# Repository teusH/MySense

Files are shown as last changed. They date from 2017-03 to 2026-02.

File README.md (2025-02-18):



# MySense
Last update of the README on 2nd of Februar 2020

## Description
Software Infrastructure or framework for managing environmental sensors and data aquisition.

This is WORK IN PROGRESS!
All available Python3 scripts/modules are tested standalone as alpha tests and with some real life examples.
In this alpha phase one is recommanded to test and improve the modules before it is taken fully operational.
One is invited to comment on functionality, improvements, and higher level modules to use this library module set.

Be aware that there are discussions going on to change the IoT website query interface and website query implementation of the Samen Meten API.

### Outline
A description of the MySense PyCom based measurement kit, data collection and data visualisation is provided in a presentation at Meetkoppelting20 conference in Amersfoort, Jan 2020. The PDF slides can be found at <a href=""http://behouddeparel.nl/sites/behouddeparel.nl/files/20200125-Koppelting-WAR-Amersfoort.pdf" alt="an How To build a kit and show the results">"Measuring Air Quality in an Agri Region: an How To"</a> (PDF 3 MB).

### Licensing
   Open Source Initiative  https://opensource.org/licenses/RPL-1.5
   Unless explicitly acquired and licensed from Licensor under another
   license, the contents of this file are subject to the Reciprocal Public
   License ("RPL") Version 1.5, or subsequent versions as allowed by the RPL,
   and You may not copy or use this file in either source code or executable
   form, except in compliance with the terms and conditions of the RPL.

   All software distributed under the RPL is provided strictly on an "AS
   IS" basis, WITHOUT WARRANTY OF ANY KIND, EITHER EXPRESS OR IMPLIED, AND
   LICENSOR HEREBY DISCLAIMS ALL SUCH WARRANTIES, INCLUDING WITHOUT
   LIMITATION, ANY WARRANTIES OF MERCHANTABILITY, FITNESS FOR A PARTICULAR
   PURPOSE, QUIET ENJOYMENT, OR NON-INFRINGEMENT. See the RPL for specific
   language governing rights and limitations under the RPL.

### MySense datacollector (Linux systems)
The first station we build with RPi, gas, temperature, RHG and dust sensors looked like this:


MySense is able to act as *air quality measurement kit* or *node broker* (Pi based).
As measurement kit MySense will collect measurements from dust,
gas and/or gas sensors and location sensor,
and forward the data to an external data concentrator(s) (database(s), as well as data broker as eg mosquitto and influx),
files eg spreadsheets,
and display (Adafruit tiny display or console).

As dataconcentrator MySense will connect to other data concentrator instead of collecting the data from sensors.

Two different controllers for the kits are supported:
1. Raspberry Pi for a high degree of functionality and easy block building reasons, while using lan/wifi/G4 as communication channel and
2. ESP32 LoPy controller (micro python) from PyCom when only a very few sensors can be hooked up. This kit uses LoRaWan as communication infrastructure via a public TTN server.
This measurement kit is in beta test since June 2019. The PyCom folder will show latest firmware snapshot.

The bus used for sensors are: USB (Pi: serial), TTL, GPIO (SPI) and I2C.
The scripts are all written in Python 2/3.

Visual feedback is provided with led/button (power On/Off) and optional an Oled display (64X128).

### MySense LoPy-4 PyCom controller




MySense sensor kits can also be applied as *air quality satellite* sensorkits. E.g. using LoPy or WiPy PyCom controllers with GPS, dust and meteo sensors.
In this case the data will be forwarded to <a href="https://www.thethingsnetwork.org/docs/lorawan/">LoRaWan</a> dataconcentrators as eg The Things Network or Mosquitto server.
The LopY has support for SiGFox (due to proprietary chracter of this method it has been deprecated).
The upload of uptaes to the firmware via PyCom OTA is planned.
Currently OTA (Over the Air update) is supported via a new firmware load via wifi.

MySense (Pi based) in data concentrator mode has the possiblity to collect these measurements data from e.g. the TTN MQTT dataconcentrator.

The bus used for sensors are: UART (serial), I2C and GPIO.

The scripts are written in (embedded) micro Python. Micro python has more functionality as the language C e.g. used with Arduino boards.

The Marvin ESP controller has been deprecated due to a problem with on board LoRa antenna in outdoor conditions.

Visual feedback is provided with RGB led and optional an 128X64 oled display.

The LoPy based measurement kit supports to run with a solarcel and accu. For enabling this the architecture has had a major redesign. The softwqare manages accu load as well tries to minimilize energy as much as possible.

The LoRa directory will give information to build a DIY TTN LoRa gateway.

The `INSTALL.sh` RPi configuration script will support to install GPS, oled display, RGB led, WiFi remote access, G4 access and other standard functionality to a Raspberry Pi based gateway e.g. RAK831, RAK833 or IC880a-PSI and Pi based gateway for a small budget TTN gateway.
Have a look at the RAK7258 LoRa gateway. A complete (indoor and outdoor) gateway for about €140 (AliExpress). As such providing you with more functionality as commercial offered gateways without a subscription fee.
If needed use a (€ 40) SIM router to connect the gateway to mobile data access.

At this moment we have 20 measurements MySense LoRa kits in the region running.
Seven kits run with solar cells around a cattle enterprise. The entrepeneur uses the outcome of data to minimize the emissions.

## Goal
Provide a generalised dynamic high quality Open Source based air quality monitoring infrastructure to allow:
* environmental measurements with high end standard off the shelf sensors
* data acquisition
* dynamic transport of data to other data systems: e.g. databases, mosquitto, Influx,...
* data storage and archiving
* access for free visualisation of local emissions
* free availability  of the data
* free availability of all software (under GPLV3 or Open Source reciprocal license, improvements of software remains in the public domain)

The project is run by volunteers on a non-profit basis.

## Supported functionalities
Major functionalities will be added on the fly.
Much is dependent on the quality of the applied sensors and visualisation possibilities of the data.
* supported dust sensors: Nova (only PM2.5, PM10), Plantower (PM1, PM2.5, PM10, counters PM0.3 up to PM10, average grain size, advised), Sensirion (PM1, PM2.5,PM10, counters PM0.3 up to PM10, average grain size, advised).
PM count data is needed to allow a much improved calibration. PM sensors providing only mass values are discouraged. PM sensors (some Plantowers and Sensirion sensors) for outdoor and non condensing conditions are encouraged.
* meteo sensors: Adafruit (DHT: temperature and humidity, deprecated due to humidity problems), Bosh (BME: temperature, humidity, air pressure and air quality), Sensirion (SHT: temperature, humidity). Humidity is a must for calibration of dust measurement.
* TTL or I2C interface to other sensors using standard Grove connectors. Use the standard API to standard product driver via Python. E.g. I2C anemometer, I2C/TTL gas sensors, etc.
* solarcel and battery management (deepsleep and battery low level warning).
* calibration on product base as well on measurement base to enable calibration.
* GPS to support proper localisation. Mobile is supported.
* communication with LAN, Wifi (discouraged due to high failure rate), G4 mobile data, and (TTN) IoT LoRaWan.
* visualisation of the measurements and current status via a display.
* auto detection of connected sensors: plug and play
* remote control and wakeup
* remote OTA update
* dynamic sampling and interval of measurements
* notices based warning system
* visualisation of graphs for (Drupal) website with HighCharts garaphics
* measurement and kist configuration archiving with MySql database.
* scalability
* simple adaptation of new sensors
* modular architecture and high level programming (scripting) to remain state of the art
* stanbard data interfaces (e.g. json, mosquitto, influx)

## Discussion
MySense supports calibration of every single sensor. Sensor values will differ between the sensors within a branche and between branches. Correlation software is included. Advised is to calibrate the sensors regularly for a test period of several days (conditions should vary in the test period).

Dust measurements are done by counting the particles. The most common dust sensor is the Nova SDS011. The Plantower PMSn003 (PMS7003 indoor and PMSx007 outdoor) and Sensirion SPS30 are however 1/3 in size and counts more classes of particles as well provides also the raw (real partical count) values. All have a fan and laser which are powered off in idle state.
The SPS30 is small, use less energy but has air inlet and outlet aside of each other.
Outdoor PM sensors have a higher cost price (2X or even 4X higher).

Dust measurements are (expnential) influenced by humidity.
A correction algorithm to enable to compare the dust measurements with reference sensor equipment (e.g. MetOne BAM-1020) is in beta test (start of 2019).
There is a plan for scientific statistical calibration report together with Uni Leiden, RIVM and Scapeler.
The plan is to be able to forecast PM levels for a short coming period as well.

<div style='vertical-align: top; clear: both'>
<figure>


<br />MySense sensor kits examples

</figure>
</div>
<p>

## How to start MySense on the RPi
* Create MySense user e.g. `ios` and login as this user.
* Install the software on e.g. the Raspberry Pi 3 on a new user e.g. `ios` in the directory e.g. `MySense`. Use `INSTALL.sh` to install all dependencies and startup scripts.
* Configure MySense.conf using MySense.conf.example as a lead.
* Test one by one the input and output scripts in the python debugger as standalone e.g. `pdb MySDS011.py`. Once this is tested, go to the next step.
* command line start and control (<cntrlZ> followed by kill %1 will stop the process): Run Mysense as follows `python MySense.py` and you will see all output on your screen.
* If you use a tiny display: start the display server: `python MyDisplayServer.py start`
* Start as daemon process. Start up MySense: `python MySense.py start`
When first started make sure you configure console output channel, logging to stdout or stderr and logging debug level.

If needed See the README files and documentation files in `docs` for more detailed info.

If you installed a led switch (controlled by `/usr/local/bin/poweroff`:
* Pressing the switch longer as 20 seconds will poweroff the Pi
* Pressing the switch longer as 10 seconds will reboot the Pi
* Pressing the switch 6 seconds will restart a search for wired or wifi internet connectivity.
* If the Pi is powered off a disconnect and connect of the adapter will boot the Pi.

Without internet connectivity the MySense software will not be started on a reboot.

The `@reboot /home/ios/MySense/MyStart.sh` in the ios crontab table will automatically start MySense on a reboot. Comment this out in the test phase.

## Sensor RPi kit case

<div style='vertical-align: top; clear: both'>


The main sensor kit case carrying the Raspberry Pi and all sensor/GPS modules is build from PVC roof gutter pieces: gutter end pieces for keeping the air in and the rain out, and overflow gutter box as casing.
The case has a poweroff button and small window to show a tiny display with current measurements.
The sensors are fixated on a Lego plate to allow flexibility of sensor changes.
</div>
See for a How To: README.case.md
<p>

## RPi MySense Scripts
All scripts are written in Python 2. Python 3 is supported.
The PyCom related scripts are written in micro Python (Python 3).

The RPi scripts have been tested on ARM based Raspberry Pi (2 and 3) running Wheezy, Jessie and Stretch Debian based OS.
Scripts have a -h (help) option. With no arguments the script will be started in interactive mode. Arguments: *start*, *status*, *stop*.
The main script is MySense.py.

The LoRa scripts are tested on PyCom LoPy-4 (an ESP32 based controller with 8MB ram/8MB flash).
The are various device test scripts. The main script is in MySense.py, the runMe(debug=False) script.

### Support RPi scripts
* MyLed.py: control the Pi with button to power off and put it in wifi WPA mode. Pi will set up a wifi access point `MySense` if no internet connectivity could be established via wifi or LAN.
* MyDisplayServer.py, a display service: messages received will be shown on a tiny 128X64 oled (I2C) display.

### Main script
The main python script is MySense.py. It acts as intermediate beween input plugins and output channels. It uses `MySense.conf` (RPi) or Config.py (LoPy).
See MySense.conf.example or Config.py.example to configure the kit yourself.
The MySense configuration file defines all plugins available for the MySense.py main script.

* input (modules) plugins: temperature, dust, etc. sensor device modules and brokers
* RPi: output (modules) channels: console output, (MySQL) database, (CSV/gspread) spreadsheets, and brokers (mosquitto, InFlux, ...).

RPi: Try `./MySense.py --help` to get an overview or LoPy: MySense.runMe(debug=True).

On the RPi command line the option --input and --output plugins can be switched on (all other configured plugins are disabled).

#### operation phases
MySense starts with a configuring phase (options, arguments, reading configuration, loading modules), whereafter in the `readsensors()` (RPi) or main loop (LoPy) routine it will first access the input modules to obtain measurement values, combine them into an internal buffer cache per output channel or LoRaWan, and finally it tries per output channel on the RPi to empty the previously queued records.

The output of sensor values to an output channel or LoRaWan will always on startup to send an identification (meta data) json info record.
Each configurable interval period of time MySense will send (input) measurements values to all enabled output channels.

Rpi:
For each output channel connected via internet MySense will keep a queue in the case the connection will be broken.
If the queue is exceeding memory limits the oldest records in the queue will be deleted first.
If the configured *interval* time is reached it will redo the previous loop.
If switched on and configured an email with identification information will be sent to the configured user.
Make sure one obeys the <a heref="http://nvlpubs.nist.gov/nistpubs/Legacy/SP/nistspecialpublication800-122.pdf">Personally Identifiable Information</a> (PII) privacy rulings.

### RPi Plugin configuration 
MySense.conf is the configuration/init file from which plugin or modules are imported into the MySense process. See the `MySense.conf.example` for all plugins (sections) and the plugin options.

For every plugin module there is an README.plugin with explanations of the input/output plugin.
The input from sensors is read asynchronous (in parallel) via the module MyTHREAD.py.
If needed it can be switched to read only in sync with the other input sensors.

A working example of MySense script in todays operation:
```
          remote access             |  INTERNET (wired/wifi, wifi-G3/4 mobile)
          syst.mgt.     webmin -----||_ wifi AP -- webmin/ssh system mgt
                    ssh tunnel -----||_ BlueTooth -- terminal access
   TeamView/Remot3 (Weaved)IoT -----|
                                    |
                                    |    
    INPUT PLUGINs                   |        OUTPUT CHANNELS    GATEWAY/BROKER
                               | ///|\\\ |
    DHT11/22-meteo ---GPIO --->||       ||>- CSV                _____
    GPS-locator -Uart USB  --->|=MySense=|>- console           ///|\\\  
    RSSI-wifi signal-strength >||  Pi3  ||>- MYSQL           |=MySense=|>-gspread
                               ||Pi ZeroW|
    Dylos-dust -USB-- RS232--->||Stretch||>- Mosquitto pub-->|| Debian||>-MySQL
    Grove-loudness ---GPIO---->||       ||>- HTTP-Post       || Linux ||>-CSV
    BME280 -meteo ---- I2C --->|| ARM   ||>- email info      | \\\|/// |>-console
    BME680 -meteo+gas--I2C --->||       ||                   | server  |
    SHT21/31 - planned-I2C --->| \\\|/// |                   |         |
    PPD42NS -dust-Arduino-USB->|    |    |>- InFlux publish  |_________|>-InFlux pub
    Nova SDS011 -dust -USB --->|    |    |>- oled display SSD1306 (SPI/I2C)
    Plantower PMSn003 -USB --->|    |    |>- Google gspread (alpha, deprecated)
    Sensirion SPS30   -USB --->|    |    |   (see LoPy Feb 2019)
    O3,NO2,CO SPEC UART USB -->|    |    |   (beta test April 2018)
    NH3 - AlphaSense - I2C --->|    |    |   (planned Jun 2018)
    Adafruit rain -----GPIO -->|    |    |   (planned Aug 2018)
                               |    |    |    
    LoRaWan (TTN MQTT) ------->|    |    |>- broker? (planned)
    Mosquitto sub ----server ->|    |    |>- LoRaWan (planned TTN)
    InFlux subscribe -server ->|    |    |>- Bluetooth (planned)
    LoRa TTN MQTT ----server ->|    |    |>- Luftdaten.info databases
                                    |
                                    |>-raw measurement values -> InFlux server or file
                                           calibration
```



MySense LoRa air quality measurement kit:
```
          Arduino/Atom/Makr WiFi/USB --|-- WiFi / BlueTooth
                                    ___-__________
    DHT11/22-meteo ---GPIO---->|   /               \
    BME680 -meteo+gas--I2C --->|= <  PyCom LoPy     >|-LoRa TTN MQTT >-< MySense >
    BME280 - meteo ----I2C --->|   | PyCom WiPy     >|-SigFox IoT (planned)
                                   | (Marvin)        |                 
    Nova SDS011 -dust -Uart -->|   \ ESP8266       /
    Plantower PMS7003 -Uart -->|    --------------
    Sensirion SPS30 ---Uart -->|
    Grove GPS ---------Uart -->|       |
                               |       |
    commands - LoRA TTN     -->|       |
                               |       |
    solarcel power switching<->|       |> SSD1306 128X64 oled display
```
LoRa TTN server is also used e.g. to change sample/interval timings, to force information, (dis)enable display, stop processing, or enable wifi AP of the kit for updates, etc to be sent to the MySense LoRa sensor kit.

## Configuration
### Configuration of MySense RPi
See `MySense.conf.example for an example of `MySense.conf`.

Use for configuration of plugins/outputchannels the `section` (plugin name in lowercase) and section options.
The option `input = True or False` and `output = T/F` will define resp input plugin and output channel
to be imported and to be switched on or off.
Input plugins as for gas and dust (particle counts) will have a configurable sample time (time to get vales) and interval time (time (interval minus sample) to wait before the next sample).
The MySense main loop has an own `interval` time within input plugin sensor values will be collected (sliding average from sample values) and push values to output channels.

### Configuration of MySense LoRa kit (LoPy or WiPy)
See for an example the file `Config.py`. Make sure useXXX and the *pins* are defined and wired correctly.
Change WiFi AP ssid/password to your will.

## Interaction data format
Interaction with plugins and output channels is done in json datastructure:
Example of json to display a measurement on the console (and others):
```javascript
     { "time": UNIXtimeStamp,
        "temp": 23.2,
        "rh": 30.2,
        "pm": 234.2,
        "o3": None }
```

At the startup RPi MySense.py will start with an identification record providing details of the version, the location if available, a unique identifier, sensor types and measurement unit, etc.
This information will define eg the first row of a spreadsheet or the database table with all sensor info (called Sensors).

Towards a broker the output will consist of an (updated e.g. GPS location) combination of the data json record and the infomration json record:
```javascript
    { "ident": id-record, "data": data-record }
```
See for an example the file: `testdata/Output_test_data.py`

The input sensor plugins provide (sliding window of a per plug definable buffer size)) averages in a per input plugin defined interval time in seconds. The output is done on a general interval period timing using the average time of input timings.

Typical input rate from a sensor is 60 seconds (can be tuned) and for brokers it is 60 minute interval (can be tuned).

## Brokers
MySense can act either *sensor manager* or as *input from broker manager* to a set (dynamic) of output channels. 

Available input plugins:
* Dust: Dylos DC1100 or 1700 via serial interface, Shinyei GPIO (e.g. Grove dust sensor), Nova SDS011, Plantower PMS5003/7003/x003, Sensirion SPS30.
* Temperature/humidity: Adafruit DHT11/22, AM3202 and Grove variants, Bosch BME280 or BME680 (has indoor aq gas sensor), Sensirion SHT31-D.
* RSSI (strength of wifi signal): via the platform
* Location: GPS (GPS Ultimate from Adafruit/Grove) via TTL serial interface

To Do: SHT31 and others one can heat the chip up e.g. on high humidity. Or use temp alert.

## Remote management
The Pi allows to install a wifi connectivity with internet as well a virtual wifi Access Point. A backdoor configuration is provided via direct access to `webmin` and `ssh` (Putty), as well via a proxy as *ssh tunneling* and/or using the proxy service of Weaved (`https://www.remot3.it/web/index.html`).

If no access to Internet either via LAN or WiFi is obtained a WiFi AccessPoint is started (SSID MySense-XYZ, and default password) which enable you to use `ssh ios@192.168.2.1` command to obtain shell access. Correct in `/etc/wpa_supplicant/wpa_supplicant.conf` the SSID and psk password phrase to your local access point.

## Hardware Platform
Sensors have a hardware interface to I2C, GPIO: those sensors are tested on RaspBerry Pi (and Arduino Uno)
Sensors with USB serial are tested on Linux Debian platforms which run Python.

The GrovePi+ shield is used to ease hardware installation by just using 4-wired connectors and avoid mistakes. No soldiering, nor DuPont wires which are easily get disconnected. The GrovePi+ shield has 3 I2C connectors.I2C connectors are all in parallel. Use eg a Grove I2C 4-port connector to extent the amount if needed.

Install GrovePi+ Dexter libraries as user *pi* with the following command:
```bash
    curl -kL dexterindustries.com/update_grovepi | bash
```
and reboot/poweroff the pi. Install the shield and proceed.

We use small USB cables with a 90 degrees connector and/or USB hub with 4 USB connectors with 10-15 cm wires to ease fixation of the wiring. As well use a Lego board and Lego stones to fixate all modules and sensors on the Lego board.

## Installation
See README.pi for installation of the Raspberry Pi platform.
MySense plugins: Use the shell file `INSTALL.sh [DHT GPS DB plugin ...]` to download all dependent modules.

The sensor plugins, and output modules can be tested in *standalone mode*, e.g. for BME280 Bosch chip, use `python MyBME280.py`. Or use the Python debugger `pdb` in stead. See the script for the use of sync and debug options at the end of the script to test.

If the Pi supports BlueTooth one could also use BlueTooth terminal access by installing BlueTooth terminal service: `./INSTALL.sh BLUETOOTH`. This type of accesss is not recommanded.

## Documentation
See the README's and docs directory for descriptions how to prepair the HW, python software and Pi OS for the different modules.

`CONTENT.md` will give an overview of the files and short description.

## Operation status
See the various README/docs directory for the plugin's and modules for the status of operation, development status, or investigation.

Failures on internet connectivity and so retries of access is provided.

## Extensive test support
Use the following first if one uses MySense for the first time: test each sensor input or output channel one at a time first.
Use the Conf dictionary to set configuration for the test of the module.

The sensor plugin as well the output pugin channels *all* have a `__main__` test loop in the script.
This enables one to test each plugin (one at a time) in standalone modus: `pdb MyPLUGIN.py`.
Use for the sensor input plugins `Conf['sync']=False` (to disable multithreading) and switch debug on: `Conf['debug']=True`.
Set the python debugger `pdb` to break on `break getdata` (input plugin) or `break publish` for stepping through the script. Failures in configuration are shown in this way easily.

After you have tested the needed input/output modules: To test the central script `MySense.py` use first the Python debugger `pdb`. The main routine after the initiation and configuration phase is `sensorread`, in `pdb` use `break sensorread`. Continue to this break point and use `print Conf` to show you the configuration settings. Step to the first `getdata` call or `publish` call to go into the input or output module.
Note that the `getdata()` input routine may need some time in order to allow the module to collect measurement(s) from the sensor.

## Current development focus

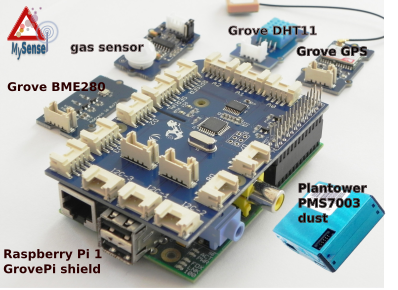
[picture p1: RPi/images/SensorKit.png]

The MySense framework/infrastructure is operational as lab test model (beta phase).

By default Rpi and LoRa MySense uses a so called lightweight process (multithreaded) to allow sensor data to be collected asynchronously.
Input is tested with serial, I2C-bus and GPIO sensors (meteo,dust,geo,audio, (gas in September 2017).
The focus is to allow Grove based sensors (easier to plugin to the MySense system) and weather resistent cases for the system.

The gas sensor development (NO2, O3, NH3, CO) is just (Febr 2017) started, Aug 2017 alpha tests.
Due to limited finances the gas sensor development has been postponed. There is for the RPi limited support for ALphaSense (NH3) and Spec (O3, NO2, COx, NOx) USB gas sensors.

## Calibration
Calibration of dust counters like Shinyei, Nova SDS011 and Dylos is started in May/June 2017.
Outdoor correlation tests started Sept 2017.
Indoor calibration tests with Plantower PMS7003, Nova SDS011 and BME280/BME680 were done in April 2018.
Outdoor calibration is due in spring 2019.

The use of the DHT22 has been deprecated after a 3 month period beginning of 2018 with 10 sensots kits equipted with Marvin LoRa/DHT22/SDS011 sensors.
The DHT22 differ too much from one to the other are much influenced by higher rel. humidity. As well the I2C bus (e.g. BME280) seems more reliable and is easier to use.
Due to higher rel. humidity the Marvin LoRa antenna was defective after ca 6 months.
The application of the LoRa Marvin controller has been deprecated.

All laser dust sensors are exponential influenced by rel. humidity of 80% and higher: exponential overestimating dust counts.
In study with RIVM and an initiative in Berghaven (Nld) is a recalculation scheme to correct the values.
We hope to get some research done to improve the calibration algorithm.
The Plantower and Sensirion dust sensors provide also the raw particle counts. This will be used to calibrate these sensors. Report is due in spring 2019 or later.

Calibration of Alpha Sense gas sensors is a problematic area. Probably Sept 2017. First tests show Alpha Sense O3, CO2 are OK, NO2 not successfull, NH3 prosponed.

To facilitate measurements for calibration purposes all sensor plugins are optionaly (set `raw` option to `True` for the particular sensor in `MySense.conf` (RPi) or `Config.py` (LoRa)) able to output on file or to e.g. on the RPi an InFlux DB server the *raw* measurements values, as follows:
```
    raw,sensor=<type> <field1>=<value1>,<field2>=<value2>,... <nano timestamp>
```
This is an InFlux type of telegram, where the UNIX timestamp is in nano seconds. Example for database BdP_02345pa0:
```
    raw,sensor=bme280 temp=25.4,rh=35.6,pha=1024 1496503325005000
    raw,sensor=dylos pm25=250,pm10=15 1496503325045000
```
E.g. on the RPi download the *serie* for eg correlation calculation from this server or into a CVS file (`awk` maybe your friend in this).
Or use a file, say `MyMeasurements_BdP_02345pa0.influx`.
```shell
    # send the file to the InFluxdb server via e.g.
    curl -i -XPOST 'http://localhost:8086/write?db=BdP_02345pa0&u=myname&p=acacadabra' --data-binary @MyMeasurements_BdP_02345pa0.influx
```
InFlux query reference manual:
* https://docs.influxdata.com/influxdb/v1.2/query_language/

Using the Influx CLI (command line interface) one is able to convert the columnized output into whatever format, e.g. to CSV:
```
    influx --format csv | tee InFlux.csv
    >auth myname acacadabra
    >use db_name
    >show series
    >select * from raw order by time desc limit 1
    >select * from raw where time > now() - 2d and time < now() - 1d order by time desc
    >quit
```

After the correlation calculation set for the sensor the `calibration` option: e.g. `calibration=[[25.3,-0.5],[13.5,63.203,0.005]]` for here two fields with a linear regression: `<calibrated value> = 25.3 - 0.5 * <measured value>` for the first field values. The second field has a 2-order polynomial as calibration.

To avoid *outliers* the MySense input multi threading module will maintain a sliding average of a window using the buffersize and interval as window parameters. Python numpa is used to delete the outliers in this window. The parameters for this filtering technique are default set to a spread interval of 25% (minPerc MyThreading class parameter)) - 75% (maxPerc). Set the parameters to 0% and 100% to disable outlier filtering. Set busize to 1 to disable sliding average calculation of the measurements.

### Calibration tool
For calibration the Python tool `statistics/Calibration.py` has been developped. The script uses pyplot and is based on numpy (numeric analyses library). The calibration uses values from two or more database columns, or (XLSX) spreadsheets, or CSV files as input and provides a best fit polynomial (dflt order 1/linear), the R square and shows the scattered plot and best fit graph to visualize the difference between the sensors. Make sure to use a long period of measurements in a fluctuating environment (a fixed indoor temperature measurement comparison between two temp sensors does not make much sense).

### Test remarks and experience

#### meteo
The DHT meteo sensors show intermittant lots of read errors. The DHT is deprecated.
Humidity: outdoor use of the sensor will show after a while 99.5% rel. humidity all the time. Allow the sensor to dry.
The meteo sensor BME280/680 might be a better alternative. Tests show a linear correlation between this sensor and the DHT. However the chip seems to build up heat and shows a higher temperature as it should be. Airpressure seems very reliable. The current focus however is on the Sensirion SHT31 chip. Which has promissing specifications.

Calibration test results (April 2018) with 3 sensor kits, indoor (temperature and humidity does not vay much) test of 32 weeks with 5 minute samples:
1. reference kit with BME680
2. BME680:
    * gas R2=0.85, correction 3.192e2, 5.650e-1 (56% of ref BME680)
    * temp R2=0.843, correction -4.703, 8.528e-1 (85% of ref BME680)
    * humidity R2= 0.972, correction -2.99e0, 0.519e-1 (5% of ref BME680!)
    * pressure R2=0.99, correction 1.238e1, 9.820e-1 (-2%)
3. BME280:
    * temp R2=0.98, correction -1.662e0, 9.310e-1 (93% of ref BME680)
    * humidity R2=0.625, correction -4.824e0, 1.404e0 (14 X BME680!)
    * pressure R2=0.9779, correction 1.291e2, 8.753e-1 (only an offset, -13% of ref)
In short: air pressure values correlate fine (high R2) and need some correction. R2 for temperature and humidity are just ok. But the SDS011 need corrections to the BME680. Previous tests with DHT22 show a far lower R2 and higher (linear) corrections.

#### dust
The Shiney PPD42NS (tested 3 sensors) gave lots of null reading on low PM10 values. The sensor values are not stable enough in comparison with newer sensors from Nova and Plantower as well the bulky Dylos handhelt.

Due to airflow the sensors need to be cleaned periodically. The Plantower sensor is hard to clean as it cannot be opened.

Plantower dust sensor measures also PM0.3, PM0.5, PM1 and PM5 as PM counts.

Both Plantower and Nova dust sensors use USB bus. The values are provided in mass values. The conversion from particle count to mass is not made public. 

All these PM counting based sensors show an exponential overcalculated value on higher rel. humidity. Research is going on to correct it to values which are compatible with e.g. BAM1020 reference sensors.

Calibration test results (April 2018) with 3 sensor kits, indoor test of 2 weeks with 5 minute samples:
1. reference kit with PMS7003
2. PMS7003:
    * PM0.1 R2=0.9664, correction 8.635e-3, 1.096e0 (no difference)
    * PM2.5 R2=0.9638, correction 5.626e-1, 1.092e0 (no difference)
    * PM10  R2=0.9564, correction 6.630e-1, 1.174e0 (not much difference)
3. SDS011:
    * PM2.5 R2=0.9473, correction -5.141e-1, 2.615e0 (ca twice PMS7003)
    * PM10  R2=0.8805, correction 8.967e-1, 2.704e0 (ca twice PMS7003)
In short: about no difference (high R2), correction between the Plantower is about none (PM0.1 1%, PM2.5 1%, PM10 17%). Plantower with Nova SDS011 differ not much (high R2), correction is linear (PM2.5 260%, PM10 270%).

#### gas
Tghe Alpha Sense gas sensors have a high cost level (ca 80 euro per gas). NH3 is hard to test and still planned. NO2 give too many errors in the field. The sensors have a very limited time.

#### GPS
The Grove GPS sensors is applied via USB bus connection and the standard Debian GPS deamon. The location is not precise enough. The wait is for the Galileo GPS sensors availability.

#### Raspberry Pi
The tests are done with the Raspberry Pi 3. With the GrovePi+ shield and the big V5/2.5A adapter it gets bulky. The new Raspberry Pi Zero V1.3 is half size, uses far less power and costs only 25% of the Pi3.
We expect the Zero might be more applicable.
The Raspberry Pi is using WiFi as data communication channel.
Due to communication reliability the current focus is to use LoRaWan as communication channel. Which is less easy and pricing wise to apply with a Pi.

### PyCom LoPy-4
The LoPy-4 of PyCom is used as controller for situations where LoRaWan can be used and wireless distances are needed beyond 30 meters up to 2.5km. The main focus currently is to use a LoPy-4 in the measurements kit. Currently there are about 35 measurement kits operational. 50% is powered from solar panels.

## Costs
There is no funding (costs and development time is above personal budget level).
Costs at start are high due to failures on tests of common sensors (Arduino is skipped due to too low level of functionality; Shiney and DHT sesnors failures, application of smaller adaptors, Marvin controller is skipped due to humidity problems, etc.).
Money is lacking for sensors research and travel expenses coverage to meet other initiatives.

July 2017: local government is asked to subsidy operational phase: distribution of sensors kits and maintenance.
They refused ('there are other initiatives'). A neighboring local government seems to be willing to sponsor. A technical high school has started now a second project with MySense.

July 2019: LoPy-4 based measurement kit have a hardware costs of about 150 euro. With solar the costs are about 200 euro (solar panel and regulator).

## Licensing:
FSF GPLV4. All improvements and additions should remain in the public domain.
Feedback of improvements, or extentions to the software are required.
* Copyright: Teus Hagen, ver. Behoud de Parel, the Netherlands, 2017-2020.

If any part is used in a commercial setting has to contribute to this project
in either financial, code, or other ways and mention MySense in the product or service based
on any part of this MySense project information.

## References
At a Koppelting conference we explained how to build the measurment kit and how to visualize the data. A PDF of this presentation:  <a href=""http://behouddeparel.nl/sites/behouddeparel.nl/files/20200125-Koppelting-WAR-Amersfoort.pdf" alt="an How To build a kit and show the results">"Measuring Air Quality in an Agri Region: an How To"</a>.

There is a huge list of literature available on the web. Some project were financed by the European Union. However we were not able to use there current developemnt due to the closed nature.
A list of references for the documentation and/or code used in MySense.py:
* Open Data Stuttgart ESP8266 controller oriented: https://github.com/opendata-stuttgart
* MIT Clairity CEE Senior Capstone Project report V1 dd 15-05-14
* https://www.challenge.gov/challenge/smart-city-air-challenge/ Smart City Air Challenge (2016, USA GOV)
See also: https://developer.epa.gov/air-pollution/
* http://opensense.epfl.ch/wiki/index.php/OpenSense_2
* http://mysensors.org
* http://opensensors.io
* http://mydevices.org (Cayenne)
* https://waag.org/nl/project/urban-airq Waag Society Amsterdam Smart Citizens Lab Urban AirQ
* http://www.citi-sense.eu/ Citi-Sense EU project
* http://waag.org/nl/project/smart-citizen-kit Smart-Citizen-Kit Waag Society
* http://smartemission.ruhosting.nl/ Smart Emission, Maps 4 Society Nijmegen
* https://github.com/guyzmo/polluxnzcity Pollux NZcity, NZ
* https://github.com/HabitatMap/AirCastingAndroidClient AirCasting on Android Client
* https://mosquitto.org/ Mosquitto (MQTT) broker
* https://docs.influxdata.com/influxdb/v1.2/ documentation from InFluxData.com
* https://cdn.hackaday.io/files/21912937483008/Thomas_Portable_Air_Quality.pdf interesting overview of sensors

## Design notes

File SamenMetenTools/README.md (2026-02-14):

# MySense Samen Meten Tools
Last update of the README on 17th Februari 2025

## Description
Python toolset to allow air quaility data analistics on measurements generated by low-cost (DIY) stations.
This is **WORK IN PROGRESS!**, inspired by the Samen Meten Tools from a Samen Meten Zuinige Rijder (Rick).
Current (first) module is to provide a Python engine to obtain meta stations information in Python dict format and sensor observation data over a period of time in Python Pandas format for processing these website queries results by other tooling.

One is invited to check the implementation, improve functions, add archiving functions, improve performance or suggest usage functions.

The current state is the core interface to Samen Meten website API query interface (version 1.1), archiving measurement data in different formats like (gzipped) json (need standardisation efforts), (gzipped) CSV format, XSLX spreadsheet (gzipped) format and HTML interactive map webpage with detailed regional (DIY) measurement station information. 
To Do: One is invited to add functionality to add governmental station info to the SamenMetenThgings.py module.

The goal is to add a data analyse layer: data validation, data correction, data calibration, data analisation report generator, and data visualisation (interactive heatmaps?) based on the lower level (website query, archived information and archived measure) library modules.

The scripts will use various command line options, defined as XYZ=value:
- non optional argument names are either file names, regional names, station names, GPS location.
- **Verbosity**=n level, input/output **File**=name, **DEBUG**, compression method, delimeter char, test data only, etc.
- Filtering options:
  - **Sensors**='pm10,pm25,pm10_kal,pm25_kal,temp,rh,no2,o3,co2,nh3' or reg.exp to focus on these sensors only.
  - **Expand**='location,address,owner,project' to expand (a table join) db table domains.
  - **Select**='' (default all) to filter station names. Use regular expression.

Use CLI **python3 ScriptName.py help** option to get more information about the use of CLI options.

## Samen Meten Things tools architecture

SamenMetenArchitecture

The Python3 (>= version 3.8) scripts/modules carry an extensive amount of documentation and comments. This may help you to answer the question 'how did they do it?' and use of API interface standards. Read thye source to get an impression of which Python (import) library modules are being used.

## Outline of modules
### needed Python library modules
Various not standard Python modules are used in the scripts:
- xlsxwriter
- pandas
- dateparser
- aiohttp
- tzlocal
- dateutil
- folium
- pygeohash

  Install them with e.g. apt -y install module_name.
  For easy search for neighbours geohashing is used. E.g. the module cgeohashing. One has to install it via pip3. Or use an own Python module.

## Example of CLI script use
For test purpuses as long as the architecture of the tools is notr ready yet, one can use the follwing CLI commands to get a map with measurement stations in a village.

First get an archive in CSV format for a period of time:
  **python3 Things2CSV.py Expand='location,address,owner,project' Sensors='(pm25|pm10)' Period='2018-01-01,now' Verbosity=2 User='MySense' File='Leidschendam-Voorburg.csv' 'Leidschendam-Voorburg'**
This will take about 5 minutes per region. More regions can be added on the command line end.

Second to generate the HTML map with Things stations:
  **python3 Things2HTML.py Leidschendam-Voorburg.csv**
This will generate the file Regions\ Leidschendam-Voorburg.html
  
### SamenMetenThings.py
The Samen Meten Things module provides a python interface to the RIVM Things API (an API) and various other website query services like Open Data Soft (CBS queries e.g. municipality id numbers) and Open Street Map (addresses of stations). The GPS location resolution is about 100 meters (3 decimals).
The main routines are able to collect meta information (status information of the station, installed sensors and sensor types, period of availability, location, address, citizen reference stations), neighbouring stations, stations in a municipality of near a GPS location) and observation data in a period of time, all in Pandas (dataframe series) format.
All the routines can be called as standalone (CLI) for test purposes.

The module is operating in multiprocessing modus. This gives a factor of 2-5 of speedup.
E.g. one website query can take 2-30 seconds (usualy 15 seconds). To obtain info about one sensor of a station it takes about 2 information requests, followed by 1 observation requests per sensor. The common station has about 4-6 sensors. A municipality has about 100 stations. This gives you about: 100 X (2 X 5 X 6) X 15 seconds if request are done sequently.

The current modules are in alpha status and subjected to improvements and need to be extented with more or better functionality. In other words: help!

The module consists about of 50% of documentation and have a 'help' function for CLI usage. The modules gives you a good overview of backgrounds of the website query interfaces and how to use Samen Meten tools and interfaces.
So read the module script!

Example output file: Real life regional stations overview (gzipped json format) is 'Land van Cuijk.json.gz'. Generation took about 1 hour to generate (111 low-cost stations with different sensors installed).
Most of the time was spend waitinmg on Things queries results. *Conclusion*: use local archived data as much as possible.

### Things2XLSX.py
Things2XLSX will generate XLSX spreadsheet with overview of Things station names, location (GPS, address),
station properties (owner, project, gemcode, reference station codes),
and operational data of installed sensors (type, first and last timestamps, record count).
The spreadsheets will show per sheet the historical and current stations information.
Station names will be in color to denote active states (red: station not active in the period, orange: lately not active, black: active).

Example of generated output file for region Land van Cuijk is 'Land van Cuijk.xlsx'.

The script uses municipality stations routine of the SamenMetenThings class module.

### Things2HTML.py
Things2HTML will generate an interactive (Python Folium is used) Open Streep Map with regional low-cost station location markers.
Clicking a marker will show information of installed sensors and operational timings. The chart is interactive.
The goal is to present heatmaps of measurements as well of PM calibrated (temperature and RH) measurements.
The generated HTML can be include on your website via e.g. <iframe src=HTMLfile>.

The file 'Land van Cuijk.html' is a real life example of a generated HTML interactive map page for an overview of Samen Meten stations in the region Land van Cuijk in Holland. Which can be visualised via a browser.

### Things2CSV.py
Things2CSV will generate a CSV file from station information obtained from JSON (one dimensional or multi dymensional) dict or downloaded regional stations information via Samen Meten API (SamenMetenTools.py) as comma separated file (default delimeter ';'). Content structure is:
1. comment lines, start with '#' char, with file properties as e.g. owner, version, project, title, subject, etc.
2. column header line with column names in either human readable format, or Things standard naming.
3. station info lines, default ';' char separated.

Generated file maybe gzipped compressed. Example of generated CSV file is 'test-stations.csv' (generated from 'test-stations.json.gz).

### ThingsArchive.py
This module will await completion of alpha tests of other modules.

This script a a wrapper for XLSX, HTML map, CSV (+compressed), and JSON (+compressed).
Input can be regional names (Samen Meten Things website will be used to download data), various file formats.
The central archive will use Python Pandas dataframe format.

## Licensing
   Open Source Initiative  https://opensource.org/licenses/RPL-1.5
   Unless explicitly acquired and licensed from Licensor under another
   license, the contents of this file are subject to the Reciprocal Public
   License ("RPL") Version 1.5, or subsequent versions as allowed by the RPL,
   and You may not copy or use this file in either source code or executable
   form, except in compliance with the terms and conditions of the RPL.

   All software distributed under the RPL is provided strictly on an "AS
   IS" basis, WITHOUT WARRANTY OF ANY KIND, EITHER EXPRESS OR IMPLIED, AND
   LICENSOR HEREBY DISCLAIMS ALL SUCH WARRANTIES, INCLUDING WITHOUT
   LIMITATION, ANY WARRANTIES OF MERCHANTABILITY, FITNESS FOR A PARTICULAR
   PURPOSE, QUIET ENJOYMENT, OR NON-INFRINGEMENT. See the RPL for specific
   language governing rights and limitations under the RPL.

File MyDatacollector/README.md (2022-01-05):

# MyDatacollectornapplication
## An outline of the data aquisition, monitoring, eventhandling and adatforwarder
MyDatacollector is a Python application to run as a deamon service downloading measurement data from (MQTT) brokers, monitoring the measurement kit operations, handling measurement kit events, while sending event notices via email or chat service (Slack), updating meta information of the measurement kits and forwarding the data to a collection of output channels as terminal console, measurement database, and different data portales as Sensors.Community, RIVM etc.

## license
Contact Teus Hagen webmaster@behouddeparel.nl to report improvements and bugs

Copyright (C) 2021, Behoud de Parel, Teus Hagen, the Netherlands
Open Source Initiative  https://opensource.org/licenses/RPL-1.5

   Unless explicitly acquired and licensed from Licensor under another
   license, the contents of this file are subject to the Reciprocal Public
   License ("RPL") Version 1.5, or subsequent versions as allowed by the RPL,
   and You may not copy or use this file in either source code or executable
   form, except in compliance with the terms and conditions of the RPL.

   All software distributed under the RPL is provided strictly on an "AS
   IS" basis, WITHOUT WARRANTY OF ANY KIND, EITHER EXPRESS OR IMPLIED, AND
   LICENSOR HEREBY DISCLAIMS ALL SUCH WARRANTIES, INCLUDING WITHOUT
   LIMITATION, ANY WARRANTIES OF MERCHANTABILITY, FITNESS FOR A PARTICULAR
   PURPOSE, QUIET ENJOYMENT, OR NON-INFRINGEMENT. See the RPL for specific
  language governing rights and limitations under the RPL.

Use of all sources under these condition implies a contribution in the form of code contribution, documentation, improvements or donations to MySense.
It is not a free beer.

## configuration
The datacollector and input/output modules are highly configurable.
See the Python module for e.g. Conf dict for all details.
Every input/output module can be tested on a stand alone base which eases testing and debugging. A set of examples is provided for this.
The (default) init file (MyDatacollector.conf.json, see MyDatacollector.conf.json.example) defines a lot of configuration defaults.
The database access information e.g. MySQL credentials for the tables) is taken from the init file. Database credentials may be taken from environment variables (e.g. DBPASS=acacadabra, DBHOST=localhost, DBUSER=myself)
when the configuration item 'MyDB' in the init file is undefined.
Broker access information has to be defined via the init file.

From the command line one is able to redefine e.g. inputr and output channels.
E.g. 'community:output=false' will switch forwarding to Sensors.Community OFF.

## input channels (broker input channel modules)
It is possible to read measurement data from several (MQTT eg TTN V2 or V3 stack) simultaniously. The datacollector is able to detect data in TTN V2 or V3 automatically. Currently only MQTT broker input is implemented. With this as example eg InfluxDB or HTTP POST broker should be easily implemented.
To allow input from raw MQTT data e.g. commandline mqttclient application the datacollector is able to read data from several file(s): use file=file_name as CLI argument.

On (MQTT) broker connection problems the datacolelctor will try to reconnect and will send an event email on too many errors. If needed it will slow down the reconnecvt or in the end give that input channel up.

MyMQTTclient module is taking care of uploading measurement data from an MQTT broker (TTN V2 and/or V3 TTN broker) as well restore of MQTT data from a file. The module will use MyLoRaCode module to decode raw LoRa payloads with decode LoRa engine rules.
It is expected that every LoRa port has it's own decoding rules. See the comments in this module for more details.
The LoRa (TTN V2/V3) json format will be converted to the (internal) Measurement Data Echange Format (MDEF format). The internal MDEF format is very close to the proposed (MySense) MDEF standard proposal.

The MyMQTTclient modue will try to automatically reconnect. On too many reconnects the MQTT broker will be disconnected. If no input channels are available anymore the data collector will exiting.

## output channels
Measurement data is forwarded via a dynamic configurable scheme of output channel modules as MyARCHIVE (MySense MySQL database), MyCONSOLE (terminal/console), and/or MyCOMMUNITY (Sensors.community, RIVM and other data portals).
As Sensors.community does not calibrate dust data from different dust sensor manufacturers, if possible the dust data is corrected via a regression scheme (measurements from 3 different dust sensors over a period of half a year in 2020) to the sensors from Sensirion. If needed a simple configuration change it can be switched of or to use a different sensor type. See Conf dict in MyCOMMUNITY module for more details.

The MySQL database (luchtmetingen) has for every measurement kit a measurement table 'project_serial'. If the kit is set 'active' (see meta data section Sensors table) the table will be automatically created and will have so called 'field's for every sensor field it encounters. Fields or columns are automaitcally added on the fly. Every measurement entry will have an id, timestamp, field(s), field validation (None if kist is in repair), and 'sensors' (senor type names configured in the kit).
Project name and kit serial id are defining the reference id used in other (meta) database tables.

The output channel modules API is done via the module 'publish' routine.
Routine arguments:
- meta information (datagram count, sensor types, correction/calibration info, measurement unit info and id: project/serial). See the module for MDEF details and examples.
- data or measurement record. Example of MDEF format: `{"SHT31": [("temp",11.3,"C"),...]}'
- artifacts list encountered by the data collector as eg "Forward data", malfunctioning sensors, out of band values, static values, etc.

The datacollector uses a field name translation configuration tabel to translate sensor field names to the fields names as used in the MySQL database. E.g. translate 'temperature' to 'temp', 'RH' to 'rv', 'pressure' to 'luchtdruk', etc. Fields names are case independent.

## meta measurement kit data
The MySQL database has a few tables to describe meta data for each measurement kit:
- 'Sensors': table with project/serial id's, location, sensor types configuration, operational info (active, in repair). The datacollector will complete info as eg geohash information, street, village, in repair when location if not the homelocation, installation home location, etc. on the fly. The datacollector uses a write throug cache to avoid too many accesses to the database server.
- 'TTNtable': table with forwarding information to database, portals and project/serial match with TTN topic/device id.
- 'SensorTypes': table with information about different sensor types of sensor manufacturers, sensor names, sensor correction

The meta in formation uses MDEF format. For details and examples see MyDatacollector.

The MySQL tables 'Sensors' and 'TTNtable' are initialy created when needed. However do not have meta data at that time. In order to update these table with meta measurement kit information the Python script 'MyAdmin.py' is provided. The script needs as input a json file with basic information. If needed the script will complete eg location information from other info in the json input file. E.g. from longitude and latitude the street, village, etc information is obtained via internet search.

The bash script 'MyDB-upgrade.sh' is a scriot which will upgrade the MYSQL database to a newer release. E.g. support of sensor types, SensorTypes DB table, geohash, etc.

## kit location handling
Data record optionaly may have kit location GPS information. This information is converted to a geohash (precision up to 12) string.
Meta kit information typically sent via eg LoRaWan port 3, will eventually carry geohash updates.
If the measurement record has GPS location this information will also be used to update home location if needed and/or detect the removal of the kit from the home location.
In the latter case measurements will be marked to indicate that measurements come from a different location.
The mark will be reset if the kit returns to the home location.
The so called kit `home location` information will be updated in the `Sensors` database table if this is missing information (initial state of the kit).

If the location can be guessed from nearby gateway information this information is handled as well. The guessed info needs to be improved.

If sensor measurements do not originate from the `home location` the measurments may not be handled by some forwarding output channel modules as e.g. Sensors.Community, website graphics, etc.
As this improves the reality of measurements of the kit locations.

## monitoring
Default the MyDatacollector the monitor output is switch ON (monitor:output=true).
On standard error output monitoring (global processing) information will be supplied.
Information about timestamp, measurement kit name, sensor types in the datagram and result of data forwarding.

## notices mechanism
By default notices via email or chat notices service (eg Slack) will be active (notices:output=true).
Notices are about events, malfunctioning sensors, measurement faults (dead for more as 2 hours) to the 'owner', project manager, and operational manager.

## event handling
A measurement kit kan generate an event (low accu level, watchdog event, programming error, etc). The event number is translated to a name and priority. All events are logged. Priority will decide if a notice is generated as well. Event handling cannot be switched off.
Note that a measurement kit can remotely via LoRa be instructed for configuration change or even be switched off. This event will be received by the datacollector as well.

## logging
Default logging output (priority driven: info, ..., debug) is on standard error terminal. Configuration allow to forward logging to the OS syslog system, or even for remore simple access to a named pipe.
It is possible to configure each module with a different priority level.
One can configure via Conf['file'] the way logging is done: sys.stderr.write, syslog, name pipe, or a logfile.

## LoRaWan gateway statistics
The datacollector will maintain information of gateways involeved with uploading kit measurements.

## upgrading DB
MyDatacollector is dependent on meta information and measurement data tables.
These tables have had some changes in supported tables fields/columns. 
To update the elder DB please use the bash update script.

The MyAdmin script needs some update to the newer table schemes yet.

Measurement data is visualised via a CMS Drupal website. Drupal uses it's own database tables. So this type of tables need to be synchronised for meta information (locality etc). For this the script 'SyncWebDB.py' has been made available. However this script needs still to be upgraded with the newer DB table architecture yet.
The tables 'Sensors' and TTNtable' are still the main single source for the information.

## Python standard modules
You should be able to run the scripts on Python 2 or 3.

Make sure you have installed the Python modules.
Usualy the system standard modules are installed.  The modules dateutil.parser, jsmin, mysql.connector and paho.mqtt.client has to be installed.
From which jsmin, paho.mqtt.client and mysqwl.connector are not supported in the last Debian distributions anymore.
Geohash module: use 'pip install pygeohash' if needed so.
Try this by using the following Python script.
` Python -e '
import atexit
import base64
import copy
import datetime
import dateutil
import email.mime
try: import pygeohash
except: import geohash # if not use copy python3 module
import geopy
import inspect
import jsmin
import json
import lib
import logging
import math
import mysql
import os
import paho.mqtt
import platform
try: import queue
except: import Queue
import random
import re
import requests 
import signal
import smtplib
import socket
import struct
import subprocess
import sys
import threading
import time
import traceback
import xtermcolor
'
`
An example to create initial tables for MySQL database: Use  `MySQLdbSetup.sql`.

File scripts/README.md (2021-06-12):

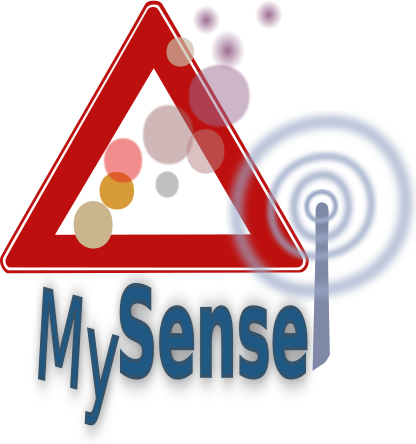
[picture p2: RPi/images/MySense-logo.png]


# MySense
Last update of the README on 29 June 2020

## Description
Various scripts to maintain and manage MySense measurements.

### Outline
MySense measurements from the measurements kits arrive via LoRaWan (The Things Network) to a server which interfaces to Internet via Mosquitto (MQTT).

From there *TTN-datacollector* will do data acqui9sition into a MySQL database, forward measurements to various data portals like Luftdaten.info and dependent (sub) dataportals like RIVM Nld, AirTube, etc., as well maintain/manage the measurements via email/Slack notices.
In this way keep track of the behaviour of known, noit yet regsitrated measurement kit and out of band measurements and kit events.

### TTN-datacollector
Use: data acquisition, data forwarding, kit maintenance

Use --help option to obtain various options. The data collector will use a color scheme to prioritise messages and loggings. The data collector is able to log to a pipe.
TTN-datacollector has a monitor output channel to view status.

TTN-datacollector will use various general library routines. The library routines can be used stand alone.
Like:
- MyLogger.py       logging routines (multi threaded)
- MyCONSOLE.py      full output to terminal
- MyLUFTDATEN.py    forwarder to Luftdaten.info
- MyDB.py forwarder to MySQL measurements database
- MyPrint.py        logging
- WebDB.py          website database interface
- MyDBsyncWebDB.py synchronize meta info between data DB and web CMS DB (Drupal)
- MyAdmin.py        update meta info in data DB from (json format) admin info

### MyDB
Use: database library module and meta info DB insertion
The module can be used in stand alone version. The use is to insert meta measurement
kit information (location, oeperational details, ect) into the database tables Sensors (lataion details,...) and TTNtable (TTN forwarding, database data forwarding).

### GeneratePMcharts
Use: visualisation, data filtering, data correction, calibration

Bash shell script a wrapper to maintain (filter spikes) measurements in the database, generate various graphs on CMS (Drupal) website, generate overviews of measurements, etc.

The script uses FilterShow.py (spikes removal), ChartsPM.pl (HighCharts website page graphs).

### SyncWebDB
Use: meta data maintenance

Synchronize and update visa versa measurement kit meta information between website database pages and measurements database.
SyncWebDB uses WebDB.py (website database interface), AirQualityIndex.pl (LKI marker coloring) and MyDB.py (measurements database interface).

### CheckDeadSensors
Use: check for malfunctioning and not active measurement kits over a long period.
Send notices if problems are detected.

Use DB environment variables for database credentials definitions. REGION and arguments may be string patterns as supported by regexp of MySQL. Use command help for help.
Script will save dates of sent notices and will only resend email notices again after 3 days.

### MyDBsyncWebDB
Use: meta information measurement kit datanbase synchronisation

Uses environment settings for database credentials. Can be in interactive mode to manually correct meta info values.
MyAdmin script may use this script to synchronize meta info from data DB with CMS DB.
Can operate in 3 modes:
. Can be used to synchronisize databases on last time updated base as well.
. Synchronize from data DB towards web CMNSA database and other way around.

### CorrectSensed.pl
Use: get sensor measurements corrected for supported sensor type correction algorithm templates

Can be use in different scripts to correct the sensor measurement on type by different manuafacturers.
The algoritm is based on regression statistics on half year period on a governementa air quality station in Vredepeel, Holland.: Nova, Sensirion, Plantower, and BAM1020 dust sensors.
In time to be completed with other sensor types.

### MyAdmin
Use: import (new, update) meta info measurement kit in data database.

Can be used in interactive mode. Default the script will try to synchronize meta info towards the web CMS (Drupal) database as well if database credentials are provided via CLI environment settings, e.g. DBHOST, DBUSER, WEBHOST, WEBUSER, etc.
Can be used to output current database meta info for a range (regular expression) of measurement kits in json format to export meta info.

### MyLoRaCode
Use: vai import or standalone for TTN payload decoding tests

Supports TTN V2 and V3 stack MQTT produced records.
Module when used a standalone can read records from stdin eg via mqtt_subscribe some_options | python(2/3) MyLoRaCode.py for test purposes.

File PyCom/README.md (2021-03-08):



# PyCom LoPy or WiPy  BME280/BME680 SDS011/PMS7003/SPS30 GPS  MySense sensor kit

Status: *rc1* 2019/02/25

Copyright: 2019, Teus Hagen
To enable further developments is is common in the Open Source world to support a public domain project financially or otherwise. Certainly if your product is based on this type of public domain licensed software.

*Licensing*: Open Source Initiative  https://opensource.org/licenses/RPL-1.5
   Unless explicitly acquired and licensed from Licensor under another
   license, the contents of this file are subject to the Reciprocal Public
   License ("RPL") Version 1.5, or subsequent versions as allowed by the RPL,
   and You may not copy or use this file in either source code or executable
   form, except in compliance with the terms and conditions of the RPL.

   All software distributed under the RPL is provided strictly on an "AS
   IS" basis, WITHOUT WARRANTY OF ANY KIND, EITHER EXPRESS OR IMPLIED, AND
   LICENSOR HEREBY DISCLAIMS ALL SUCH WARRANTIES, INCLUDING WITHOUT
   LIMITATION, ANY WARRANTIES OF MERCHANTABILITY, FITNESS FOR A PARTICULAR
   PURPOSE, QUIET ENJOYMENT, OR NON-INFRINGEMENT. See the RPL for specific
   language governing rights and limitations under the RPL.

Goal: professional DIY durable simple low cost (ca €120) air quality sensor kits.

## description

Overview of wiring and modules using a PCB board with Grove connectors to avoid soldiering and ease sensor replacements and extensions.
Included are the 3D print files for the housing/case as well PCB board electronic design as well PCB board manufacturing instructions.

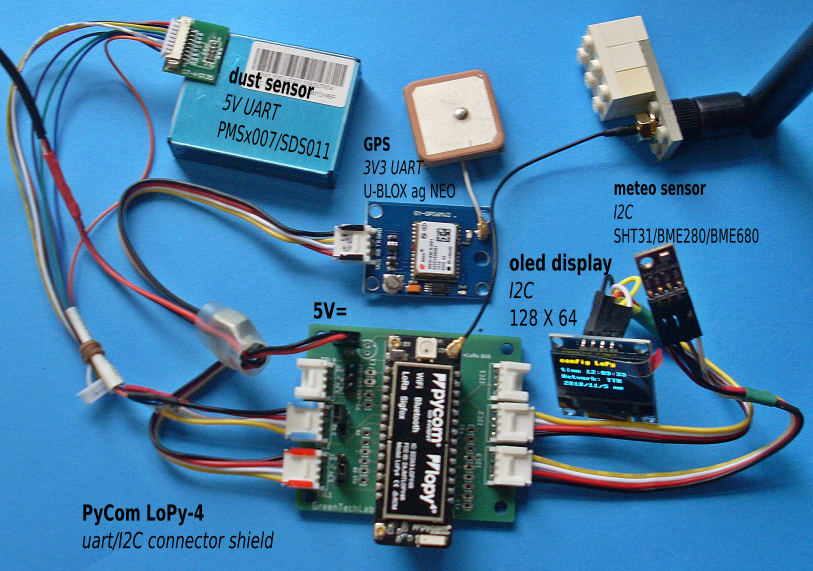
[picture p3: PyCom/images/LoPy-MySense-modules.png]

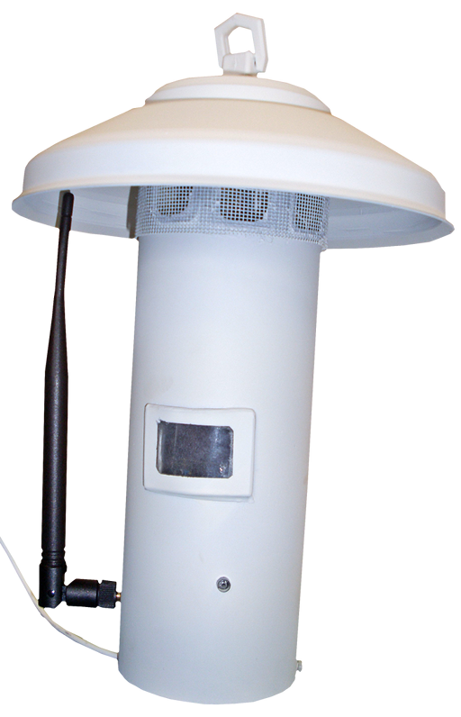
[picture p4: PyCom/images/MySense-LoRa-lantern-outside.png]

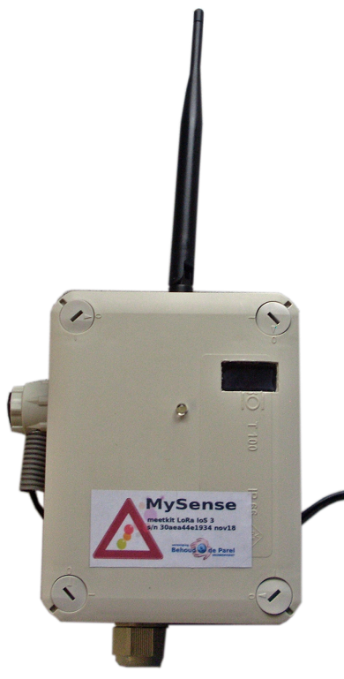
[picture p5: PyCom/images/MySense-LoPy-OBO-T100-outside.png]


Comment: here we used the indoor dust sensor Plantower PMS7003. Use for outdoor the PMSx003 dust sensor. Other dust sensors as from Nova and Sensirion are supported.

## Shopping list (ca € 100-150):

* PyCom LoPy-4 controller  PYCLOPY4 (Tinytronics  € 35.-)
* optional LoPy Expansie board 2.0 PYCEXPBOARD3.1 (Tinytronics € 19.-) (development board)
* alternative is a DIY PCB connector board with 6 Grove connectors (3 TTL and 3 I2C) ca € 10 (incl the  components (mosfet, resisters, pins).
PCB board has optional components to be able to use solar panel power. See schema, PCB manufacturing mall, and battery guard schema and mall `pwrsafe11`.
Our PCB has been made by Fontys Venlo GreenTechLab and updated by Land van Cuijk initiative.
* LoPy-Sigfox antenne kit 868 Mhz PYCLOSIAN868KIT (Tinytronics € 10.50)
* optional SSD1306 I2C Yellow/Blue 128X64 oled display (AliExpress € 2.23, Tinytronics € 9.50)
E.g. <a href="https://nl.aliexpress.com/item/0-96-inch-IIC-Seri-le-Geel-Blauw-OLED-Display-Module-128X64-I2C-SSD1306-12864-Lcd/32920071528.html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">Oled display</a>
* Sensirion SPS30 indoor laser PM sensor (Antratek: € 45.95, <a HREF="https://nl.aliexpress.com/item/4001050822435.html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">Ali Express</a> € 25,90)
Advised because the unit displays raw PM counts values and can be used outdoor.
Plantower has a new PMSx003 (black) which has cleaning support and tube inlet (€ 80).
E.g. <a href="https://wholesaler.alibaba.com/product-detail/PMSX003-PM1-0-PM2-5-PM10_60805148973.html">PMSx003 dust sensor</a>
* Alternative is Nova SDS011 (bigger, less PM types, but has air inlet tube connection)
E.g. <a href="https://nl.aliexpress.com/item/Nova-PM-sensor-SDS011-High-precision-laser-pm2-5-air-quality-detection-sensor-module-Super-dust/32606349048.html">SDS011 Nova dust sensor</a>
* optional GY-NE06MV2 NEO-6M GPS module TTL connection (AliExpress € 3.15)
E.g. <a href="https://nl.aliexpress.com/item/Free-Shipping-1PC-Ublox-NEO6MV2-GPS-Module-Aircraft-Flight-Controller-For-Arduino-New/1765564932.html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">NEO6MV2 GPS module</a>
* optional Sensirion SHT31 (AliExpress € 2), BME280 (AliExpress € 3),
E.g. <a href="https://nl.aliexpress.com/item/Free-shipping-SHT31-Temperature-SHT31-D-Humidity-Sensor-module-Breakout-Weather-for-Arduino/32695064184.html">Sensirion SHT31 meteo sensor</a>
* or better BME680 I2C (has interesting gas sensor, AliExpress € 10.50) meteo sensor (do not use I2C/TTL BME680, I2C bus errors)
E.g. <a href="https://nl.aliexpress.com/item/1-stks-Ultra-kleine-Druk-CJMCU-680-BME680-Temperatuur-Vochtigheid-Druk-Sensor-voor-Drone-Accessoires-Hoge/32847670390.html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">BME680 meteo sensor</a>
* wiring: per module 4 wires: female/male for 4 modules:
<a href="https://www.seeedstudio.com/Grove-4-pin-Female-Jumper-to-Grove-4-pin-Conversion-Cable-5-PCs-per-PAc-p-1020.html">Grove to female jumper 4 wire conversion cable</a> 5 per pack Seed Studio  € 5.00.
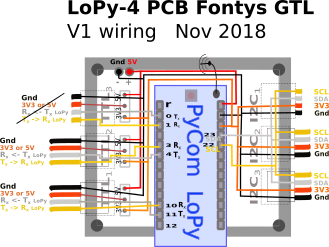
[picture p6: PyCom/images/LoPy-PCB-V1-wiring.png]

Remark: better to create a UART/I2C connector shield with Grove sockets and connectors. See the picture. Board design with Grove sockets is available.
See the SVG file (and the picture) of the alternative PCB LoPy expansion board designed by Fontys Venlo GreenTechLab as example.
* assortiment thrink tubes (2.5 mm and bigger) (€ 3.45 Ben's Electronics)
* V220 outdoor cablebox 10X12.5 cm, larger is better eg OBO T100 or T160. (electroshop.nl € 5.39)
Or use PVC pipes and roof air outlet exhaust. Advised is to paint it white and use double pipes for heat isolation. A double PVC pipe will lower the LoRa signal strength a bit. Make sure no wires are near the antenna.

Energy V230 supply (ca € 4):
* long USB adapter cable 2-3 meter (Action € 1.50)
* USB V220 AC - 5V dc adapter 1A (Action € 2.10)
 
or use solarpower if no V230 is available (ca € 100):
* 12V to 5V step down (ca € 1): e.g. <a href="https://nl.aliexpress.com/item/9V-12V-24V-to-5V-3A-USB-step-down-voltage-regulator-module-DC-DC-Converter-Phone/32815945754.html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,searchweb201602_3_10065_10068_319_317_10696_10084_453_454_10083_10618_431_10304_10307_10820_10821_10301_537_536_10843_10059_10884_10887_100031_321_322_10103,searchweb201603_2,ppcSwitch_0&algo_expid=ee417a9f-b67e-4414-8df8-60f29a8a5a9e-8&algo_pvid=ee417a9f-b67e-4414-8df8-60f29a8a5a9e&transAbTest=ae803_4">5V USB</a>
* solar power regulator (ca € 10)  e.g. <a href="https://www.banggood.com/nl/MPPT-5A-Solar-Panel-Regulator-Controller-Battery-Charging-9V-12V-24V-Automatic-Switch-p-1307801.html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">Solar PR</a>
* battery guard to switch kit off if battery level is too low (DIY € 3). See pwrsafe1 schema.
Make sure to apply a diode over the power connectors and capacitor as a wild change in solar power or on/off connection may destroy your controller.
WARNING: without a capacitor (eg 100 uF 16V) the accu/solar combination or loose contact may blow away your controller.
Make sure to use a good regulator. We measured a peak of 11.4 V on the 5V stepdown regulator in such cases.
* or battery load (ca € 10)  e.g. <a href="https://www.banggood.com/nl/MPPT-5A-Solar-Panel-Regulator-Controller-Battery-Charging-9V-12V-24V-Automatic-Switch-p-1307801.html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">Solar power regulator</a>
* battery pack (ca € 60)  e.g. <a href="https://www.conrad.nl/p/gnb-sonnenschein-dryfit-s1266-s-071-98-43200-solar-accu-12-v-66-ah-loodgel-b-x-h-x-d-152-x-99-x-66-mm-kabelschoen-4-110752">battery 12V</a> (needs 12V->5V).
* solar panel (ca 16)  e.g. <a href="https://nl.aliexpress.com/item/LEORY-5-w-18-VSolar-Panel-Outdoor-Polykristallijne-Zonnecellen-Module-Oplader-Voor-12-v-Batterij-Toegepast/32950222836.html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">Solar Panel</a>
* housing/case for the power

ToDo:
* software to use WiFi/MQTT for internet access connectivity if LoRa is not available
* Over The Air (OTA) update via the <a href="https://docs.pycom.io/tutorials/all/ota.html">PyCom OTA method</a>.
Currenty one can use WiFi AP access and Atom. If the WiFi AP is powered off by configuration the LoRa command 'W' will enable WiFi AP of the node again for one hour.
* Solar power regulator with watch dog for battery level.
Currently the PCB in use has battery level support and will force deepsleeps untill battery level is high enough to be operational.

Some fixing materials:
* 2 component glue
* some fixing tool to stabalize the antenna. Or place the antenna inside the housing.
* 4 cm tube for air inlet of PM module (SDS011 or PMSx003)
* piece of wood to be able to attach the outdoor cable box on a wall.
* some material to fixate the components and allow airflow in the box
* or see 3-D print masks for double sided PVC housing contruction.

One may need to extend those dust sensors without an inlet tube and inlet as well as ouytet on same side with some air separation guidence in order to avoid to measure only the dust circulating within the housing.

### LoPy kit casing
A simple housing case is made with a piece of plexiglas 61 X 230 mm (see for the dril mask for 3 mm dril the SVG file in the images directory).
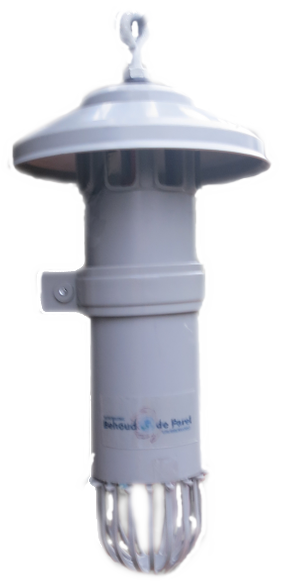
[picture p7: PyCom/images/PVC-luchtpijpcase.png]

This plexiglas can be fixated within an PVC roof air outlet (length 300 mm diameter 80 mm) and some mosquito bait with PVC ring (socket).
One may locate the LoRa antenna in the pipe or on the outside attached to the PVC ring.
Make sure to paint the housing white and avoid direct sun on the kit.

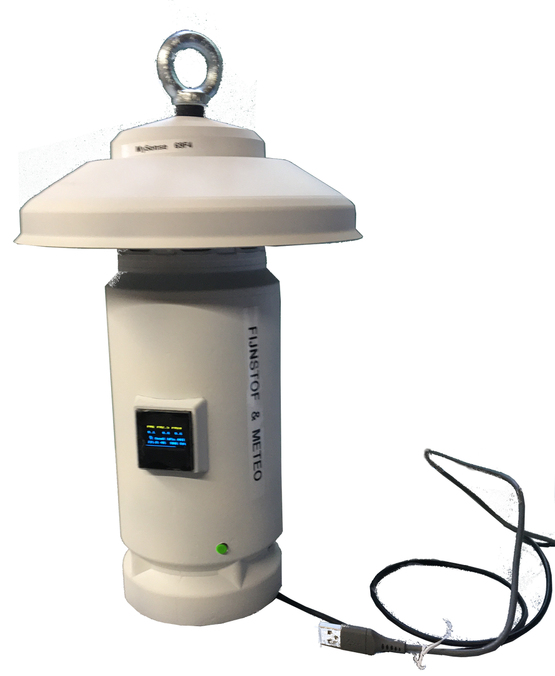
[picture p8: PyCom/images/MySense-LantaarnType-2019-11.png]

Another housing can be made with a V230 outdoor connector box e.g. OBO T100 box.

A better housing can be made from PVC roof air outlet manufactured eg from BT Nyloplast Nld (€ 7.50).
The components are mounted on a so called mother board from 3 mm plastic.
To avoid solar heat use an internal PVC rain pipe.
The motherboard can be fit in a 3D printer made socket.
The oled display is fixed on the housing with a 3D printed container.
The GPS antenna is glued inside the PVC pipe on a small table (3D print) and must point upwards.
The LoRa antenna is fixated inside the PVC pipe as well.

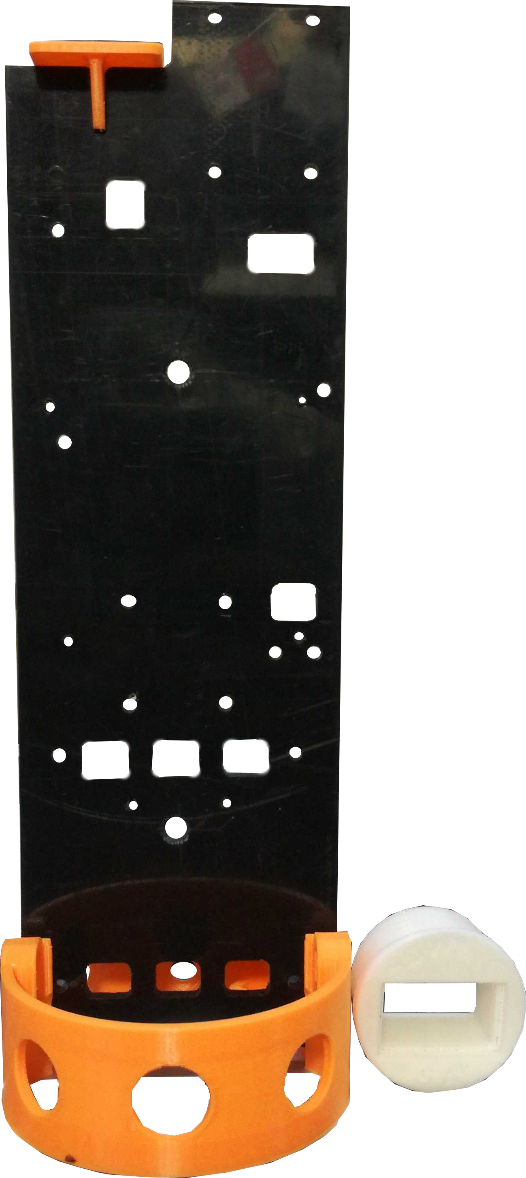
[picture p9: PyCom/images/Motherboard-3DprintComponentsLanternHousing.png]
images/Motherboard-3DprintComponentsLanternHousing.png</img>
All 3D printed components and mother board are found in the images folder ( 3D .stl en dcx (FreeCAD) files):
* 3D print GPS mounting table: <a href="images/GPS tafel a.stl">images/GPS tafel a.stl</a>
* 3D print oled display window: <a href="images/Oled  inw 2.stl">images/Oled  inw 2.stl</a>, and <a href="images/Oled  inw 2.1.stl">images/Oled  inw 2.1.stl</a>.
* 3D print oled display mounting: <a href="images/Oled buiten uitw c.stl">images/Oled buiten uitw c.stl</a>
* 3D print motherboard socket: <a href="images/houder mb.stl">images/houder mb.stl</a>.
* CAD CAM mill mold: the mounting board: <a href="images/moederframe2.2.dxf">images/moederframe2.2.dxf</a>
These stl and dxf files: Copyright 2019, Joan Marsman, the Netherlands licensed as GPL V3.

### TTN gateway

DIY or buy one.

You may be unlucky and do not have a TTN infrastructure in the neighbourhood. However it is easy to build one your self with Pi controller, an IC880-SPI or RAK831 concentrator, pigtail and antenna in some  casing, ca € 2000-230, Ideetron.nl or AliExpress) or buy one (ca € 350 (TTN gateway via Ideetron.nl) or higher € 450-1.200).
See for how-to instructions:
* IC880a-SPI concentrator: https://github.com/ttn-zh/ic880a-gateway/wiki
* https://github.com/Lora-net/lora_gateway#readme
* RAK831 concentrator: https://www.thethingsnetwork.org/labs/story/rak831-lora-gateway-from-package-to-online
* RAK7258 (TTN) gateway: cheap, complete, OpenWRT based for ca € 160.

For MySense we changed the `/opt/ttn-gateway/bin/start.sh`, added WiFi access point for WEBMIN (use `INSTALL.sh WEBMIN` and Raspberry Pi OS configuration (see `INSTALL.sh help`), and to log concentraor log messages to the oled display via the filter `GatewayLogDisplay.py`. The scripts can be found in the map LoRa.
See the map LoRa (or Google to The Things Network) for more details and functionality add-on's to build a DIY TTN gateway.

The TTN ZH Pi based shopping list (we bought a ready to go gateway Pi2 based from IMST and changed the software to TTN for € 250):
* Pi Zero or 3, poweradapter, minimal 4GB SDcard € 42 Tinytronics.nl 
* iC880A-SPI concentrator board (<a href="http://shop.imst.de/wireless-modules/lora-products/8/ic880a-spi-lorawan-concentrator-868-mhz" alt="IMST webshop">IMST websop CH</a>) € 120 (ideetron.nl).
* 868 MHz anternna and pigtail € 10
* 7 Dupont wires (female/female) € 1
* enclosure e.g. OBO T160 V220 cable box € 10
* optional outdoor antenna with fuse(!) € 75 (ideetron.nl)

or:
* RAK831 in case via AliExpress, which has GPS antenna and a too small LoRa antenna: € 178.
The alluminium case does not allow WiFi signal of the on board chip to reach outside of the case. For WiFi you may need a USB WiFi dongle. If so make sure the dongle is able to be used as WiFi access point as well as WiFi client.
* 6 dB glasfiber antenna via AliExpress: € 29
For Europe make sure you have a 868MHz version (use with AliExpress the color option).

For both types of boards install the ttn-gateway software from `apt install git; git clone https://github.com/ttn-zh/ic880a.git/ ~/ic880a-gateway`.
Make always sure antenna is placed before you start to use the gateway! A start without the antenna connected will distroy the concentrator board.
Configuration hint for software: make sure the right reset pin number of GPIO Pi is used (see start.sh shell command file, and do not use initialy the remote concentrator configuration.
The concentrator board needs always to be reset before starting up the forwarding software.

## DESCRIPTION
The sensor kits are build with PyCom (loPy-4 and WiPy-3) ESP controllers and PyCom expansion board.

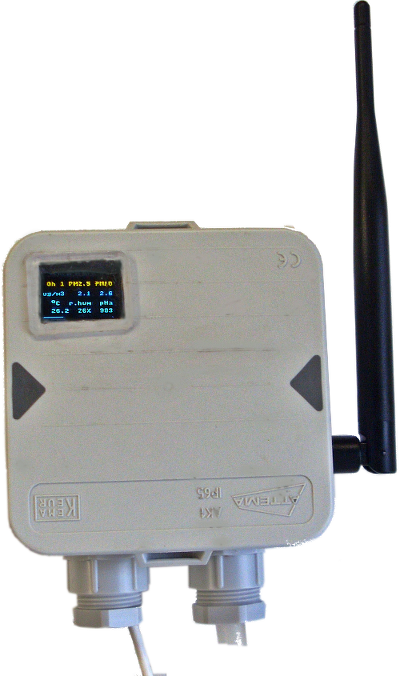
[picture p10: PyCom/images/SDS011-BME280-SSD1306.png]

The controller has on board WiFi, BlueTooth and for LoPy LoRa. Use an external LoRa Wan 868/915 LoRa antenna on the LoPy.
The PyCom controller can be programmed via embedded micropython.
To access the board use the Atom with the Pymakr plugin.
Atom is interfacing either via WiFi (192.168.4.1) or serial (USB) connection to the controller.

The goal is to use the PyCom ESP as controller for MySense sensor satallite kits. Measuring dust, rel. humidity and GPS to forward this to Mosquitto database (WiFi) or LoRa data concentrator. From which the MySense configured as proxy can pick up sensor data to the MySense databases.

Datacommunication is done via WiFi (Mosquitto), or LoRa (TTN MQTT data concentrator) and MySense Raspberry Pi  in server mode.
One may send data via MySense Pi server to RIVM in the Netherlands as well Luftdata in Germany.

### measurement data
The MySense kit will collect measurements from dust (Nova SDS011, Plantower PMSn003 serie and Sensirion SPS30) sensors and meteo (BME280 or BME680 with air quality support) sensors and send this data either via wifi or LoRaWan (TTN) Mosquitto (MQTT) dataconcentrator, e.g. `TTN-datacollector.py` with different output backends. Dust measurements will be collected over a sample time (default 1 minute) and send to the data concentrator at interval (default 5 minutes) periods of time. Fan and laser of the dust sensors will be powered off in the idle periods of time.
To ease the calibration of dust sensor one is advised to use sensors which beside the mass values also show the PM count values.

The MySense server will collect this information from the MQTT servers and formward these measurements and meta data to e.g. a MySQL database, spreadsheet or another data stream service.

One may need to clean the fan, or even lenses, e.g. on the event on high unexpected values. See <a href="https://www.mistywest.com/posts/teardown-sensirion-particle-matter-sensor/" alt="how to teardown SPS30">how to teardown the Sensirion SPS30</a>.
### remote management
The LoRa MySense part is supporting remote control via TTN. The following remote commands are supported yet:
* '?': send version, configuration and location details to TTN MQTT server
* 'O': switch the oled display if present OFF (dflt ON)
* 'S': stop processing (to do: put node to deep sleep)
* 'i'-value : change the sample interval time to value seconds (dflt: 5 minutes)
* 'd' or 'D': turn dust sensor calibration OFF or ON
* 'm' or 'M': turn meteo sensor calibration OFF or ON
* 'w' or 'W': turn dust sensor to weight modus
* '#': turn dust sensor to partical count modus (if dust sensor supports it)
* to be extended e.g. meta updateMin and updateMax information frequencies.

### Meta information
The PyCom MySense kit will send on start and at specific `updateMax` (default 6 hours) intervals *kit information* (type of used sensors) and *GPS location* separately from the data stream to the data concentrator (LoRa port 3).
If the GPS modules is installed the controller will (re)sent this location information at the moment (`updateMin`: dfault minimal frequency is 7 minutes) a location change is detected (default 50 meters).

## PyCom programming
The PyCom boards are using MicroPython (see http://docs.micropython.org/en/latest/pyboard/).
MicroPython is an embedded Python 3 alike scripting language.

A guide to set up (your first steps with the Pycom module) the PyCom Lopy is available from the PyCom website: <a href="https://docs.pycom.io/gettingstarted/introduction.html">Getting Started"</a>. Make sure to install the latest PyCom firmware. Try to <a href="https://docs.pycom.io/gettingstarted/programming/examples.html">print 'Hello World'</a> from micro python `>>> print("Hello World")`, <a href="https://docs.pycom.io/gettingstarted/programming/first-project.html">blink the RGB led and erase/cleanup the PyCom `/flash' file system</a>.

## WiFi SECURITY
Default the PyCom board will enable WiFi as Access Point with standard public known access passwords en telnet/ftp credentials. MAKE SURE you change this to avoid the use of the controller by anyone. See how to's:
* https://docs.pycom.io/chapter/tutorials/all/wlan.html
* Adafruit and https://mike632t.wordpress.com/2017/04/11/connecting-my-wipy-to-my-wifi/:

How to connect the PyCom to your own network (defeat: you will ONLY be able to control the PyCom from remote within the range of your wifi).
Hint: only change ftp/telnet user/password ...

Create a `boot.py` file with the following content:
```Python
    import os
    import machine
    import network
    import time
   
    # Duplicate output on UART
    uart = machine.UART(0, 115200)
    os.dupterm(uart)
  
    # Disable telnet and FTP server before connecting to the network
    server = network.Server()
    server.deinit()
   
    # Connect to WLAN
    wlan = network.WLAN()
    wlan = network.WLAN(mode=network.WLAN.STA)
    nets = wlan.scan()
    for net in nets:
      if net.ssid == '<YOUR OWN PYCOM ssid>':
        wlan.connect(net.ssid, auth=(net.sec, '<YOUR WiFi wireless-password>'),
          timeout=5000)
      while not wlan.isconnected():
        machine.idle() # save power while waiting
  
    # Enable telnet and FTP server with new settings
    server.init(login=('<YOU/user>', '<YOU/password>'), timeout=600)
    time.sleep(10) # Wait 10 seconds before continuing
```
And load up via FTP the boot.py to the board.

### How to interact with the PyCom board?
Install *atom* from http:atom.io (PyCom): for Debian systems download the IDE application with extension .deb and install via `dpkg -i atom-XYZ.deb` and the pymakr plugin from the PyMakr github: `git clone https://github.com/pycom/Pymakr` (read the README.md!), optionally install *apm*, and run in the cloned directory `apm install`. Copy all contents to a new directory `~/.atom/packages/PyMakr`. This will install a PyCom board IDE (development tooling).

Or use an alternative *rshell* (Python 3 tool)from: https://github.com/dhylands/rshell. Read the rshell README file how one can use this command line tool to upload, download and use REPL.

The PyCom controller will run on power ON `/flash/boot.py' and `/flash/main.py`. If not you can interact via atom with the controller. In the directory `/flash` ('home' directory) your scripts should reside.
Push and keep it pushed the *user* button on the expansion board first and while pushing push the *reset* button on the controller will reboot the controller but will not run boot.py as well main.py. The other way is to press <cntrl>C on the keypboard (keyboard interrupt).

In the PyCom folder you will see some main scripts. The libraries for the sensor modules are in the lib folder. Copy the main scripts to the 'LoRa/firmware' directory, as well the needed libraries (see the statement *import* in the used scripts) to the *lib* directory. Point *atom* as new project to the configured *firmware* directory and press 'sync' or 'reload' button to load the files into the PyCom controller.

The PyCom board can be accessed to change the firmware either via WiFi (see the lopy-191228 PDF's and PCB manufacturer zip documentation; Contributed by Ad de Jong) and/or USB of the PyCom expansion board.
To monitor the power level of the battery powered by a solar panel there is a tiny board available which guard overload of the battery and drain of the battery. The regulator switches between 3.2V and 3.8V. See technical schema and zip documentation `pwrsafe1.jpg` and `pwrsafe1.zip` (contributed by Ad de Jong).
* Debian: make sure you have access to `/dev/ttyACM0` or `/dev/ttyUSB0`. Use the Linux command `lsusb` and see if *Microchip Technology, Inc.* is present. If not see what the problem might be via `/var/log/syslog`. In one occation we had to do create the `/etc/udev/rules.d/49-micropython.rules` with the content:
```
# idVendor=04d8, idProduct=ef98 PyCom
ATTRS{idVendor}=="04d8", ATTRS{idProduct}=="ef98", ENV{ID_MM_DEVICE_IGNORE}="1"
ATTRS{idVendor}=="04d8", ATTRS{idProduct}=="ef98", ENV{MTP_NO_PROBE}="1"
SUBSYSTEMS=="usb", ATTRS{idVendor}=="04d8", ATTRS{idProduct}=="ef98", MODE:="0666"
KERNEL=="ttyACM*", ATTRS{idVendor}=="04d8", ATTRS{idProduct}=="ef98", MODE:="0666"
```
Disconnecet the PyCom USB cable, issue `sudo udevadm control --reload-rules` and reconnect the USB cable to the expansion board. 

## MySense satellite sensor kits
The MySense satellite sensor kits are less powerfull and build around the Marvin and PyCom ESP controllers.
The PyCom scripts have the following structure: 
* sensor module scripts which reside in the lib folder
* Config.py which describes which module is used and how it is wired. It is used by the other scripts
* sensor test scripts named as {meteo,dust,gps,ssd1306}_test.py for testing the harware
* the main script *MySense.py* for operational use.

### tested MySense sensor modules
Choose one meteo and one dust sensor: MySense modules in development are:
* Sensirion SHT31 meteo: temp and humidity on I2C bus
* Bosch BME280 meteo: temp, humidity and pressure on I2C bus
* Bosch BME680 meteo: temp, humidity, pressure and air quality on I2C bus
  One serie of BME680 I2C/TTL modules are causing I2C bus errors.
  Advantage of BME680 is the gas (AQI) sensor as gas indication.
* Plantower PMS7003/PMSx003 (indoor and outdoor version) dust mass and count: PM1, PM2.5 and PM10 on UART TTL (no USB)
* Nova SDS011 dust mass only: PM2.5 and PM10 on UART TTL (no USB)
* Sensirion SPS30 dust mass and count: PM1, PM2.5, PM4 and PM10 on UART/I2C
* GPS location: UART TTL (no USB)
* SSD1306 tiny oled display: 128X64 pixels on GPIO bus or I2C (preferred) bus.
* LoRaWan: using TTN MQTT server
* MQTT via WiFi: not implemented yet

Comment: do not use eg UART Rx on pin 12. Pin 12 high on reset will cause to omit executing boot.py and main.py.
Maximum of UART modules is 2 (e.g. dust and GPS modules).

To test I2C wiring use the following EXP commands:
```
    SDA='P23'
    SCL='P22'
    from machine import I2C
    i2c = I2C(0,I2C.MASTER,pins=(SDA,SCL))
    i2c.scan()
```
This should return the I2C registers as e.g. `[60]` (decimal!) for the I2C address of a BME280. If `[]` there is no I2C module attached to the pins. Or if it hangs wiring is wrong.
If the scan produces unexpected extra register address values please check your I2C modules to avoid I2C bus errors.

From release version 3 MySense will auto detect I2C devices on maximal 3 I2C busses.

### wiring PyCom <-> devices
Advised is to use strict colors: *red* for 5V, *orange* for 3V3 and *black* for Ground.
Use *white* (SCL or controller Rx) and *yellow* (SDA or controller Tx) for data wires.
We use Grove connectors with female Dupont connectors. Our connector board has Grove sockets which lead to the right pins of the PyCom controller: TTL (5V or 3V3) and I2C devices (3V3).
#### Uart or TTL devices
E.g. GPS (3V3) and dust sensors (5V). 
Examples:
```
    GPS 3V3, Tx yellow wire - PyCom Rx Pin P10 (unused)
             Rx white wire  - PyCom Tx Pin P11
    Dust 5V, Tx yellow wire - PyCom Rx Pin P3
             Rx white wire  - PyCom Tx Pin P4
'''
The PyCom has P0 Tx pin and P1 Rx pin (expansion board USB connected) for a 3rd TTL e.g. Spec TTL NO2 sensor. To Do: add Spec gas sensor driver.

MySense support auto UART device recognition for GPS and dust sensors (SDS011, PMSx007 serie, and SPS30). See the `Config.py` file for details how to enable/disable ato configuration.
The UART pins may be defined (tuples: (white wire Tx,yellow wire Rx) -> device (Rx,Tx)) if not default pins (P4,P3),(P11,P10) are used.

#### I2C for sensors and oled display
All I2C are parallel in this example. SDA is I2C data wire, SCL is I2C clock wire.
```
    device 3V3, SDA white wire  PyCom SDA Pin P23
                SCL yellow wire PyCom SCL Pin P22
```
MySense will scan the I2C bus(ses) for auto configuration of known I2C devices (oled display and various meteo sensors). I2C pins are defined as tuples (white wire SDA, yellow wire SCL), default: (P23,P22).

## remarks
BME280 or BME680 meteo sensors are tuned for indoor applications. Lifetime of sensors differ much because of this. The DHT11 or DHT22 are worse for outdoor application usage and should not be applied.
An alterrnative is to use the Sensirion SHT21 or SHT31 I2C module (only temp and RH). The SHT sensor seems to cause I2C bus errors regularly.

The dust sensors have a fan and laser. Both have a limited time of life. Hence the fan and laser are powered off in idle state. It is unclear if this method will help to improve the lifetime.

To Do: auto detect UART devices.

### RTC clock
MySense will use GPS to initilyse the Real Time Clock module. Every time the GPS location is looked up the RTC clock will be updated automatically.
This will allow MySense to timestamp measurements more precise.

### MySense satellite LoRa kit configuration
Use the file `Config.py` to define which sensors are configured for the kit. Have a good look at the *pin*s definitions and bus used for the sensor. The `Config.py` file should reside in the *firmware* directory in order to upload it to the controller.

If `dev_eui, app_eui and app_key` is defined in `Config.py` the LoRaWan On The Air Authentication (OTAA) method will be tried first to join with 4 X 15 secs a wait for authorisation.
If not defined or the join did not complete the ABP method will be used with the configured `dev_addr, nwk_swkey and app_swkey` in `Config.py`. With method ABP MySense will not wait for authorisation.

The file `Config.py` will show default configuration items in comments. Make sure to define the correct LoRa (The Things Network) keys.

In order to support solar panel as energy source MySense supports the *deepsleep* functionality. In order to do so there are 3 ways to keep the configuration details:
* `Config.py` to allow a clean cold start (powerup boot).
* `a json file in flash memory` to keep track of stable configurations and discovered devices. This allows mainly a warm reboot from eg a deepsleep.
* `nvs ram` values to survive a powercycle e.g. LoRa keys and counters, different alarm settings.

The auto maintained configuration data can be cleared as followed:
```python
    import pycom
    # 0 for clear flash configuration and nvs ram variables on cold (re)boot
    # as well clear all nvs ram variables
    pycom.nvs_set('modus',0)
    # modus 1: for clear ttl/i2c device conf
    # modus 2: do not clear assembled configuration (advised)
```
The json configuration will be updated if via remote command the configuration item is changed. So the change will survive a reboot.

Configuration item `power` will define if between deepsleeps de bus will be unpowered. E.g. deactivate GPS device fully. The kit will go into deepsleep if AND deepsleep pin is enabled AND `power` attribute `sleep` is True. On a cold boot with deepsleep pin enabled the default startup `power` configuration will be with `ttl`, `i2c` and `sleep` defined as *True*.

Configuration dictionary `interval` will define e.g. sample times ('sample': dflt 1 minute), and interval timings ('interval': dflt 15 minutes). As well next time meta information ('gps': 'gps_next', 'info': 'info_next': xyz_next values will be stored in nvs ram to survive a reboot) will be sent or GPS will be tried to find GPS location and set day time. 
Configuration dictionary 'power' will define, True is power off, to enable/disable power on 'ttl' (dflt: False), 'i2c' (dflt: False), 'led' (rgb led) (dflt: False), 'wifi' (dflt: True) and 'display' (dflt: False). As well 'sleep' to enable (dflt: False) a soft deepsleep (without sleep pin use).
Using remote LoRa commands one may change this at run time (see MySense.py CallBack routine for details).

Alternate WiFi AP SSID and PASS can be configured via Config.py configuration file.
Default SSID `MySense-HHHH` with PASS `www.pycom.io`.
With a cold reboot (power cycle) and with WiFi power management off (False) the configured password will be effectuated after 1 hour.
Unless 'power' item 'wifi' is defined as True. In which case the WiFi will be turned off.

Configuration dictionary 'calibration' will define Taylor calibration rules for corection of 'temperatue', 'humidity', 'pressure', 'gas', 'pm1', 'pm25', pm10', and define 'gas_base' for AQI calculations.

Use of Dext or Dexplicit (default False) will cause dust count values to be taken as inclusive previous size (Sensirion style or valuation; and cause average grain size to be calculated). True will; define Plantower style of valuation (sizes biger as underbound).

There is a wealth of configuration possiblities. Not all have been tested. See the scripts to see what they are about.

LoRa keys and package counter (important for ABP LoRa connectivity) are saved and maintained in nvs memory. As well last gps location and next meta info and next gps location check are kept in nvs memory.

How To clear the configuration in flash memory: on a cold reboot with deepsleep pin enabled and no accu attached to accu load management pin the json configuration file (dflt: `MySenseConfig.json`) in flash memory will be cleared and a new configuration will be detected. Use this procedure when new keys of sensors are attached to the controller.

*Deepsleep ESP problem?*
In our experience we discovered with deepsleep: the LoPy would not wake up at a random deepsleep calls. This might be a bug in the ESP hardware or software. A work around seems to be delay for 500 msecs the ESP. This work around is under investigation.

Question: how can I force a deepsleep without an accu attached to the kit? Answer: start without the deepsleep pin enabled. After trhe first interval install then the deepsleep pin.

### Testing hardware
MySense has provided several simple XYZ_test.py python scripts to test the sensor modules for needed libraries and check of wiring.
Make sure to configure the right pin ID's in `Config.py` configuration file for the test scripts.
Default pins are defined as follows:
* I2Cpins: 'P23' (SDA, white), 'P22' (SCL, yellow) and 'P21' (dflt None, Pwr enable/disable)
* UARTpins: TTL3 ('P1' Rx yellow, 'P0' Tx white, 'P20' (dflt None) Pwr), TTL2 ('P4' Rx yellow, 'P3' Tx white, 'P19' (dflt None) Pwr), and TTL1 ('P11' Rx white, 'P10' Tx yellow, 'P9' (dflt None) Pwr). Tx/Rx is controiller side. At devices side Tx is yellow, and Rx is white wire.
* other pins: 'P17' and ground for keeping track of accu voltage. And 'P18' so called deep sleep pin (force deepsleep).

Test your setup one by one before trying out the main wrapper `MySense.py` via *MySense.runMe()* or `main.py`.
A more detailed readme about the way `MySense.py` and other test script maybe of help can be found in the file `README.MySense.md`.

## Your First Steps
* visit the PyCom.io website and follow the installation guide
The following is an outline how we do the developments and module testing:
* Add the expansion board to the PyCom LoPy or WiPy module. Make sure about the orientations.
* hook up the module (USB or via wifi) to your desktop and upgrade the firmware.
* disconnect the expansion/PyCom module from power and only wire up one module.
* Install hardware and sonfware one by one: say the first one is XXX (e.g. BME280)
* copy the dependent XXX_test.py, Config.py and library module XXX.py to resp. XxPy/firmware and XxPy/firmware/lib.
* adjust the Config.py for the right pin setup wiring. And check this twice.
* Click on the *Upload* button of atom to load the scripts into the PyCom module. This will synchronise all files in the firmware directory of your desktop with the PyCom ESP controller.
* fireup XXX_test as follows:
```python
>>>import XXX_test
```
* if not successfully copy/paste the statements of XXX_test.py one by one via atom REPL.

* on success do the next module e.g. PMS7003 wiring and redo the test cycle.
* on success try out `MySense.py` and finally install `main.py`:
```python
    import MySense
    MySense.runMe()
```
* and give feedback

## MySense scripts
The main micropython script which drives the sensor kit is `MySense.py`. Use `main.py` to import MySense.py and run `MySense.runMe()` to run the kit.

The micropython (looks like Python 3) script uses the Adafruit BME280 and BME680 (I2C-bus) python module, SDS011 (Uart 1) module from Rex Fue Feinstaub `https://github.com/rexfue/Feinstaub_LoPy` and Telenor weather station `https://github.com/TelenorStartIoT/lorawan-weather-station` and SSD1306 (Adafruit tiny display SPI-bus).

In the test phase one should not download main.py to the LoPy controller. Use `MySense.py` in this phase instead and rename it to main.py later.
Use (open) the directory `firmware` as base for the atom project and upload all file by pressing the upload key.
On the console prompt `>>>` use the following:
```python
import MySense
MySense.runMe()
```
After this initial test rename MySense.py to main.py. And upload main.py to the LoPy.

## I2C bus errors
The I2C together with SPI will cause I2C bus errors. After using the SPI SSD1306 display before the I2C bus can be used initialize the I2C bus first.

### how to reset the controller
You can delete old firmware using the instruction by PyCom. Usualy you only need to delete all uploaded file as follows:

Use the reset button on the LoPy to get the atom prompt `>>>` and do the following:
```python
    import os
    os.mkfs('/flash')
```
And upload your new files.

How to delete or enable previous firmware? Connect Pin P12 to 3V3: 1-3 sec (safe boot), 4-6 secs (previous user update selected), 7-9 secs (safe boot factory firmware).
P2 - Gnd low level bootloader (needed to update factory firmware upgrade).

The controller can always be reached via the network. Upload wifi (`www.pycom.io`) an empty main.py into `flash` folder with ftp (insecure version) ore `filezilla` (MacOs; can take some minutes to establish connection) in passive mode to `192.168.4.1` and user/pass `micro/python` to obtain access via telnet (or netcat) or USB.

### test PyCom controller
The PyCom will initiate the wifi. Use Wifi AO with pass: www.pycom.io and telnet (192.168.4.1) access user/password micro/python.

Make sure you have to upgrade the PyCom controller first. However upgrading LoPy-4 failed somehow.

Simple test to silence the blue flashing, at the prompt `>>>`:
```python
    import pycom
    pycom.heartbeat(False) # silence the blue flash
    pycom.rgbled(0x99ff55) # some color
    pycom.rgbled(0x000000) # led OFF
```

## MySense controller status
The console will print status as will the flashing led on the LoPy will flash different collors: red to establish LoRa connectivity, blue when LoRa is ready, green when measuremnts are arriving, and blue when data is sent, and white when SDS011 fan is turned off to save the fan and laser as well LoPy is in idle state. LoPy will send every 5 minutes (`sleep_time`) a measurement sample  to the TTN data concentrator.

## controller wiring

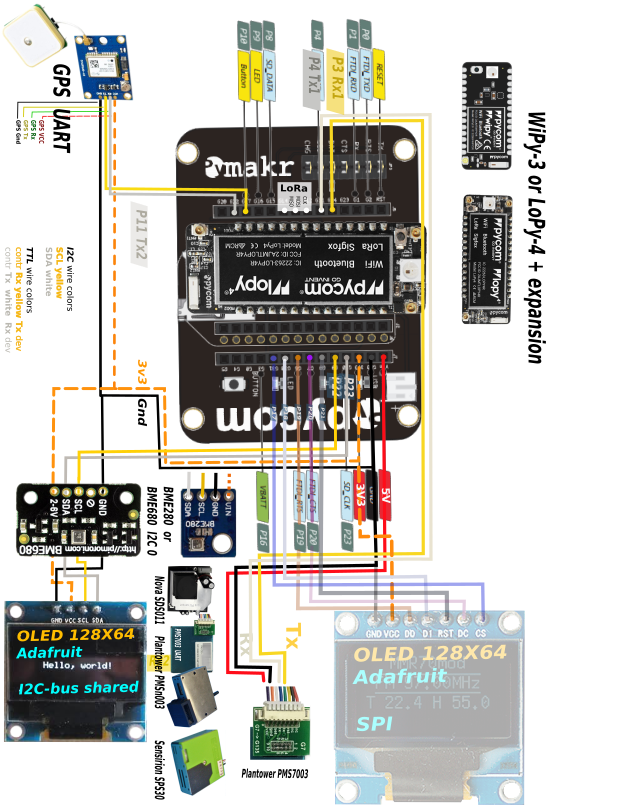
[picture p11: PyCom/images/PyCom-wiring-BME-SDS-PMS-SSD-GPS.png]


See for examples of wiring the `README.LopY.md` (LoRaWan TTN, BME280, SDS011 and SSD1306) or `README.WiPy.md` (wifi MQTT, BME680, PMS7003, SSD1306) readme's.

Its is handy to use a 'connector board': a simple PCB which has a row of say Grove connectors for the sensor devices and 'foot' for the LoPy controller. The electronic scheme using mosfets to power sensor devices and ready scheme to send to a board producer can be found in the documentation directory.

ATTENTION: we discovered that the wifi beacon is causing in some circumstances a 2ms drop of the power to the ESP8266 controller below 3.3V every 100ms interval. Some dust laser sensors are influenced and produce unexpected high measurements because of this. Suggested is to use a good powerfull adapter, and/or apply a 1000 uF capacitor or configure MySense to switch off the wifi after one hour (see Config.py for a how to).

## To Do
Add more sensor modules. The Shiney PPD42NS (unreliable and too much errors), DHT22 and DHT11 (too much peaks and outdoor time to live too short) meteo sensor are depricated. Sensirion SHT31 (only temperature and RH, not very precise).
Note: The Plantower PMS7003 and SPS30 are much smaller and consume less energy as the Nova SDS011 (but it has a nice air inlet). The Plantower PMSx003 has a detachable fan, air tube inlet, cleanable inlet, and is more robust for outdoor application.

## Licensing
If not noted the scripts and changes to external scripts are GPL V3.

## some references
* https://kapusta.cc/2017/12/02/home-made-air-quality-monitoring-using-wipy/

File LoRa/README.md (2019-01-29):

# LoRaWan Long Range Internet of Things
LoRaWan network for sensors coverage is needed to pick up the measurements data. Commercial coverage is provided. This might be a solution for a very limited amount of measurement nodes, but the advantage of using the free The Things Network should be considered due to technical arguments.

One LoRa gateway (a data forwarder) will have a coverage with an outdoor antenna will be 2.5 km or much more if there is free sight.
A commercial LoRa gateway will costs about € 750-1500. A DIY LoRa gateway is easy to configure for about € 120 (Pi/RAK831) up to € 170 (Pi/IC880A-SPI).

## DIY LoRa gateway
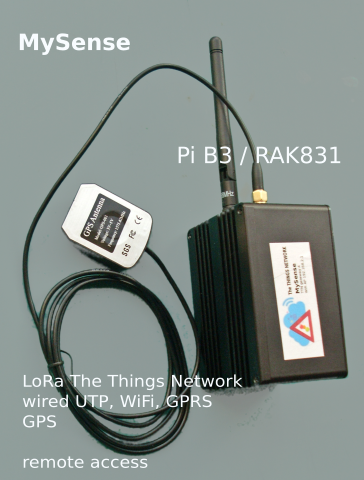
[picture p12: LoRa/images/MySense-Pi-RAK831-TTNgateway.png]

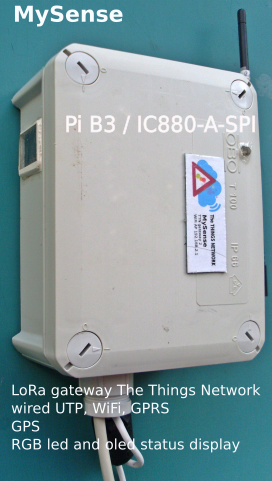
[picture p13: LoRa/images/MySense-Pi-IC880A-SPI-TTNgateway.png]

To build a DIY gateway one will find on internet many good instructions:

* <a href="https://webshop.ideetron.nl/iC880A-SPI"> Pi/IC880A-SPI</a>  € 115.- a quick start guide

* <a href="https://nl.aliexpress.com/item/RAK831-Pilot-Gateway-SX1301-Raspberry-Pi3-GPS-met-complete-behuizing-voor-professionele-demonstratie-set-up/32883987457.html">Pi/RAK831</a> via AliExpress € 120.- - 170.- with aluminium (indoor) housing

* <a href="https://github.com/ttn-zh/ic880a-gateway/wiki"> Github wiki</a> from zero to lorawan in a weekend

* <a href="https://www.thethingsnetwork.org/forum/t/the-hard-rak831-cafe-part-2/10576">the RAK831 way<a>

* <a href="https://www.thethingsnetwork.org/docs/gateways/rak831/">how to build lora gateway with rak831a</a>

* <a href="https://www.thethingsnetwork.org/forum/t/rak831-vs-ic880a-spi/12423">rak831 versus ic880a-spia</a>

The use of a header board (the wiring is just the board) is advised. If one uses wiring make sure to use a grounded shield for the data wiring. For both types of boards the software is very similar (SIMTECH).
The Pi software will use `/var/log/syslog` as logging file. This will grow and limit the lifetime of your SDcard. Hense an extra Python script to avoid this a bit, as well provide visual feedback of the status of the gateway.

With the MySense RPi `INSTALL.sh` configuration script one will find options to improve the functionality of the gateway:
- enable and use a GPS module
- automatic choice of interconnectivity: wired, WiFi, or GPRS (mobile)
- enable gateway as WiFi Access Point to configure local WiFi and do remote system configuration
- install remote access via internet for updating the software (ssh, Weave, TeamView, etc.)
- use of visiual feedback via oled display (SSD1306) and RGB led. See docs/display.md
- install webmin (remote system configuration)

## LoRa gateway script extensions
* *start.sh* This shell script is extended with commands to identify internet access, adjust GPS localisation configuration on the fly, provide visual feedback on the oled display and RGB led and limit the forwarder logging as well give statistical visual feedback.
* *GatewayLogDisplay.py* a log filter and visualisation of status and traffic statistics on the oled display and RGB led server `MyDisplayServer.py' (see RPi directory, install this script with INSTALL.sh).

## Concentrator errors
A frequent error `ERROR failed to start concentrator` is raised on the different fora. As more detailed of the rerason for the errors in the concentrator software is lacking some hints may be usefull:
* make sure the Pi has a good powersupply of 5V DC and is able to deliver 2.1A. Many adapaters say they are 2.1A but the reality is different.
* make sure the hardware reset pin 22 or other is really connected to the concentrator board and a separate script is doing the reset.
* make sure the user has GPIO full access rights.

Sometimes the errort is about wrong calibration version. The upload of the firmware probnably went wrong. E.g. use shielded cabling to the concentrator. Just a reboot may also cure this...

Make sure when you powerup the antenna is connected. If not it may destroy the concentrator board.

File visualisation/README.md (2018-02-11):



### STATUS
operational 2018/01/12

### DESCRIPTION
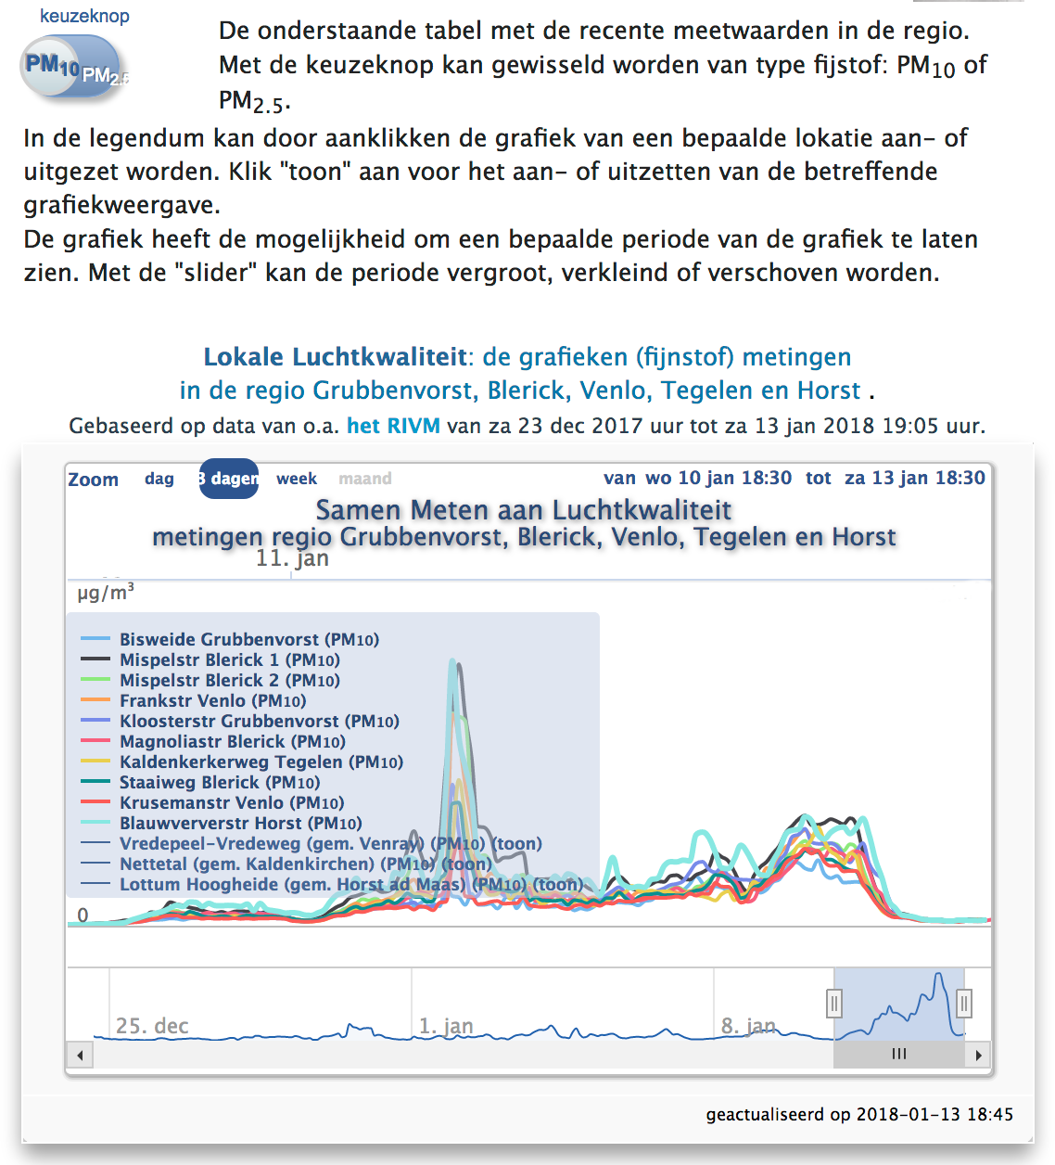
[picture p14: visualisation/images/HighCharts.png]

The ChartsPM.pl Perl script will generate the HTML body of a webpage with using HighCharts graphs for visualisation of measurments. The measurments are taken from a MySQL database using measurments values over a period of time and location meta information.

In debug modus a full HTML page will be gebarted, so the graphs can be locally shown with a browser.

### USAGE
Use the perl script with --help so look into the many commandline options to choose from.

The script has the possibility to generate two or more charts on one webpage. A button will be generated which allows the end user to select a particular chart of graphs.

```shell
    DBUSER=me DBPASS=acacadabra DBHOST=localhost perl ./ChartsPM.pl \\
        --pollutants pm10,pm25 --buttons PM10,PM2.5 \\
        --debug --verbose --web /tmp \\
        --last now --output OutputPage \\
            Vuurwerk_Sensorkit1 Vuurwerk_Sensorkit2 HadM
```

* DBUSER etc. defines the database credentials
* buttons/pollutants to switch from PM10 (dflt) table into PM2.5 table.
* Option `--debug` will force debug modus (complete HTML page OutputPage.html in the directory /tmp) 
* last defines measurements available up to now, default period is 3 weeks

### APPLICATION
The graphs on the chart will allow to visualize the correlation between different sensorkits as well sensors.

Experimental: the `--correct` option will enable an apllication of a correction coeeficient to PM measurments. The rel. humidity of the station or neighbour will be used to apply a correction. The coefficient is a best fit calculated from PM measurments and humidy of a reference station. This is fully experimental yet.

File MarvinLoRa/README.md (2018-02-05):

## Marvin LoRa controller based sensor kit
### STATUS
2017-12-24 operational via TTN Europe and MySense.

### DESCRIPTION
The sensorkit is build with a Marvin LoRa controller (ca  84 euro), an dust SDS011 sensor (ca 20 euro) and a waether  DHT22 (ca 10 euro).
This sensorkit fits in a small outdoor V220 connectionbox.

The measurments are sent via TTN Europe and sent to the TTN Europe datacontratoer. One needs to obtain an application account with TTN Europe to download the data from thgeir TTN MQTT server. See also the MyTTN-MQTT.py module in MySense to download the data with MySense.

The firmware is developped by Jelle Adema Fontys GreenTechLab Dec 2017 under GPL V4 Open Source license agreement. The dust measurment project took part in the RIVM Vuurwerk 2017 measurment project with ca 80 sensorkits distributed over the Netherlands.
References:
* <a href="http://behouddeparel.nl/?q=vuurwerk2017">Graphs of measurments region North Limburg Holland</a>
*  <a href="https://www.samenmetenaanluchtkwaliteit.nl/vuurwerkexperiment-20172018">RIVM Vuurwerk 2018 project</a>
* <a href="http://samenmeten.rivm.nl/dataportaal/">Data Portal RIVM</a>
* <a href="https://github.com/SamenMeten/Air-quality-effects-Fireworks-using-Shinyei">Adafruit Feather with Shiney sensor firmware</a>

### FIRMWARE
Change the TTN keys in the ino files to the settings at the TTN data concentrator.

Add the Marvin LoRa controller to the Arduine IDE controllers.
Point Arduino IDE to the ion formware files and and upload the firmware to the Marvin controller.

### HARDWARE
The Marvin LoRa uses Grove connectors: 3X analogue, 1 X digital and one I2C bus.

SDS011 Rx -> P15, SDS011 Tx -> P16. Pins are on the back of the Marvin board.

DHT22 is connected with a Grove connecytor to the second (analogue) connector position on the Marvin board.

Wiring:
* SDS011
```
    |_._._._._._| SDS011 connector
      | | | | |
     nc R B b y   R=Red-Vcc B=Black-Gnd b=Blew-Rx y=Yellow-Tx
```
* Marvin Uart backside board, 6 pins at board side
```
    ---------
    | 1  2R |             2 Red-VCC
    | 3B 4Y |  3 Blew-Rx  4 Yellow-Tx
    | 5  6B |             6 Black-Grnd
    ---------
_______________board side
```
* DHT22
```
              -----
   Gnd black -|    \
   Vcc red   -|    o|
       nc    -|     |
   sig yellow-|    /
              -----
```
* Marvin Lora Grove connector for DHT22
```
      -----------------------------
      |  ||  ||  XX  ||   ------- |   DHT22 Grove connector
      |  ||  ||  XX  ||   | RN  | |   . Black-Grnd
      |                   |     | |   . Red-VCC
      |  Marvin LoRa      ------- |   . White
      -----------------------------   . Yellow-signal
```
### ANTENNA
The Marvin has an on board antenna. Make sure if installed that one of the antenna end point is pointing into the direction of the TTN data forwarder.

### TEST
Look at the TTN data concentrator dashboard to see if data is forwarded to the TTN data concentrator.

### PAYLOAD
If the LoRa payload fields are not defined, the `MyTTNMQTT.py` input handler will unpack the payload into the expected format as defined by the Marvin firmware.

### META DATA
The GPS coordinates of the sensor kit are taken from the manual entered TTN data concentrator profile `devices`. However the coordinates as well more meta data can be defined from the meta data file of MyTTNMQTT. Make sure one has defined the TTN device names as well in the MyTTNMQTT config part as well.

Serial numbers is strange with the Marvin controller. So these can be defined from the meta desciption file of MyTTNMQTT or are calculated from a hash of the topics/device naming of TTN.

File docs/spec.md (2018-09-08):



# gas sensors from Spec
## Status
In beta test since 29th of May 2018

## Description
The gas sensors from Spec
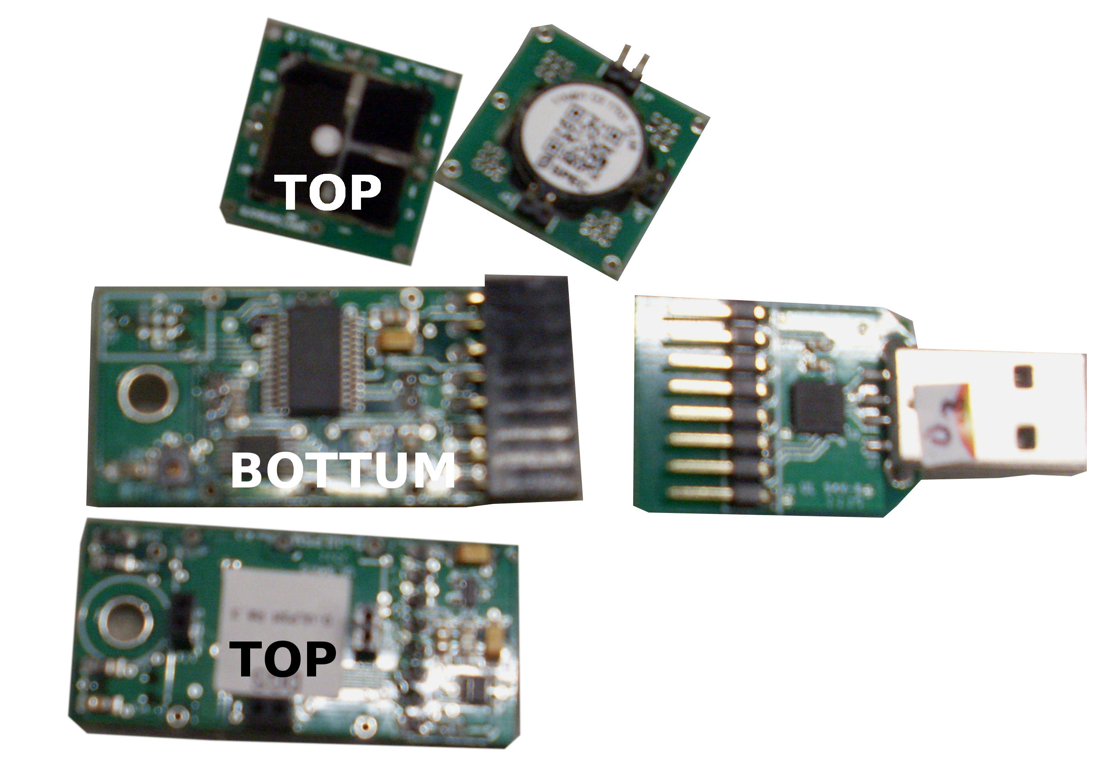
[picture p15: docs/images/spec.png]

is simple to connect via a TTL USB. The serial output is 9600 baud, and input (commands)/ output are in ascii. Default on poweron the Spec gas sensor will be in standby mode. Any input character will put the module in active mode smapling internally PPB values and averaging (dflt disabled) them. The manual dictates: By sending a 'c' the module will send regularly a line of values to the host. By sending a '\r' character the module will respond with a measurement line. 
Note: we tried to read the eeprom but did not succeed.
The module needs one hour to stabalize.

A module has three parts: the Spec sensor (O3, NO2, or CO), the TTL interface with the eeprom, and the USB TTL adapter. All input is read in parrallel (threaded input).

Cost pricing varies between € 50 and higher (e.g. NO2+UL G4V board+TTL-USB: DigiKey € 66.- excl. import tax € 17.22). Make sure one uses an serial USB converter to interface to the 3V3 based TTL serial interface of the module. MySense used `Cygnal Integrated Products, Inc. CP210x UART Bridge / myAVR mySmartUSB light`. See the config example for the appetrn to recognize which USB has the gas adapter.

## WARNING when using GPS serial using Pi TTL pins
It may happen that if gps is enabled and imported in MySense the Spec module does not operate smoothlhly (no serial data read, without error indications). Solution: in `/etc/default/gpsd` set USBAUTO to false and add `-b` (only read) for *gpsd* or if it does not help disable gps in `MySense.conf` fully and disable gpsd daemon.
Or use GPS serial reads via USB. If so make sure the USB path name survives a reboot.

## Configuration
### hardware
As there maybe more as one Spec gas sensor connected to the Pi MySense will need a way to get all the serial USB adapters. Plug in the USB adapter of a Spec sensor. Use `lsusb` command to get an overview before and after the USB adapter is connected. Here the difference as example:
```
...
Bus 001 Device 009: ID 10c4:ea60 Cygnal Integrated Products, Inc. CP210x UART Bridge / myAVR mySmartUSB light
Bus 001 Device 008: ID 10c4:ea60 Cygnal Integrated Products, Inc. CP210x UART Bridge / myAVR mySmartUSB light
...
```
Denote the idProduct (e.g. "ea60") and idVendor (e.g. "10c4"). And create the following udev rule in in the file `/etc/udev/rules.d/50-Sensor.rules`:
```
ACTION=="add", KERNEL=="ttyUSB*", ATTRS{idVendor}=="10c4", ATTRS{idProduct}=="ea60", MODE="0660", GROUP="dialout", SYMLINK+="SPEC%n"
```
After a reboot do a test:
```shell
ls -l /dev/SPEC*
```
It should show something like:
```
lrwxrwxrwx 1 root root 7 May  9 16:31 /dev/SPEC1 -> ttyUSB1
lrwxrwxrwx 1 root root 7 May  9 16:31 /dev/SPEC2 -> ttyUSB2
lrwxrwxrwx 1 root root 7 May  9 16:31 /dev/SPEC3 -> ttyUSB3
```

You need to know the S/N number of the gassensor to discriminate between the gasses.
Use the following small python script for this and to check if the sensor is working:
```python
import serial
from time import sleep
try:
  serial = serial.Serial("/dev/SPEC1", baudrate=9600,
            timeout=5,writeTimeout=1,
            stopbits=serial.STOPBITS_ONE, parity=serial.PARITY_NONE,
            bytesize=serial.EIGHTBITS)
  serial.write('\r')
  print("Spec S/N:",serial.readline().split(' ')[0])
except:
  print('Spec USB not found or write/read error')

# and read the eeprom
print('Try to read the EEprom')
serial.write('e'); sleep(1); serial.write('e')
while True:
  line = serial.readline()
  if line.find('=') < 0: break
  print(line[:-2])
  if line[:4] == 'Sens': break
```

### MySense configuration
Make sure you define the lists `fields`, `unit` and `serials` of Conf configurations.
E.g. `Conf['fields'][0] = 'no2'`, `Conf['units'][0] = 'ppb'` and `Conf['serials'][0] = '0123456789' is the serial number as in the output of the USB sensor.

MySense `MySPEC.py` will look for the available gas sensors in a similar way and will detect which gas sensor is attached via a look at the eeprom readout or serial number as is configured in MySense.conf.

* `type` dflt: Spec ULPSM, type of sensor module
* `usbid` dfld: SPEC, pattern as identified from `ls -l /dev/` for interface
* `raw` output also raw measurement values (dflt False)
* 'is_stable` amount of secs (dflt 0) to wait begore measurements are shown (1 hour?)
* `omits` list of field names to omit in output, dflt: nh3,temp,rh
* `prefix` (boolean, dflt False) prepend field names with 3 char of type, e.g. spe_temp
* `interval` interval of measurement sample dflt 60 secs.
* `debug` be more versatile e.g. print output from serial interface
* `bufsize` size of internal array of measurements: every read (read period) is sliding average of sample values 
* `sync` boolean: do not use input threading, dflt: False

## PPB to ug/m3 conversion
If the unit is defined as ug/m3 the Spec PPB value of the measurement will be converted from PPB to ug/m3.
In the conversion MySense will use the temperature value of the Spec sensor.

## References
* http://www.spec-sensors.com/wp-content/uploads/2017/01/DG-SDK-968-045_9-6-17.pdf specification of the API
While testing the Spec input module no commands were honored. On any character sent the sensor reacted by sending one measurement.

## Correlation test
Output has been tested against reference sensors at GGD Amsterdam early 2017. They look good but there is a need to retest after an outdoor period.

The Spec gas module will do the conversion from mVolt and ref mVolt towards the ppb values. We did not succeed to "zero" the Spec module in order to calibrate the ref mVolt. The MySense software will not show negative ppb values (values are forwarded as None values). This might cause that ppb values less as zero may result in false values. To compensate this one is suggested to use the calibration support.

Denote that the Spec module needs ca 60 minutes to establish a more reliable output of measurements.

## ISSUES
There is an issue on serial line data corruption with the Cygnal Intergrated Producs USB UART. The issue diappears when the GPS is disabled in MySense. GPS data is read via a GPS deamon. Not sure what the cause is.

Make sure the Pi power adapter is able to provide more a 1.5 A! A warning signal maybe the power icon on the startup screen of the Pi.

## Dependences

## Usage
MySense tries to read the eeprom to identify wich serial interface with the USB adapter from Cygnal Intergrated measures which gas. On failure one measurement is read to lookup the gas ID via the serial number (on the back of the gas sensor part). Only the configured gas fields are added for measurements.

Serial input is read (9600 baud, 8-bit, no parity, 1 stop bit)  on interval basis with the request for input command. The serial line output of the TTL is as follows (all integers):
```
SerialNr,PPB gas, temperature oC, rel. humidity %,
    SDAraw, Traw, RHraw, days, hours, minutes, seconds \r\n
```
For every USB gas sensor a thread is initiated measuring at interval periods PPB, temp and RH (average) values and averaging them. `BUFSIZE` will limit the max of measurements by the sensor.

MySense will recognize all USB interface and join this withe gas ID automatically. Make sure to use a unique serial TTL USB converter.

Output to MySense main part example:
```json
    { 'time': seconds, 'o3': ppb, 'no2': ppb, 'co': ppb }
```

## MySense module Configuration
* `input` boolean will define to enable the sensors read.
* `type` will identify the Spec gas sensor ID dflt Spec ULPSM
* `usbid` will identfy the USB serial adapter, dflt Silicon_Labs_CP210
* calibrations, fiels, units is an array to identify calibration factors, names, and units of measuements.
* `raw` will enable raw values to output via MySense
* `is_stable` is amount of seconds to wait for measurments after power on, dflt one hour.
* `omits` is gn array with names of gasses to omit
* `data` list of names to pick up from sensor modules, dflt ppb, temp, rh (None is disable this field)
* `interval` interval to read measurments by the thread, dflt 60 (one minute)
* `bufsize` is size to take average of measurments by the thread, dflt 30
* `sync` enable input threading (gas seanor readout is done in parallel, dflt enabled.

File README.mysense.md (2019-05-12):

# MySense architecture
MySense overview:

the building blocks

## STATUS
2017/02/08
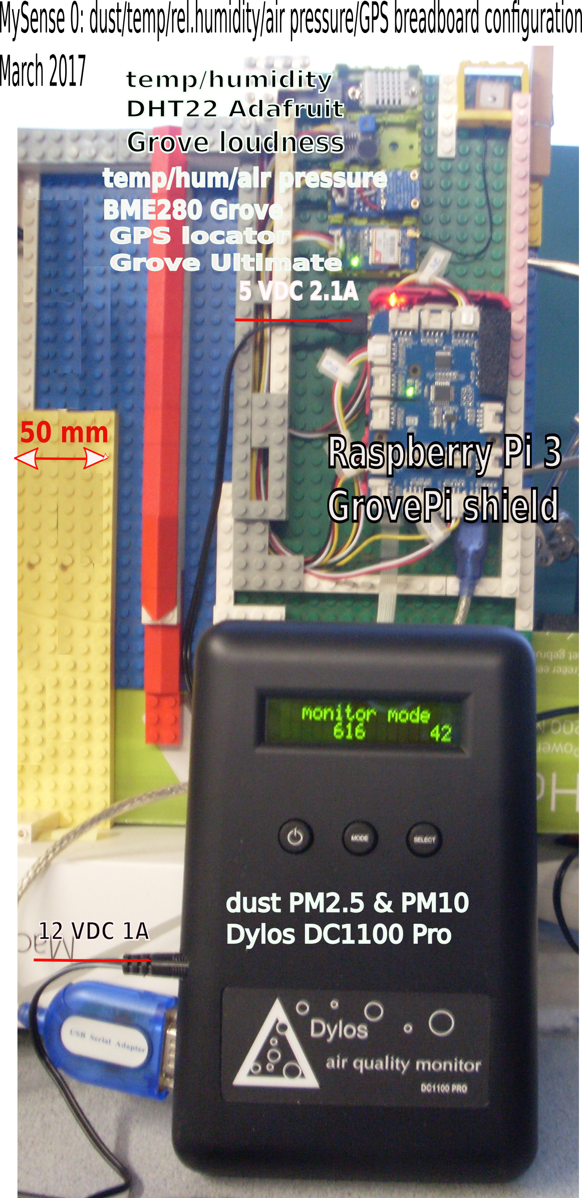
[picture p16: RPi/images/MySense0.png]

STATUS: BETA operational

## USAGE:
MySense is started up from e.g. from user `ios` in `/home/ios/MySense/` installation folder as follows:
```bash
   cd /home/ios/MySense/
    python ./MySense.py start
```
The command `python ./MySense.py stop` will stop the process. The argument `status` will show if MySense is running or not.

If for installation `INSTALL.sh` is used the file `MyStart.sh` will be executed on powering on the Pi and after a wait for internet connectivity MySense will be started automatically.
If the poweroff switch is installed the command `/usr/local/etc/poweroff` started at boot time witll watch the poweroff button: 
* less as 5 seconds pressed and no internet connectivity PWS will be searched for wifi access. If no wifi access is found MySense will go into wifi access point modus. Login with the user/password shown on the display.
* less as 10-20 seconds pressed MySense will reboot
* more as 20 seconds pressed MySense will poweroff the Pi.

`INSTALL.sh` may also be used to install LoRa gateway software on the Pi, e.g. `INSTALL.sh USER DISPLAY GPS WATCHDOG INTERNET WIFI WEBMIN TTN_GATEWAY`. Optionally add *GPRS, SMS, BUTTON*, and/or *BLUETOOTH*.

If the on board WiFi supports WiFi Access Point this will be optionaly enabled (dflt: enabled). This will allow to access the Pi via wifi SSID *MySense* and passphrase *acacadabra* (CHANGE THIS e.g. via RaspAP webmin interface or via `/etc/hostapd/hostapd.conf`!).
The `INSTALL.sh` may install by defaults the *RaspAP* package (`INSTALL.sh WEBMIN`) using the *lighttpd* web service, an web gui for network configuration as well on the WiFi Access Point via web credits user *admin* and the default password *secret* (CHANGE THIS immediately).

Note that the main python program *MySense.py* may need to operate fully a config or init file.
The file is looked up as program name extended with .conf: eg `MySense.conf`
The init file may also be defined by the environment variable (name in capitals) program *name*. Eg. `MYSENSE=/etc/ios/MySense.ini`.
See the config file example for all plugin sections and plugin options.

A *note about USB serial cables or better adapters*
<br />
USB (mainly serial TTL) devices are discriminated via the product ID in order to detect the ttyUSBn port. In the `MySense.conf` configuration file with the option `usbid` one can de fine a search pattern to find the correct USB connector. However this will only work if one uses different manufacture id's for each USB serial connector.
## PLUGINS
MySense is build in a Lego fashion: as well physical Lego blocks as programmically: input plugins and output channel modules.
All plugins have the name *MyPLUGIN.py*.
python ./MySense.py --help will provide a short command line options.
Use it to see how to overwrite (disable or enable) the input and output plugins.
And how to get more logging output: eg "-l debug"
Not all plugins have been tested deeply (e.g. broker, gspread, gas, dht).
Operational plugins:
* input: Dylos, Shinyei (connected via Arduino controller) and SDS011 dust sensors, meteo (SHT31, DHT11/22 and BME280/680 sensors, Spec or AlphaSense gas sensors.
* output: MQTT: mqttsub (subscribe) and mqttpub, InFlux (publicise), db (mysql), CSV and console.

## Adding a NEW PLUGIN
Adding an input or output plugin named xyz is easy.
Keep the setup from any other plugin and create the MyXYZ.py script.
And add the xyz as section to the init/config file.
Use Conf as global var to import options for the plugin from the init file.
The input plugin needs the attribute getdata() and returns a dict with data.
The output plugin is called with the attribute publish(dict). Where dict has the keys ident, data and internet.
And returns True of False.
A plugin with the Conf key hostname will be denoted as internet access enabled.

Use pdb (python debugger) to step through the script(s) if anything goes wrong.

All input and output pluging should be able to run with pdb in a standalone mode for testing the module. Look for the __main__ part in the python script.

MySense plugins are imported as modules when the are defined in the MySense.conf configure/init file on startup. So if the plugin is not needed it will not be imported and there is at that moment no need to have the dependent python library module installed.

## INTERNET
All access via internet is guarded by user/password or signature credentials.
To enable access for input or output plugins, say the xyz plugin one need to define the user/password (gspread needs a credential signature file). The definition of the credential happens at the server site. MySense acts always as a client, eg to mosquitto (mqtt) broker, but is able to act as gateway: input mqttsub, output as mqttpub.
The password can be defined in the init/config file (not recommanded), as well be overwritten by the command environment variable XYZHOST, XYZPASS, en XYZUSER for the plugin "xyz".

## INSTALL
Every MySense plugin modules do some python module imports.
They need to be installed in the Pi if one uses a MySense plugin module..
If pip is not installed do so with: sudo apt-get install python-pip
Install missing modules with sudo pip install <module name>

Installation of library dependencies one can use the `INSTALL.sh help` script.

## TEST configuration and plugins
The sensor input plugins and output plugins can be used as standalone scripts. With the Python debug (`pdb MyPlugin.py`) one can test the plugin independent from the main MySense.py script. One may have to change the Conf hash table definitions  at the end of the script to a local situation.

## DEPENDENCES
This is a list of pyhon modules of imports done by various plugins:
Non standard modules to be installed with e.g. sudo pip install module
* configparser:	MySense.py
* gspread:	MyGSPREAD.py
* oauth:	MyGSPREAD.py

* mysql:	MyDB.py
Installed with: sudo apt-get install python-dev libmysqlclient-dev build-essential python-dev (needed to do a manual DB access to the MySQL (remote) database.
and sudo python3-mysql.connector python-mysql.connector
If the MySQL database needs to be installed on the Pi as server see e.g. https://www.stewright.me/2014/06/tutorial-install-mysql-server-on-raspberry-pi/

* gps:	MyGPS.py
Install gpsd deamon and client: sudo apt-get install gpsd python-gps
paho.mqtt.client:	MyMQTTPUB.py MyMQTTSUB.py
installed by: git clone https://github.com/eclipse/paho.mqtt.python.git
and `sudo cd paho.mqtt.python; python setup.py install`.
Standard modules installed with Jessie Pi OS:
Check this manually by the command "python"
```
>>> and copy/paste the next lines
import argparse,atexit,calendar,csv,datetime,email
import fcntl,getpass,grp,json,logging,os,pwd,random
import re,requests,serial,signal,smtplib,socket
import subprocess,sys,threading,time,urllib2
<cntrl d>
```

### List of plugins
Here is the list of the plugings and imported python modules:
* argparse:	MySense.py
* atexit:	MySense.py
* calendar:	MyGPS.py
* csv:	MyCSV.py
* datetime:	MyCONSOLE.py, MyCSV.py, MyDB.py, MyEMAIL.py, MyGPS.py, MyGSPREAD.py, MySense.py
* email:	MyEMAIL.py
* fcntl:	MySense.py
* getpass:	MyEMAIL.py
* grp:	MySense.py
* json:	MyBROKER.py, MyMQTTPUB.py, MyMQTTSUB.py
* logging:	MyLogger.py
* os:	MyCSV.py, MyGPS.py, MyGSPREAD.py, MyMQTTSUB.py, MySense.py
* pwd:	MySense.py
* random:	MyInternet.py
* re:	MyDYLOS.py, MyInternet.py, MyMQTTSUB.py, MyRSSI.py, MySense.py
* requests:	MyBROKER.py
* serial:	MyDYLOS.py, MySDS011.py, MyPMS7003.py
* signal:	MySense.py
* smtplib:	MyEMAIL.py
* socket:	MyBROKER.py, MyEMAIL.py, MyInternet.py, MyMQTTPUB.py, MyMQTTSUB.py
* subprocess:	MyDYLOS.py, MyInternet.py, MyRSSI.py, MySense.py, MySDS011.py, MyPMS7003.py
* sys:	MyBROKER.py, MyCONSOLE.py, MyDB.py, MyLogger.py, MyMQTTPUB.py, MyMQTTSUB.py, MySense.py
* threading:	MyGPS.py, MyRSSI.py, MySense.py
* time:	MyCONSOLE.py, MyCSV.py, MyDB.py, MyGPS.py, MyGSPREAD.py, MyInternet.py, MyMQTTPUB.py, MyMQTTSUB.py, MyRSSI.py, MySense.py
* urllib2:	MyInternet.py

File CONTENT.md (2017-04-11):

# Overview of files
## General Documentation
* README.md     general README
* README.i2c    I2C bus usage for sensor modules
* README.mqtt   installation of mosquitto server (optional)
* README.mysense MySense.py usage help
* README.pi     Pi3 Jessie OS installation guide
## Plugin Documentation
docs directory:
## install/library (install dependencies)
* INSTALL.sh    Installs (bash) the dependencies and OS support: try `./INSTALL.sh help`
### sensors
* bme280.md     Adafruit / Grove BME280 humidity/temp/air pressure sensor  
* dht.md        Adafruit / Grove DHT11/22 humidity/temp sensor
* dylos.md      Dylos DC1100 Pro dust sensor
* gps.md        Grove Ultimate GPS locator
* grove_dB.md   Grove loudness sensor
* shinyei.md    Grove Shinyei PPD42NS dust sensor
### output channels
* db.md         MySQL database output channel
* gspread.md    Google gspread output channel
* http          To be done: template
* console       to be done: just console output
### Pi stuff
* led.md        led/relay/button for Pi poweroff/wifi access point search
* wifi.md       wifi/utp client and wifi access point installation
* backdoor.md   install remote access to the Pi
* grovepi.md    GrovePi shield
## Python scripts
### main
* help          Try: `python ./MySense.py --help`
* MySense.py    Main python script: command line handling, input/output plugins
* MySense.conf  MySense configuration/init file
### input plugins
* MyBME280.py   BME280 humidity/temp sensor
* MyDBGROVE.py  Grove loudness sensor
* MyDHT.py      Grove humidity/temp sensor
* MyDYLOS.py    Dylos DC1100 Pro (USB serial) dust sensor
* MyMQTTSUB.py  Input from Mosquitto server (relay/broker function)
* MyGPS.py      Grove GPS sensor
* MyARDUINO.py  Connection to Arduino Uno (for Shinyei)
* MyArduino.ino Firmware for Arduino Uno with Shinyei PPD42NS dust sensor
* MyRSSI.py     Input wifi signal strength
### output channels (plugins)
* MyMQTTPUB.py  Output channel via Mosquitto (MQTT)
* MyCONSOLE.py  Output channel to console (or file)
* MyDB.py       Output channel to MySQL database
* MyCSV.py      Output channel in CVS format
* MyGSPREAD.py  Output Google gspread (credential access not tested)
* MyEMAIL.py    Output (description sensor kit) via email
* MyBROKER.py   HTTP output channel (template)
### support modules
* MyLogger.py   Logging of MySense info
* MyInternet.py Use of internet connectivity
* MyI2C.py      Sensors via I2C bus
* MyThreading.py Multi threading library for input plugins
### OS support scripts
* MyLed.py      Script to use led/relay/button
* statistics/Calibrate.py Script to calculate best fit polynomial between two measurement data 
## testdata
* dylos-input.txt Debugging MySense.py test data (imitating Dylos sensor)

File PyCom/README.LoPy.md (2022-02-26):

## Description
The LoPy is a low cost (€ 35) ESP controller which support micropython and has wifi, Bluetooth and LoRaWan or SigFox capabilities.
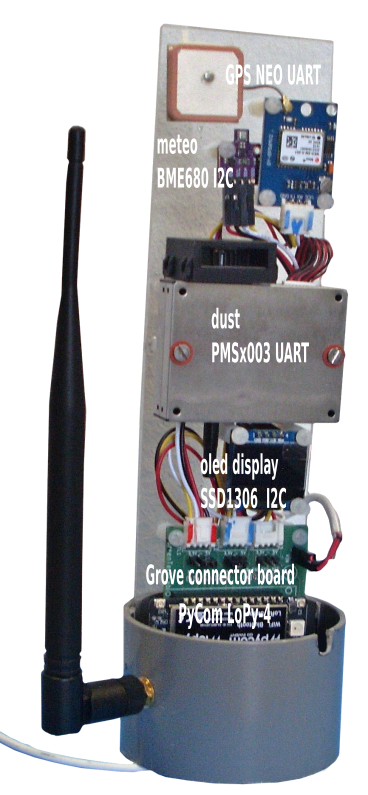
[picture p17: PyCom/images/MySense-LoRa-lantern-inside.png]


MySense is using the PyCom expansion board V3 (€ 16) for the manufacturer firmware flashing, developemnt wiring and programming. For operations we use an own expansion PCBV board with Grove connectors to eliminate wiring and connection errors.

MySense operates with TTN as LoRa dataconcentrator. MySense will check every 2.5 seconds (maximal 20 times) if a *join* with TTN LoRa network was succesfull.
A red flash will denote there was not a join yet.
On failure it will skip to send data measurements to TTN and will continue to show locally on the olded display the measurements.

For installation, and firmware update see:
* reference: https://docs.pycom.io

## LoPy-4 BME/SHT/GPS/SDS/PMS wiring

With the PCB connector board one may easily connect the sensor modules. There are 3 TTL and 3 I2C Grove connectors on this board. With a female Dupont socket one can easily connect to the sensor module. The MySense softwaree will automicaly detect which sensor modle is connected to the TTL ports and I2C ports.

Orientate the LoPy with the flash light up (if you use the recommanded development shield the small USB connecter will be on top). The name `pycom lopy` will face to the left side. The left side pins are numbererd top down as RST, P0, P1 ,...,P12.
The right side pins top down are numbered as: Vin V3.3/V5, Gnd, 3V3, P23, P22, ..., P13.



### TTL/UART devices connections
SDS011/PMS7003/PMSx003 TTL1 5V (LoPy TTL3) UART connection:
* PM Gnd (black) -> LoPy Gnd (on right side 2nd pin, same pin as for BME)
* PCB V2 (PCB BWLvC V2) to be checked with Config.py!
** PM V5 (red)    -> PCB V2: LoPy P19 PWR (on right side)
** PM Rx (yellow) -> PCB V2: LoPy P3 / Tx1 (on left side, 5th pin from top)
** PM Tx (white)  -> PCB V2: LoPy P4 / Rx1 (on left side, 6th pin from top)
* PCB V1 (PCB V1 GTL V1/V2) default (2019-02-27)
** PM V5 (red)    -> PCB V1: LoPy P20 PWR (on right side shared with console) dflt
** PM Rx (yellow) -> PCB V1: LoPy P10 / Tx1 (on left side, 5th pin from top) dlft
** PM Tx (white)  -> PCB V1: LoPy P11 / Rx1 (on left side, 6th pin from top) dlft

Grove GPS TTL2 3V3 (LoPy TTL2) Uart connection:
* GPS Gnd (black) -> LoPy Gnd (on right side, shared pin)
* GPS Vcc (red) -> LoPy 3V3 P9
* PCB V2 (PCB BWLvC V2) to be checked with Config.py!
** GPS Rx (green) -> LoPy P12 / Tx2 (on left side, 1st pin from bottom)
** GPS Tx (yellow) -> LoPy P11 / Rx2 (on left side, 2nd pin from bottom)
* PCB V1 (PCB GTL V1) default
** GPS Rx (green) -> LoPy P4 / Tx2 (on left side, 1st pin from bottom)
** GPS Tx (yellow) -> LoPy P3 / Rx2 (on left side, 2nd pin from bottom)

Console TTL TTL3 (LoPy TTL1) Uart connection (default):
* Gnd (black)
* 5V/3V3  (red) V1: P9 PWR used by TTL2 due to HW bug)
* Rx: P1
* Tx: P0

In `Config.py` one is able to define the pins. MySense will automatically detect on the defined UART pins the GPS and dust connector.

### I2C devices connections
SHT31/BME280/680 I2C  connection (default I2C address):
* BME Gnd (black) -> LoPy Gnd (on right side, same pin as for SDS)
* BME V3/5 (red) -> LoPy 3V3 (on right side, 3rd pin from top)
* BME SDA (white) -> LoPy SDA (on right side, 4th pin from top)
* BME SCL (yellow) -> LoPy CLK (on right side, 5th pin from top)
The oled SSD1306 display I2C bus is connected parallel to each other.

### Optional SPI device deprecated
Optional SSD1306 SPI connection (using GPIO pins):
* SSD CS (blue) -> LoPi P18
* SSD DC (purple) -> LoPy P20
* SSD RST (gray) -> LoPy P21
* SSD D1 (white) -> LoPy P17
* SSD D0 (orange) -> LoPy P19
* SSD VCC (red) -> LoPy 3V3 (shared with BME280)
* SSD GND (black) -> LoPy Gnd (on right side, same pin as for SDS)

### configuration pins
* P13 (Hall magnetic sensor) Use REPL mode (only PCB BWLvC V2)
* P17 Accu voltage (PCB V2) near TTL sockets (if 0V and deepsleep P18 closed: go into REPL modus)
* P18 Closed (gnd) use deepsleep (on PCB near I2C sockets)

Warning: SPI oled display seems not run with PyCom firmware 1.17.3.b1 (April 2018). A previous version was running ok.

## Housing
We used PVC pipe components available from DIY nearby warehousing. Basically an PVC air outlet pipe of 80 mm diameter, a 75 mm connection socket and a plexyglas for the sensor frame 3 X 61 X 230 mm.
For a cutting guide and drill mask see the SVG (Inkscape) files:
* images/MySense-LoRa-layout-lantern.svg
* images/MySense-lantern-pipe-cutting.svg

## Features: Remote command handling
A simple remote command via LoRa has been implemented: 
* ?: send configuration and GPS location info 
* O: switch oled display off
* d: enable to send dust raw data
* D: disable to send dust raw data
* m: enable to send raw meteo data
* M: disable to send raw meteo data
* S: stop
* i<unsigned int value>: value should be > 60 seconds, defines new sample interval time
* more to do
On a reboot the remote command is lost. (To Do: survive a reboot).

## Data collecting: TTN how to
You need to set up an account and password with The Things Network: https://thethingsnetwork.org/

Via the `console` add an application with a name: https://console.thethingsnetwork.org/applications/add
If done so, click on the added application name and register a device: 
://console.thethingsnetwork.org/applications/NAME_APPLICATION/devices/register
Write down the following OTAA information to be entered in the Config.py:
```python
dev_eui = "XXXXXXXXXXXXXXXX"
app_eui = "YYYYYYYYYYYYYYYY"
app_key = "ZZZZZZZZZZZZZZZZZZZZZZZZZZZZZZZZ"
```
MySense is also supporting the ABP mode with LoRa. Just define the ABP keys. If available MySense will first try OTAA and if unsuccessfull (or if keys are not defined) will try ABP mode.
If you want to access (and you want to do that during tests) the TTN MQTT server you need to write down the App ID (NAME_APPLICATION) and Access Key (bottom of the App Id page).

To Do: support MQTT access via WiFi.

## MySense test
MySense is supplying some simple test scripts to test LoRa, GPS, meteo, and dust sensors. Use xyz_test.py for this. E.g.:
'''
>>> import dust_test
'''
This enables you to test all modules and wiring one by one.

### Data format handling at TTN webiste server
Use the script `lora_test.py` to test your configuration and LoRa connectivity.
```python
    >>>import lora_test # this will send MySense info and MySense data
```
### Reading at TTN the data
Enter Java Script code to decode the payload format at TTN website via the console:
```java script
function Decoder(bytes, port) {
  // Decode an uplink message from a buffer
  // (array) of bytes to an object of fields.
  var decoded = {};

  // if (port === 3) meta data
  // if ( port === 2 ) or (port === 4) for sensor data to json format
  ...
}
```
Try this with a payload as showed on the tab 'data'.

The payload can be decoded with the JavaScript as in the file `TTN-decode.js`. Try this with some test payloads before you make fully operational.

### how to collect the data from TTN MQTT server
Here is an example how your sensor kit will show at the TTN MQTT server via the command:
```bash
mosquitto_sub -v -h eu.thethings.network -p 1883 -u "$APPID" -P "$ACCES_KEY"  -t '+/devices/+/up'
```

The json string from the server, something like:
```json
2021802118025917/devices/lopyprototype/up {
    "app_id":"20215z","dev_id":"lopyprototype","hardware_serial":"D495613",
    "port":2,"counter":25,
    "payload_raw":"AfsBBAP/ADkANA==",
    "payload_fields":{ 'temperature': -12.3, 'humidity': 80, ...
        "utime": 12345678
    },
    "metadata":{
        "time":"2018-02-23T19:49:29.919556985Z","frequency":868.5,
        "modulation":"LORA","data_rate":"SF7BW125","airtime":61696000,
        "coding_rate":"4/5","gateways":[
            {"gtw_id":"eui-b827befff65b8e9","timestamp":1663804715,
            "time":"2018-02-23T19:49:29.891823Z",
            "channel":2,"rssi":-37,"snr":7.8,"rf_chain":1,
            "latitude":15.40283,"longitude":2.15341,"altitude":230}
    ]}}
```

Use the Java Script `payloadformat.js` to decode the payloads.
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

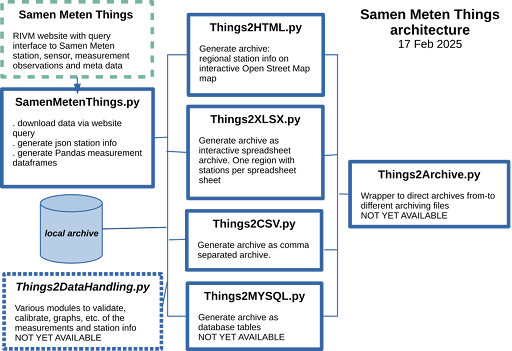
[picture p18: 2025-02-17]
SamenMetenTools/images/SamenMetenArchitecture.png

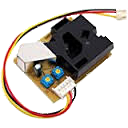
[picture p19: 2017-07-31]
docs/images/PPD42NS.png

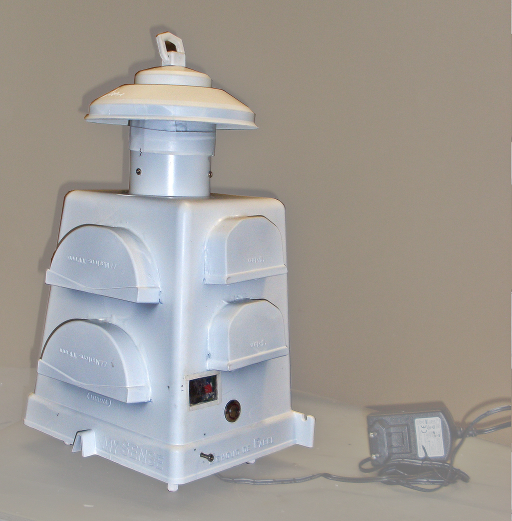
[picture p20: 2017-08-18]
RPi/images/MySense-2-kast.png

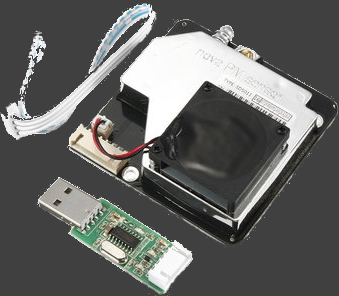
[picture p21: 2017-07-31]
docs/images/SDS011.png

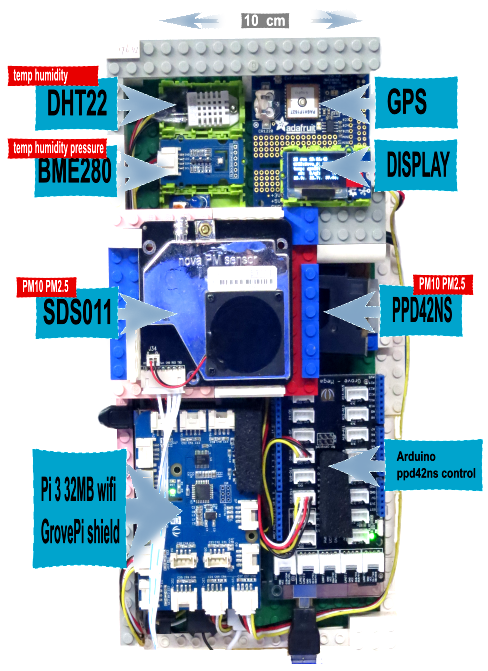
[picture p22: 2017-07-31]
RPi/images/sensorkit-176.42.png

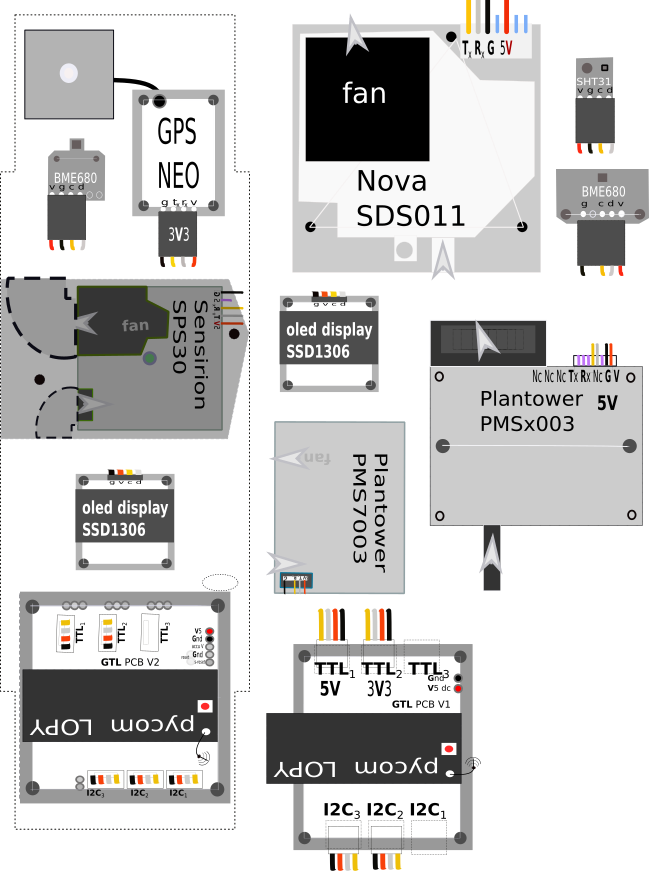
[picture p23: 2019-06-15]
PyCom/images/MySense-LoRa-layout-lantern.png

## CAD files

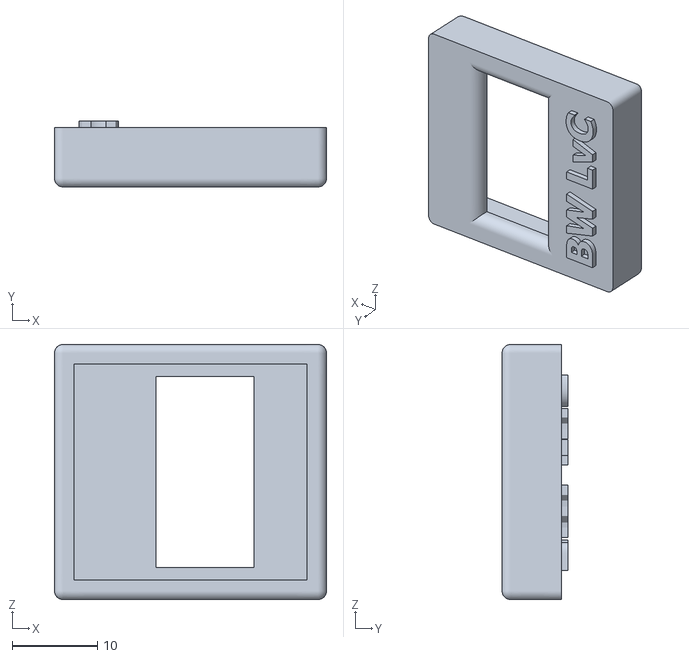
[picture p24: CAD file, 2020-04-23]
PyCom/images/Oled inw 2.stl
32.0 x 7.75 x 30.0

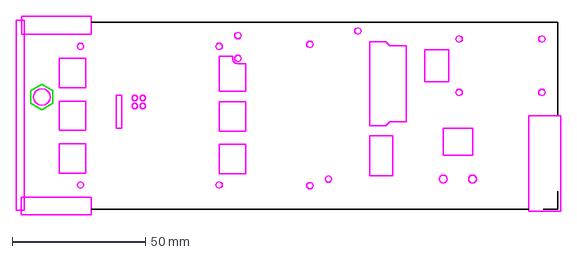
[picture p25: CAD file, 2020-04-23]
PyCom/images/moederframe2.2.dxf
204.0 x 74.3 mm

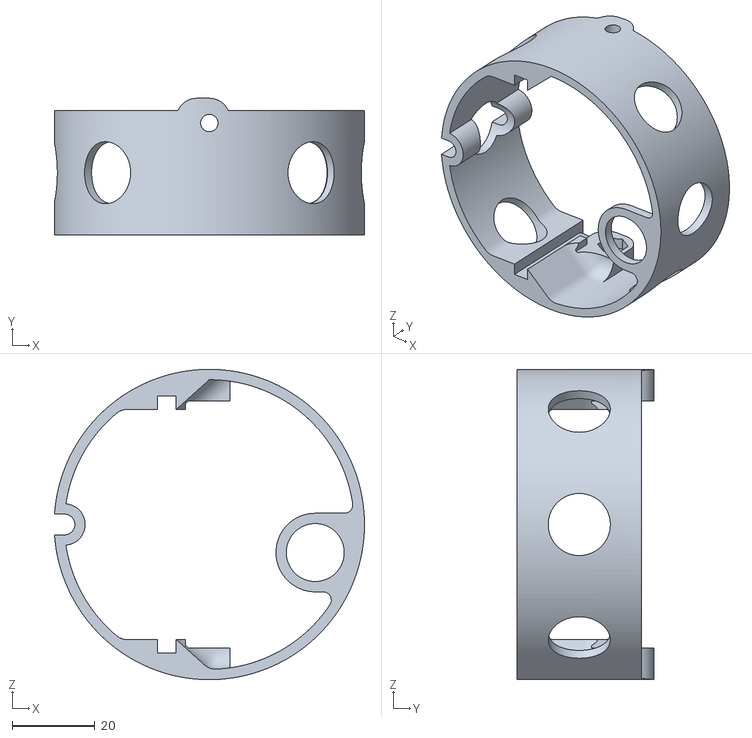
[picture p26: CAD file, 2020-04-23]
PyCom/images/houder mb j.stl
74.9 x 33.0 x 75.0

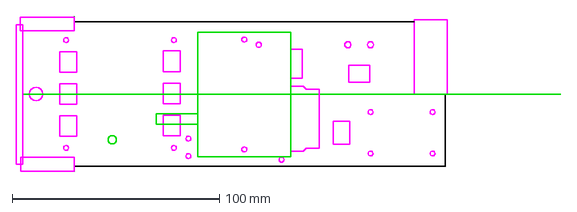
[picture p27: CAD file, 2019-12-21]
PyCom/images/moederframe 2.dxf
262.7 x 75.0 mm

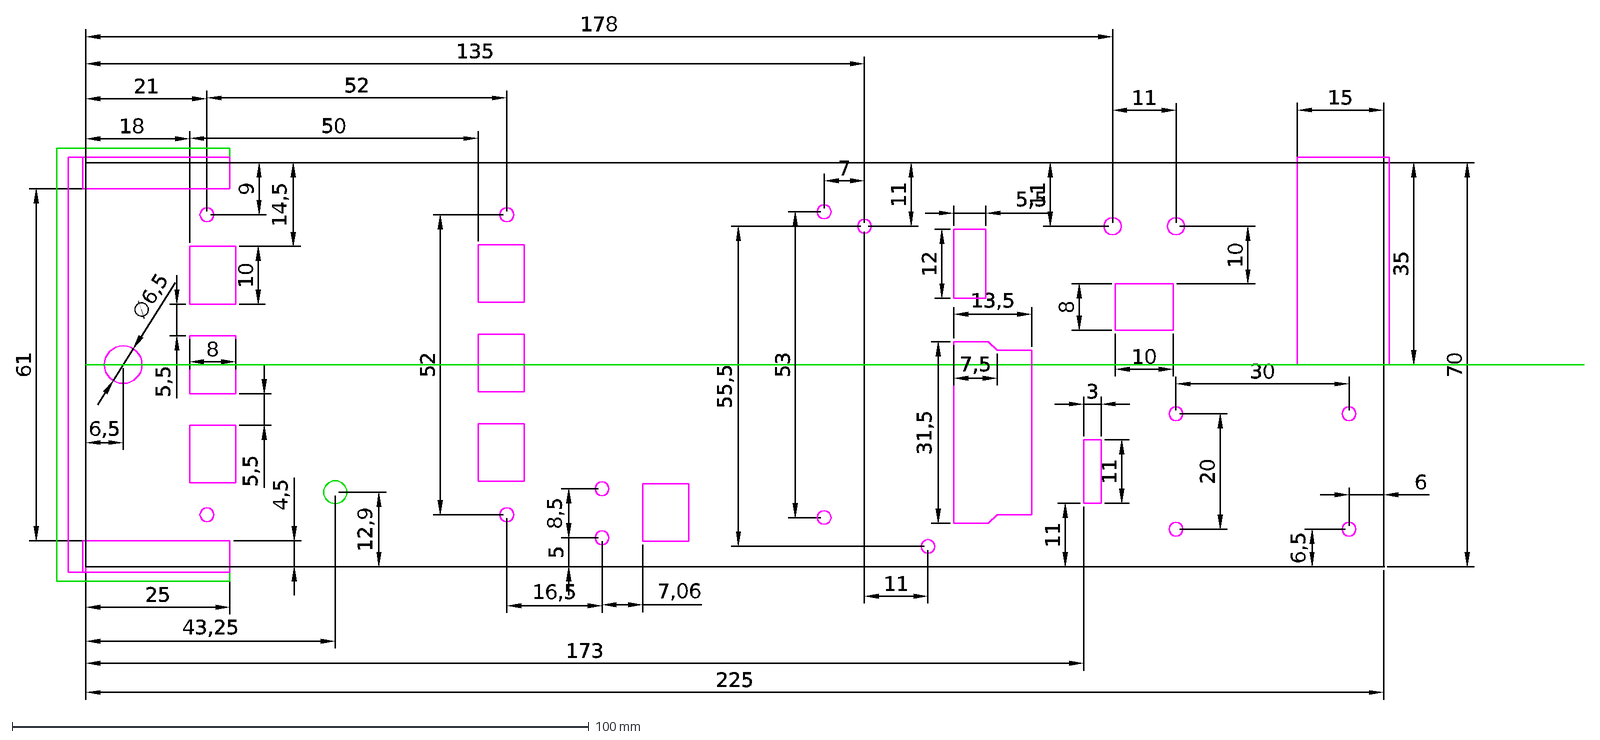
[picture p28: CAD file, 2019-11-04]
PyCom/images/motherboard-SPS-PMS-insideantenna.dxf
21
9
18
5
11
55,5
173
6
6,5
10
25
4,5
61
70
225
5,5
8
8,5
52
14,5
50
3
20
30
43,25
12,9
15
35
135
7,06
16,5
∅6,5
178
7
53
31,5
13,5
7,5
12

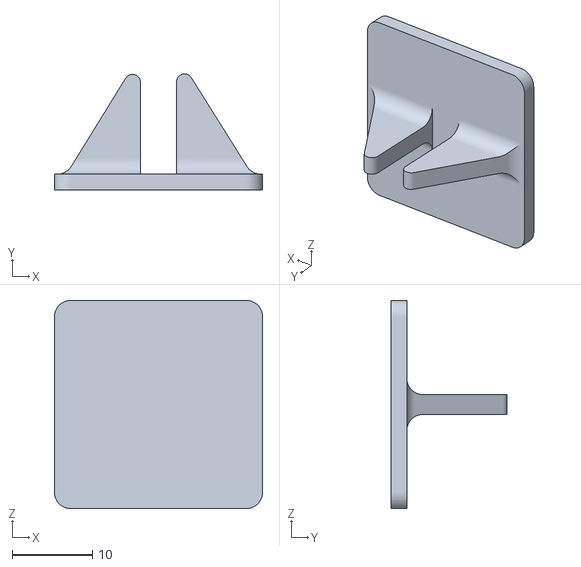
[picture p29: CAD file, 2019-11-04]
PyCom/images/GPS tafel a.stl
26.0 x 14.5 x 26.0

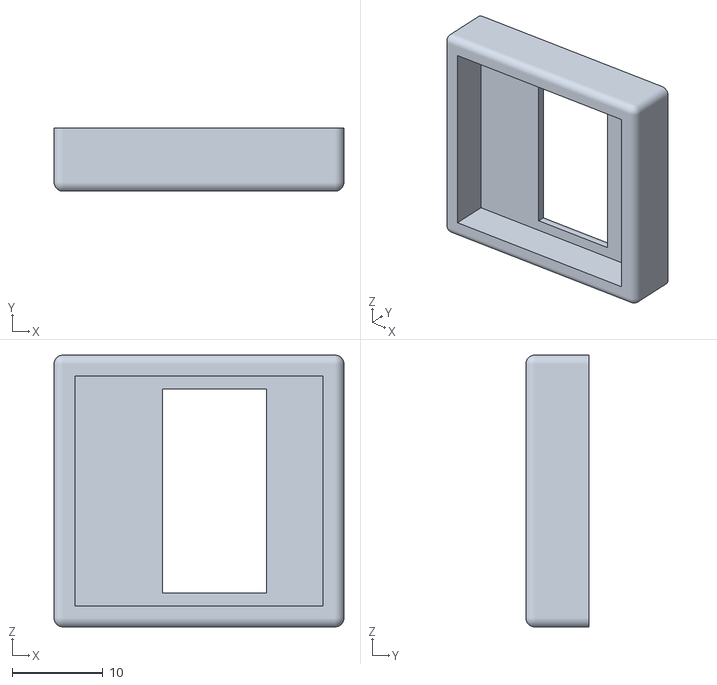
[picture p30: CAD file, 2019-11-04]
PyCom/images/Oled inw b.stl
32.0 x 7.00 x 30.0

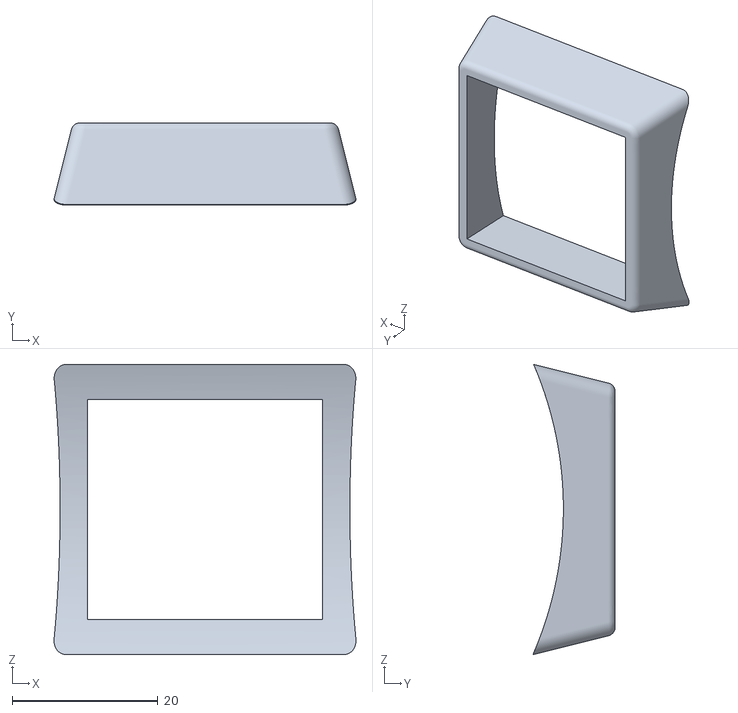
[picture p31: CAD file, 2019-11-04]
PyCom/images/Oled uitw c.stl
41.4 x 11.3 x 39.8

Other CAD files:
PyCom/images/houder mb i.stl

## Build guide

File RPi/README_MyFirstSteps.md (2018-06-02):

# My First Steps
## power on/off MySense
### Power on
Powering on the Pi with installed MySense is done by connecting the power adapter (5V 2.5A) to the Pi.
The Pi will use some time to boot, look for wired LAN connection, followed by search to wifi internet connectivity. The power led button will flash if no internet connectivity is found and go into wifi Access Point mode.
Wifi Access WPS modus can be enforced by pressing the power button for 7 seconds.

On internet access the Pi display will show the used IP address and proceed to startup MySense fully. After some minutes the display will show the measurents.
If no output channels are enabled or fail MySense will stop.

Login from remote `ssh ios@mysense.ip.number` (default password: BehoudDeParel), so one can view the MySense log file for enabled input and outputerrors: `cat /var/log/MySense/MySense.conf`.
All python scripts are in the folder `MySense`.

### enable wifi access
The power button led will flash if no internet access is found: there is no wired LAN connectivity, nor wifi internet access.
The Pi is in wifi Access Point modus:
* enable wifi access on e.g. laptop to `MySense-IoSn` with password `BehoudDeParel` (see also tyhe display for these credentials.
* login into MySense Pi `ssh ios@192.168.2.1`
* add/change the list of networks in `/etc/wpa_supplicant/wpa_supplicant.conf` via `sudo vi ....`:
```
    # add or change this entry
    network={
        ssid="your-SSID"            # <---- change this
        psk="Your Pass for SSID"    # <---- change this
        proto=RSN
        key_mgmt=WPA-PSK
        pairwise=CCMP
        auth_alg=OPEN
}
```
* the command `sudo ifup wlan0` will try to access internet again and show success or failure.
* `sudo reboot`

TO DO: use wicd to do this in a more user friendly way

### Power off the Pi
The Pi can be powered off by disconnecting the power cord. However there is a small chance that the file system will be damaged.

A more reliable way is: push the button for more as *14 seconds* to force a `reboot` or for more as *20 seconds* to force a `poweroff`.

### MySense configuration
In the user *ios* home directory the folder `MySense` will have all MySense scripts and the MySense `MySense.conf` configuration file.
If needed enable/disable of change sensor options in this file.

The call `python MySense.py stop` will stop MySense. Start MySense with `python MySense.py start` to restart the MySense daemon. The command `python MySense.py` will start MySense in console mode, showing all startup messages on the console. Use `--help` to get an overview of all command line options.

## installation on Pi (Pi3 or Pi W)
### Intro
For the first steps with MySense we make use of a Pi (hopefully a Pi3 B+) with eg Jessie or better Stretch installed as Linux OS. See the various Pi install instruction for a How To install Debian Stretch on the Pi. Use a Pi say with a micro SD card of about 32GB. Hook the Pi up with internet and login as pi user.

At first one is advised to use the Python debugger and step throught the MySense main module. The main MySense routine is `sensorread`. So set the break to this routine.
If anythings break the debugger will give you much inside what is going wrong.
### Step 1
Installation of MySense as simple as possible with one input sensor (we use the build in wifi rssi as sensor in the case) and one output channel: console.

1. update the Linux OS:
```shell
sudo apt-get update
sudo apt-get upgrade
sudo install python git pip
```
2. install Internet of Sense user "ios":
```shell
sudo useradd ios
sudo passwd ios # and remember the password entered
```
3. login as user ios:
```shell
ssh ios@localhost
```
4. get the MySense software:
```shell
git clone https://github.com/teusH/Mysense
cd MySense
# and see the MySense command line options
python MySense.py --help
```
### Step 2 your first real simple sensor
(Remote) login as the ios user and go to the MySense working directory `cd MySense`.
1. Configure the MySense configuration file with as input plugin the Pi build-in wifi signal strength "sensor":
```
cp MySense.conf.example MySense.conf # copy
ed MySense.conf # edit with your favorite editor
```
Edit the MySense.conf file and decomment the part of `[rssi]`
2. And run MySense:
```shell
python MySense.py -i rssi -o console -l debug
```
That's it!

If you are not so confident with the first step use the Python debugger `pdb` as:
```shell
pdb MySense.py -i rssi -o console -l debug
```
And set the break to the main routine as follows: `b sensorread` and step via the debug command `n` (next) till the input plugin entry as `getdata`. Step in via `s` debug command into the routine if you want to or net to `Out` the output channel part.

If the rssi wifi signal strength is available from the Pi you will see every minute the signal strength on the Pi console.
### Step 3 attach a real sensor e.g. temperature
Do the steps after Step 2 one by one: sensor plugin or output channel.
Use e.g. a meteo sensor from Adafruit e.g. DHT22 or BME280 (better one). See the dht.md or bme280.md documentation file for a detailed how to.

What you need to do is install the hardware (for simplicity use Grove shield and Grove modules so you does not need to use soldier). Attach the hardware on the Digital data sockets and use the numbers as proposed in the MySense configuration file.

Decomment the `[dht]` or `[bme280]` section in the configuration file.

Install the Adafruit libraries on the Pi. Or use the `MyINSTALL.sh DHT` to do it for you.

And try it:
```shell
pdb MySense.py -i dht -o console -l debug
b sensorread
n ...
```
At first things go wrong. The input channel uses multi threading: the input plugin will run in the background and delivers every sample unit of N seconds (default a minute) the collected measurement to the MySense part. A command interrupt (<cntrl>C) will stop MySense but NOT the input sensor thread. Stop the process as follows: hit the key <cntrl>z (pauze command) and use `kill %1` to kill the process.

### Step 4 attach an output channel
Attach e.g. a database output channel. See the documentation for mysql.md for the steps: installation of mysql client Python library. Configration of user access credentials to the database and configuration of the database. MySense will add the tables and sensor columns automatically if the user credentials are allowed to do so.

Enable the `[mysql]` section in the MySense configuration file and define the MySQL user access credentails there.

And try it:
```shell
python MySense.py -i dht -o console,db
# or python MySense.py start
```
### Next steps
What you need to understand:
1. input sensor plugins run in the background as threads
2. input and output channels and needed libraries for the modules are only used if the corresponding section is defined in the MySense configuration file.
3. input and output channels can be switched on and off in the configuration file. The modules will if switched off be unloaded by MySense. 
4. input and output channels switched on from the command line will overwrite the input/output switch from the configuration file.
5. If an input broker plugin is switched on MySense will act as proxy. So MySense can be used to chain MySense instances from sensor input reader to another MySense which pushed the data to other output channels as databases, spreadsheets, etc.

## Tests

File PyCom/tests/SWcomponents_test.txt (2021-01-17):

# Copyright 2019, Teus Hagen, license GPLV3
#
# test kit with copy(<cntrl>shiftC)/paste(<cntrl>v) via REPL
# test suite helps to detect hw configuration and software problems
# one by one
# xyz_test is operational test for xyz
# other parts are functional tests for MySense.py wrapper

# RESET LoPy FLASH MEMORY
# MySense will archive the detected configuration:
# which device is connected to which bus (TTL or I2C) and to which TTL socket
# which library should be loaded to drive the device.
# Make sure to choice the right 3V3 or V5 on the connector board for TTL socket.
# Detected configuration is kept in flash memory and
# loaded on warm reboot (deepsleep wakeup)
# Certain values e.g. lora keys and lora package counter is kept in nvs_ram.
# These archived data is cleared/reset as follows:
import MySense
MySense.MyReset()
# delete detected configuration surfiving reboots
import os
os.remove('/flash/MySenseConfig.json')
# os.uname()  # show version PyCom controller
# os.mkfs('/flash')   # remove all MySense firmware
# 
# delete frequently changed status variables
from pycom import nvs_erase_all
nvs_erase_all()
# for item in ['gps','mode','LAT','LON','ALT','info_next','gps_next']: nvs_erase(item)
# delete LoRa saved status data
from network import LoRa
lora = LoRa(mode=LoRa.LORAWAN, region=LoRa.EU868)
lora.nvram_erase()
# END of erase all MySense from LoPy

# use next console (USB with expansion board) on PyCom firmware update
# on clean flash memory:
# From firmware 1.20 (Jan 2020) PyCom introduced pybytes
# and with that smart config. How to remain old boot style compatible
# without using smart config:
import pycom
if not pycom.wifi_on_boot(): pycom.wifi_on_boot(True)
ssid = 'lopy4-wlan'; pwd = 'www.pycom.io'
#  if not pycom.wifi_ssid_ap():
pycom.wifi_ssid_ap(ssid)
pycom.wifi_pwd_ap(pwd)
if pycom.pybytes_on_boot(): pycom.pybytes_on_boot(False)
# if pycom.smart_config_on_boot(): pycom.smart_config_on_boot(False)
# and reboot/reset or
# and make sure old style wifi is immediately active
from network import WLAN
WLAN().deinit()
from machine import unique_id
import binascii
ssid += '-' + binascii.hexlify(unique_id()).decode('utf-8')[-4:].lower()
WLAN().init(mode=WLAN.AP, ssid=ssid, auth=(WLAN.WPA2,pwd), channel=7, antenna=WLAN.INT_ANT)

##### flashed configuration data
# HW configuration is maintained in config (may come from archive json file in flash mem
# config dict: { (name,abus): value}, value is anything (reminder: json converts tuple to array)
# name: eg dirty, accu(pin), sleep(pin)
# reminder: accu disconnected and sleep is strapped: will auto remove archive in flash
# abus (i2c,ttl): {(meteo,display,dust,gps,udated,calibrate): None or { (name,use,pins,baud,address): value}}

# accu voltage mesurement. May change 0.5V in time
accuPin = 'P17'
# try: from Config import accuPin
# except: pass
from machine import ADC
(ADC(0).channel(pin=accuPin, attn=ADC.ATTN_11DB).value())*0.004271845

# devices status is maintained in devs dict bus (i2c,ttl): dicts types (meteo,display,dust,gps)
# The devs dict is not archived in flash mem.
# devs dict: bus: i2c or ttl
# each bus has a type a dict:
#   lib (lib class module),
#   index (nr file desc),
#   conf (link to sensormeteo etc config dict),
#   i2c (file descr),
#   ttl (file descr),
#   enabled (can be used, has file descr.)

##### Some SOFTWARE TESTs
# using next tests will give you some first inside in the MySense software
# get serial number of the PyCom controller
from machine import unique_id
import binascii
binascii.hexlify(unique_id()).decode('utf-8')

# test script may write config items in archived config if hardware is found
# to delete archive config from flash mem: use
import ConfigJson
MyConfig = ConfigJson.MyConfig(debug=True) # get ref to archived configuration name space
MyConfig.getConfig()                       # get flashed configuration
MyConfig.config                            # show current archived configuration
# MyConf.clear                             # clear configuration in flash

# check which configuration and attached devices
debug=True
import MySense
MySense.getMyConfig(debug=debug)
# MyConfiguration = MySense.MyConfiguration
# MyConfiguration
# MyDevices = MySense.MyDevices
# MyDevices

# complete MyDevices dictionaries
# initDevices will do: initDisplay(), initDust(), initMeteo(), initNetwork(), DoGPS()
debug=True
import time
MySense.initDevices(debug=debug) # will initialize I2C and TTL devices (GPS on cold start)

# try to get some measurements
debug=True
MySense.DoGPS(debug=debug)
dData = MySense.DoDust(debug=debug)  # dust measurement
dData
mData = MySense.DoMeteo(debug=debug) # meteo measurement
mData
aData = MySense.DoAccu(debug=debug)  # state accu
aData                                # probably 0
aData = 12.5                         # set accu voltage

######## DEVICE TESTs
# next will give youy some test script to test connected hardware components
# try LoRa send info
MySense.SendInfo()                           # send meta data
# send data packet
debug = True
pData = MySense.DoPack(dData,mData,MySense.LocUpdate(),aData=aData, debug=debug)
Network = MySense.MyTypes['network']
Network['lib'].send(pData,port=4)

########## check I2C part
# basic functional test for hardware
import oled_test
import meteo_test

# I2C devices
# detect which devices Display
import whichI2C
I2Cobj = whichI2C.identifyI2C(identify=True,debug=True)

# check basic display init and functional tests
# Display = { 'use': None, 'enabled': False, 'fd': None}
I2Cobj.DISPLAY  # is display connected?
Display = I2Cobj.i2cDisplay
Display
print('Oled %s:' % Display['name'] + ' SDA~>%s, SCL~>%s, Pwr~>%s' % Display['pins'][:3], ' is %d' % I2Cobj.PwrI2C(Display['pins']))

import SSD1306 as DISPLAY # try display
Display['lib'] = DISPLAY.SSD1306_I2C(128,64,Display['i2c'], addr=Display['address'])
Display['lib'].fill(1); Display['lib'].show()
from time import sleep
sleep(1)
Display['lib'].fill(0); Display['lib'].show()
import sys
sys.exit() # reset

# I2C devices Meteo
import whichI2C
I2Cobj = whichI2C.identifyI2C(identify=True,debug=True)

# check basic meteo init and operational functions
# Meteo   = { 'use': None, 'enabled': False, 'fd': None}
I2Cobj.METEO
Meteo = I2Cobj.i2cMeteo
Meteo
print('Meteo %s:' % Meteo['name'] + ' SDA~>%s, SCL~>%s, Pwr~>%s' % Meteo['pins'][:3], ' is %d' % I2Cobj.PwrI2C(Meteo['pins']))

import BME_I2C as BME # try to get meteo data
Meteo['fd'] = BME.BME_I2C(Meteo['i2c'], address=Meteo['address'], debug=True, calibrate={})
# expect bus errors
Meteo['fd'].AQI
Meteo['fd'].temperature
import sys
sys.exit() # reset

########### check and test UART part
import dust_test
import gps_test

# UART devices which device is where connected
import whichUART
UARTobj = whichUART.identifyUART(identify=True,debug=True)
uarts = [None,'gps','dust']

# check dust device functions for MySense
# Dust = { 'use': None, 'enabled': False, 'fd': None}
Dust = UARTobj.devs['dust']
Dust
print('%s UART:' % Dust['name'] + ' SDA~>%s, SCL~>%s, Pwr~>%s' % Dust['pins'][:3], ' is ', UARTobj.PwrTTL(Dust['pins']))

from PMSx003 import PMSx003 as senseDust # get some data from device
sample_time = 60    # 60 seconds sampling for dust
# Dust['uart'] = UARTobj.openUART('dust') this does not work yet?
Dust['uart'] = uarts.index('dust')
Dust['fd'] = senseDust(port=Dust['uart'], debug=True, sample=sample_time, interval=0, pins=Dust['pins'][:2], calibrate={}, explicit=False)
UARTobj.PwrTTL(Dust['pins'],on=True) # power on
Dust['fd'].Normal() # fan on
Dust['fd'].Standby() # fan off
Dust['fd'].getData(debug=True)
UARTobj.PwrTTL(Dust['pins'],on=False)
import sys
sys.exit() # reset

# test with MySense, may see I2C errors
# depends on initDisplay(debug=True), will init display as well
import MySense  # has all functions
MySense.initDust(debug=True)
# ignore I2C bus errors
MySense.DoDust(debug=True)

# UART devices
import whichUART
UARTobj = whichUART.identifyUART(identify=True,debug=True) # all uart devices
uarts = [None,'gps','dust']

# check GPS functions for MySense
# Gps     = { 'use': None, 'enabled': False, 'fd': None}
Gps = UARTobj.devs['gps']
Gps
import GPS_dexter as GPS
print('%s UART:' % Gps['name'] + ' SDA~>%s, SCL~>%s, Pwr~>%s' % Gps['pins'][:3], ' is ', UARTobj.PwrTTL(Gps['pins']))
Gps['uart'] = uarts.index('gps')
Gps['fd'] = GPS.GROVEGPS(port=Gps['uart'],baud=9600,debug=True,pins=Gps['pins'][:2])
UARTobj.PwrTTL(Gps['pins'],on=True)
Gps['fd'].read() # get some valid records
Gps['fd'].date
Gps['fd'].timestamp
Gps['fd'].UpdateRTC()
round(float(Gps['fd'].longitude),5)
round(float(Gps['fd'].latitude),5)
round(float(Gps['fd'].altitude),1)
UARTobj.PwrTTL(Gps['pins'],on=False)

import sys
sys.exit() # reset

# test with MySense
# depends on initDisplay(debug=True)
import MySense
MySense.initGPS(debug=True)

######## LoRa tests
# Network = { 'use': None, 'enabled': False, 'fd': None}
import lora_test
import MySense
MySense.initNetwork(debug=True)
# depends on initNetwork(), initGps() and 'name' in Meteo and Dust dict
# Meteo = {'name':'','enabled': True} Dust = {'name':'None','enabled': True}
# Gps = {'enabled': True}
MySense.SendInfo(3) # send fake info

# to do
Accu    = { 'use': None, 'enabled': False, 'fd': None}

####### power management tests
import MySense
MySense.interval   # show intervals of sendinfo, GPS check, dust, dust sample
MySense.Power      # show powermanagement items
# MySense.Power['display'] = True # use power to display to switch on/off
# MySense.Power['ttl'] = True     # switch power to ttl on before / off after use
# MySense.Power['i2c'] = True     # switch power of I2C bus on/off during sleep
# MySense.Power['sleep'] = True   # switch deepsleep on/off
# TO DO
# deepsleep and config save

# test script may write config items in archived config if hardware is found
# to delete archive config from flash mem: use
import ConfigJson
MyConf = ConfigJson.MyConfig
MyConf.remove

# once tests are working one does not need them in flash anymore
# or use them via atom and 'run'
# test files may also reside in the '/flash/tests/' folder
import os
# for F in ['meteo','dust','oled','lora','lopy','gps',I2C','TTL']:
#   try: os.remove('/flash/tests/' + F + '_test.py')
#   except: pass
os.remove('/flash/meteo_test.py')
os.remove('/flash/dust_test.py')
os.remove('/flash/oled_test.py')
os.remove('/flash/lora_test.py')
os.remove('/flash/lopy_test.py')
os.remove('/flash/gps_test.py')
os.remove('/flash/I2C_test.py')
os.remove('/flash/TTL_test.py')

# clean up LoPy chip
# clear nvs_memory
from machine import nvs_clear
for var in ['modus','LAT','LON','ALT','gps_next','info_next']:
  try: nvs_clear(var)
  except: pass
# clear lora keys
import lora
lora = LORA()
lora.clear

# remove everything from flash mem:
import os
os.fsformat('/flash')
# depreciated os.mkfs('/flash')

# activate MySense:
# main.py:
import MySense
MySense.runMe()
# suggest to change wifi ssid and password of the wifi AP

# events from eg WatchDogTimer (similar to <cntrl>c key hit).
# post mortum debugging variables, may fail if not (yet) set:
from pycom import nvs_get
nvs_get('AlarmWDT')	 # point of last mark in loop, eg on WDT event
nvs_get('AlarmSlp')      # last deepsleep in secs, dlft None
nvs_get('myReset')       # secs of runMe loop or mark point in runMe() loop
nvs_get('Vmax')/10.0	 # maximum accu voltage, dflt None
nvs_get('Vmin')/10.0	 # minimum accu voltage, dflt None
nvs_get('Accu')/10.0     # event accu voltage low (10.8V), dflt None
nvs_get('count')	 # number of measurements
nvs_get('modus')         # Conf reset modus: 1 only devices, None/0 all on cold boot
nvs_get('gps')	         # nr of satellites seen, -1 not set
nvs_get('info_next')	 # next time in sec for meta data to be sent, dflt once a day
nvs_get('gps_next')	 # next time in sec to check gps location, dflt once 4 hr
nvs_get('LON')/1000000.0 # GPS longitude
nvs_get('LAT')/1000000.0 # GPS latitude
nvs_get('ALT')/10.0	 # GPS altitude in meters

# simple check of I2C-bus devices: oled display, and meteo sensors
# power on I2C bus turned on on PCB board
pwr = 'P21' # PCB V2.x power pin It does not hurt to try this
from machine import Pin
Pin(pwr, mode=Pin.OUT, pull=None, alt=-1).value(1)
# obtain I2C
pins = ('P23','P22')     # (SDA pin, SCL pin)
from machine import I2C
i2c = I2C(0, I2C.MASTER, pins=pins)
# I2C devices:
for one in list(i2c.scan()): print("0x%x" % one)

# import _thread
# probe = _thread.allocate_lock()

# oled display device
import SSD1306 as OLED
addr = 0x3c # check with i2c.scan()
device = OLED.MyI2C(128,64,i2c,address=addr, probe=None, debug=False)
device.fill(1) ; device.show()  # full turned on
device.fill(0) ; device.show()  # turned off

# meteo devices:
# SHT: addr in [0x44,0x45]
addr = 0x44 # or 0x45           # check with i2c.scan()
import SHT31 as MET
# BME: addr in addr in [0x77,0x76]
import BME680 as MET
addr = 0x77 # or 0x76           # check with i2c.scan()
import BME280 as MET
addr = 0x76 # or 0x77           # check with i2c.scan()
# init object and probe the address
device = MET.MyI2C(i2c, address=addr, probe=True, lock=None, debug=False, calibrate=None)
device.temperature
device.humidity
device.pressure # SHT -> None
# device.gas
# device.gasBase(debug=True)  # get gas base
# device.AQI

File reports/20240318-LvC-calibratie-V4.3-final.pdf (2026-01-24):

Datum: 25 maart 2024
Stichting BWLvC: informatie@bwlvc.eu

Kalibratie van low-cost sensoren voor lokale Luchtkwaliteitsmetingen in de regio St. Anthonis
Achtergrondsinformatie
De EU-normen en WHO advies niveaus voor de gezondheidsrisico berekeningen gaan uit van blootstelling (concentratie berekening over een langere periode van bijv. een dag of een jaar). Het Schone Lucht Akkoord verwacht (lokale) maatregelen die leiden tot een lagere lokale blootstelling aan emissies, o.a. (ultra) fijn stof, roet (soot), ammoniak, stikstofoxiden, geur, geluid, etc. Om tot inzicht te komen van de blootstelling zijn er lokale concentratie metingen noodzakelijk. Door het uitblijven van vragen en interacties met de lokale beleidsmakers blijft de duiding van de meetresultaten en visualisatie na 4 jaar meten teveel technisch giswerk: wat wil je weten met dit meten?
De aanleiding van dit document
Naar aanleiding van een vraag over de kalibratie van metingen door leden van Team Lokaal, gemeente Land van Cuijk, probeert de Stichting met dit document hierop enkele antwoorden te geven en deelt haar ervaringen met de lokale metingen. De Stichting hoopt dat de meetresultaten en analyses van de data beter te begrijpen zijn.
Samenvatting
Low-cost sensoren worden in meer of mindere mate beïnvloed door lokale relatieve vochtigheid, temperatuur, door (lokale) wind en regen, maar ook door de werking en onderhoud van de filterinstallaties.
De hamvraag bij de beoordeling van de lokale metingen is: wat voeg je lokaal aan de emissies toe t.o.v. het niveau van buiten de betreffende regio?
Referentie metingen bijv. station Vredepeel zijn altijd noodzakelijk en helpen bij de data analyse.
Bij de data analyse en visualisatie van de lokale luchtkwaliteitsmetingen – metingen met low-cost sensoren – is een validatie en calibratie van de metingen noodzakelijk. De Stichting gebruikt bij de waardering van met name fijn stof metingen regressie berekeningen die gerelateerd zijn aan één type sensor (Sensirion SPS30) en de sensor (MetOne BAM1020) van een nabij gelegen landelijk meetstation in Vredepeel. Deze calibratie algoritmen (zie calibratie tabel) zijn vastgesteld in 2020 over een periode van een half jaar met sensoren op de locatie in Vredepeel. Weersinvloeden zoals wind en regen worden (nog) niet berokken in deze berekeningen. De correctieve berekeningen worden alleen toegepast bij de data analyses zoals bijv. voor de real-time fijn stof grafieken gepubliceerd voor en door de Stichting. Pas op: de low-cost real-time metingen, algoritmen, validatie en de calibratie correcties zijn lokaal afhankelijk. Deze analyses zijn indicatief.
De Stichting geeft de metingen real-time in onbewerkte vorm zo volledig mogelijk door aan derden zoals bijv. Sensors.Community en het RIVM dataportaal. Op het gedeelte van de doorgegeven metingen dat de dataportalen opslaan en/of gebruiken heeft de Stichting geen invloed. De Stichting laat de validatie en kalibratie berekeningen dan ook geheel over aan deze dataportalen.
Kalibratie van lokale Luchtkwaliteitsmetingen in de regio St. Anthonis | V4.3 | 1

De Stichting beperkt zich alleen tot real-time low-cost fijn stof concentratie metingen met name ligt de focus op PM2.5. Dit om redenen dat real-time ammoniak, ozon, stikstofoxiden, geur, etc. sensoren voor de Stichting te kostbaar zijn.
De validatie en kalibratie berekeningen hebben een kwalitatieve invloed op de real-time visualisatie (grafieken) en publicaties. Het aantal lokale meetpunten in een regio zijn maar gering. Dit is van invloed op de data analyses en op de onzekerheidsfactor in de luchtkwaliteitsconclusies voor een lokaal gebied. Enkele punten van aandacht
Real-time emissie concentratie metingen zijn noodzakelijk om lokaal inzicht te geven in de blootstelling aan ongezonde stoffen. En belangrijker ze monitoren de effectiviteit van de lokale (beleids-)maatregelen. Het doel van gezondheidsrisico duiding (blootstelling) op straatniveau kan niet zonder zonder deze lokale concentratiemetingen.

Waarom en waarvoor meten we eigenlijk? Zonder duidelijkheid over de mogelijke maatregelen en ondernomen acties en mogelijke maatregelen heeft het lokaal meten geen zin. Er is een gemis aan duidelijkheid over het doel van de metingen. Alleen acties ondernemen t.a.v. fijn stof metingen door burgers, bewustwording van emissies op gezondheid, en subsidie verlening bij schoorsteen ontmanteling is ons inziens wat te kort door de bocht.
Publicatie van metingen via de website van Behoud de Parel loopt ten einde.
Voor en na de rapportages van 2022 (3 jaar meten in St. Anthonis, wat nu?) en 2023 (notitie Werkkaders meetprojecten) van de Stichting en ver. Behoud de Parel is er vrijwel geen gebruik gemaakt van de validatie, kalibratie en visualisatie van de metingen van de Stichting op de website van Behoud de Parel. Behoud de Parel stopt in de zomer van 2024 daarom met deze serviceverlening aan de Stichting. Dit houdt in dat de resultaten van de validatie en kalibratie daarna niet meer door de website van Behoud de Parel inzichtelijk gemaakt worden.
Operationele checks, data acquisitie en doorgifte van (ruwe) metingen van de Stichting naar derden, zoals bijv. de dataportalen van Sensors.Community, RIVM Samen Meten Dataportaal, AQICN.org, AirTube.info, etc. zal wel na de zomer gecontinueerd worden. Deze dataportalen verrichten hun data analyses en visualisatie elk op hun eigen wijze.

Kwaliteit van (alle) fijn stof metingen
Voor referentie metingen van de sensoren dient een meetkit met de toegepaste type sensor in de buurt geplaatst te zijn van bij voorkeur een referentie (landelijk) meetstation. Hierdoor wordt kalibratie van de lokale metingen in de betreffende regio mogelijk gemaakt. Tevens ontstaat op deze manier inzicht over het verschil van fijn stof niveaus en lokale invloeden (temperatuur en luchtvochtigheid). Vrijwel overal gebruikt men bij de z.g. low-cost fijn stof sensors alleen het deel met de gewichtswaarden – de Nova sensor is van een ouder type en geeft alleen maar de metingen als gewicht weer. De gewichtswaarden van de low-cost sensoren worden aan de hand van de deeltjes tellingen m.b.v. laboratorium proeven berekend door de fabrikant van de sensor. De lokale invloeden van bijv. luchtvochtigheid en temperatuur worden op deze manier dan ook niet meegenomen in de weergegeven gewichtswaarden. Voor low-cost fijn stof
Kalibratie van lokale Luchtkwaliteitsmetingen in de regio St. Anthonis | V4.3 | 2

sensoren die hoofdzakelijk toegepast worden voor binnenshuis i.t.t. toepassingen buitenshuis is de weergave van metingen als gewicht minder een probleem. Alle low-cost metingen zijn per definitie indicatief. Alleen door de metingen over lange perioden te vergelijken wordt een redelijke indruk verkregen in hoeverre de lokale metingen met lokale referentie sensoren overeenkomen.
Kortom lokale validatie en kalibratie m.b.v. referentie metingen is een voorwaarde voor een goede weergave van de resultaten. Bepaling van de relatieve vochtigheid en buitentemperatuur op de locatie van de meetkit draagt bij tot verbetering³

van de kwaliteit van de meting en de data analyse. Waar staan de meetkits van de Stichting?
Van begin 2019 heeft de Stichting Burgerwetenschappers Land van Cuijk heeft ca. 20 meetkits voor het meten van fijn stof concentraties en temperatuur en relatieve vochtigheid in de regio St. Anthonis opgesteld staan. De meetkits zijn uitgerust met aanvankelijk een Plantower PMSx003 en vanaf 2020 uitgebreid ca. 12 meetkits met een Sensirion SPS30 fijn stof sensors.
Om referentie metingen mogelijk te maken staan een drietal
meetkits¹

met zowel de Plantower en Sensirion sensoren en tevens een meetkit met de door RIVM aanvankelijk veel toegepaste Nova SDS011 fijn stof sensor opgesteld boven op ca. 10 km afstand gelegen RIVM/LML landelijk meetstation te Vredepeel. Dit maakt een vergelijking van locatie verschillen en calibratie van de
metingen mogelijk.
Het meetstation van RIVM/LML meet fijn stof PM10 en PM2.5 m.b.v.

MetOne BAM1020. Deze verfijnde referentie apparatuur meet elk uur het gewicht van de opgezogen en gedroogde fijn stof via een inlaat van de buitenlucht. Ook deze referentie metingen worden bijgehouden.

Hoe goed zijn Low-Cost Sensoren (LCS)?
De low-cost sensoren die voor lokale metingen gebruikt worden zijn ontwikkeld voor binnenshuis toepassingen en zijn in wezen z.g. deeltjes tellers: ze tellen de fijn stof deeltjes per grootte orde²

. De tellingen worden door de fabrikant van de sensor vervolgens met een vast algoritme naar gewichtswaarden omgerekend. De hoge luchtvochtigheid (RH > 70%) in bijv. de nachtelijke uren is hoog en valt meestal buiten de low-cost fijn stof sensor specificaties. Er is in het door de fabrikant gebruikte algoritme geen rekening gehouden met fluctuaties van de temperatuur of relatieve vochtigheid. Het probleem is dan ook dat op deze manier meten je in wezen appels met peren aan het vergelijken bent.
M.a.w. de gevonden waarden zijn indicatief en er zijn verschillen met de referentie sensoren.
De weersinvloeden moet je voortdurend meenemen in je kalibratie-berekeningen. De kalibratieberekeningen³

zijn daarmee lokaal afhankelijk. Het samenstellen van de kalibratie voor deze low-cost metingen is hierdoor complex.

1 Overzicht van ongekalibreerde metingen door de MySense meetkits en BAM1020 referentie sensor op de lokatie station van LML te Vredepeel http://behouddeparel.nl/meetkits/87
2 Een technische uitleg over de werking van de sensoren: A Review of Low-Cost Particulate Matter Sensors from the Developers’ Perspectives, Alfado e.a., 2020, Sensors MDPI publicatie https://www.mdpi.com/1424-8220/20/23/6819
3 RIVM onderzoek over o.a. kalibratie problematiek low-cost fijn stof sensoren: https://www.mdpi.com/2073-4433/10/8/445 (Atmosphere publicatie, augustus 2018)
Kalibratie van lokale Luchtkwaliteitsmetingen in de regio St. Anthonis | V4.3 | 3

Door de beperking aan middelen worden lokale klimatologische invloeden zoals regen en wind niet gemeten. De meetkits van de Stichting meten wel de lokale temperatuur en luchtvochtigheid. Hoewel de invloed van RH op de lokale fijn stof metingen van grote invloed zijn, worden die invloeden (nu nog) niet meegenomen in de kalibratieberekeningen voor een bepaalde locatie. Voor zover bekend gebeurt dit (nog?) nergens.
Zoals hieronder uit de kalibratie/regressie tabel blijkt zijn met name de metingen van PM2.5 in Vredepeel redelijk vergelijkbaar met de lokale BAM1020 metingen. Voor PM10 is dat veel minder het geval. PM2.5 is t.a.v. fijn stof emissies is daarom de belangrijkste indicator. Het door de Stichting toegepaste kalibratie-algoritme – het algoritme berekent de gewichtswaarden naar het type Sensirion SPS30 – is alleen bepalend voor de regio Vredepeel en zal voor andere verder gelegen dan ca. 15 km regio’s anders berekend moeten worden.

De fijn stof en ammoniak metingen in St. Anthonis
Eind september 2022 verscheen de notitie ‘Drie jaar meten in agrarisch gebied – wat nu?’ (PDF document https://www.bwlvc.eu/wp-content/uploads/2020/03/3JaarMetenInAgrRegioWatNu.pdf). Hierin wordt een overzicht op straat niveau gepresenteerd van de gevalideerde en gekalibreerde real-time fijn stof, maandelijkse stikstof en ammoniak metingen gedurende de periode 2019-2022 in de regio St. Anthonis. De visualisatie van deze real-time gevalideerde en gekalibreerde real-time fijn stof, temperatuur en luchtvochtigheidsmetingen in
St. Anthonis en nabij het RIVM referentie meetstation in Vredepeel zijn in te zien bij op de website van ver. Behoud de Parel⁴

Het probleem van kleine aantallen sensoren
Alle lokale meetinitiatieven hebben maar enkele tientallen meetkits operationeel. Al deze projecten, ook de metingen door de Stichting, worden voor het grootste deel doorgegeven naar derden zoals RIVM dataportaal⁵

, Sensors.Community⁶

en
zelfs naar bijv. AQICN.org⁷

en AirTube.info⁸

. Van oorsprong worden de metingen meestal direct naar Sensors.Community (Luftdaten) gestuurd. De doorgifte beslaat helaas maar een selectie van alle beschikbare meetgegevens van de sensors. De metingen die doorgegeven worden zijn z.g. ruwe meetdata (zonder bewerkingen zoals validatie en kalibratie). Veel dataportalen, ook het RIVM, betrekken hun data van Sensors.Community.
Dit houdt in dat i.t.t. tot de duizenden meetkits die het RIVM tot zijn beschikking heeft voor het landelijk model (tot op gemeente niveau), er voor de statische berekening op straat niveau er maar een zeer beperkt aantal metingen ter beschikking zijn. De onzekerheidsfactor in deze lokale berekeningen is daarom hoger. Voor lokale toepassingen dienen de metingen nauwgezet (statistisch en operationeel) gecheckt worden: zowel op operationeel niveau, bij ontvangst van de data - de data validatie fase, en de kalibratie bij analyse en visualisatie.

4 Website pagina met overzicht van regio St. Anthonis, Land van Cuijk http://behouddeparel.nl/?q=Regionaal Overzicht 86. (http://behouddeparel.nl/?q=Regionaal%20Overzicht%2086)
5 Statistiek analyse gereedschap (Shiney gebaseerd op R en R-Studio) voor de metingen uit de database van het RVIM dataportaal. Zie: https://www.samenmeten.nl/dataportaal/samen-analyseren-tool
6 https://maps.sensor.community/#12/51.6731/5.8903
7 http s://aqicn.org/station/@78100/#/s:78100/n:mullemsedijk-sint-anthonis-the-netherlands 8 Een uitstekende website met fijn stof en andere meetgegevens: https://airtube.info/?pos=51.54825656210027,5.900344848632813,11 (https://airtube.info/?pos=51.54825656210027,5.900344848632813,11)
Kalibratie van lokale Luchtkwaliteitsmetingen in de regio St. Anthonis | V4.3 | 4

Het is gebleken dat de onderlinge verschillen in de productie batch niet significant zijn. M.a.w. de regressie test bij aanvang van de metingen om de verschillen tussen de sensoren van hetzelfde makelij te verkennen, wordt momenteel niet meer toegepast. De validatie- en plausibiliteitscheck vangt de fouten van de sensor in het veld enigszins op.
De Stichting voert voor de visualisatie van de meetdata in de grafieken een validatie en kalibratie filters toe. De gebruikte statistische filters en programmatuur is op de websites van de Stichting en Behoud de Parel (nu nog te vinden tot de zomer van 2024) en vrij te gebruiken onder Open Source (OSS) condities.
Operationele check van de meetdata
De meetdata wordt voor de visualisatie fase (grafieken) gecheckt of de meetkit nog op de locatie staat en waar hij thuishoort. De metingen worden nagekeken of de waarden niet te constant zijn bijv. door verzadiging van de rel. vocht sensor, door een verstopping van de fijn stof sensor in de luchtstroom – door een spinnetje, door een ventilator die stil staat of doordat de power voorziening te laag is, en/of doordat men vergat de stekker terug te zetten in het stopcontact. Soms is een bezoek aan de locatie dan noodzakelijk. Met een gering aantal meetkits zijn dit soort storingen problematisch voor een goede data analyse.
Validatie van meetdata
Zodra er een redelijke reeks van metingen bekend is wordt de data statistisch over een periode van enkele dagen gevalideerd. Er wordt dan gelet op: liggen de metingen wel binnen de specificaties van de betreffende sensor, nul metingen, metingen die te extreem zijn, zijn de fijn stof en RH waarden positief, is de waarde redelijk t.a.v. zijn voorganger of de volgende meting (spikes), etc.? Deze statistische validatie vindt plaats met behulp van standaard statistische checks zoals Chi-kwadraat en Grubbs. Onwaarschijnlijke waarden worden geïnvalideerd en verder niet betrokken in het volgende validatie check of visualisatie.
Kalibratie van meetdata
De drie meetkits van de Stichting en ver. Behoud de Parel zoals die bovenop het RIVM/LML meetstation in Vredepeel hangen, hangen daar als referentie met de lokale metingen elders in de regio St. Anthonis. Bijvoorbeeld tav. de vraag ‘zijn de verschillen wel verklaarbaar?’. De metingen worden ook gebruikt voor regressie

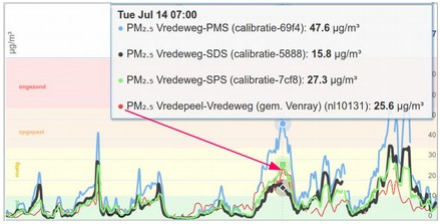
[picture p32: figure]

Kalibratie van lokale Luchtkwaliteitsmetingen in de regio St. Anthonis | V4.3 | 5

berekeningen in referentie met de MetOne fijn stof sensor maar ook onderling per type sensor.
De grafiek met de (ongekalibreerd) waarden visualiseert het verschillen tussen de vier typen toegepaste fijn stof sensoren voor de 2e

en 3e

week in juli 2020.
Duidelijk is te zien dat de Plantower sensor nogal overdrijft (tot zelfs met een factor 2) zodra de fijn stof concentratie boven de 15 μg/m³
komt. Voor PM2.5 van
Nova en Sensirion lopen de grafieken redelijk synchroon. De Nova en Sensirion PM2.5 waarden lopen iets minder gelijk met de metingen van de MetOne. Voor PM10 is dat een stuk minder. Op zich is dat laatste niet zo erg als de focus ligt op PM2.5 waarden. Immers PM2.5 (massa) concentraties heeft i.v.m. de gezondheidsproblematiek momenteel de meeste aandacht.
Een belangrijke kalibratievraag luidt: met welke zekerheids- (in jargon: R-kwadraat) factor (liefst is R²

> 0.7) en met welk algoritme kunnen de meting herberekenen zodat we de grafieken beter onderling kunnen vergelijken. De berekening is afhankelijk van lokale omstandigheden en onderstaande tabel geldt alleen voor locaties nabij Vredepeel.

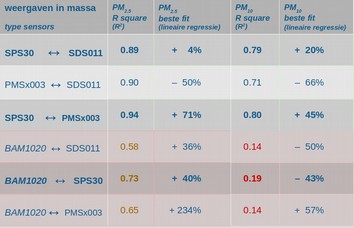
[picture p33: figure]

Bovenstaande calibratie tabel geeft n.a.v. een regressie berekening in 2e

helft van
2020 uitgevoerd is m.b.t. tot de vier typen fijn stof sensoren in Vredepeel. De regressieberekening is helaas nu wat gedateerd!
De real-time visualisatie (grafieken) die getoond worden op de website van Behoud de Parel daar zijn afgezien van de metingen door de MetOne de meetwaarden berekend alsof alle meetkits uitgevoerd zijn met een Sensirion SPS30 sensor.
Een selectie van de gebruikte referentie informatie
Development and Implementation of a Platform for Public Information on Air Quality, Sensor Measurements, and Citizen Science (RIVM, 1 augustus 2018)⁹
De publikatie in Atmosphere (MDPI) belicht de uitdagingen bij toepassing van low-cost sensoren bij luchtkwaliteitsmonitoring in samenwerking met lokale citizen science initiatieven. De kalibratie techniek is nog in ontwikkeling. Enkele

9 https://www.mdpi.com/2073-4433/10/8/445

Kalibratie van lokale Luchtkwaliteitsmetingen in de regio St. Anthonis | V4.3 | 6

voorbeelden proeven met fijn stof sensor (Nova) in Amsterdam en Utrecht, en kalibratie algoritme worden meer in detail besproken.
Size-Resolved Field Performance of Low-Cost Sensors for Particulate Matter Air Pollution (Envonmental Science and Technical Letters, 2023, Rueda e.a.)¹⁰
Een onderzoek naar meetverschillen tussen een drietal recente low-cost fijn stof sensoren (Piera-1, Plantower en Sensirion) ten opzichte van een professionele fijn stof sensor (deeltjes teller) van de fabrikant Grimm.

Overview of methods to access population exposure to ambient air population (WHO, 26 september 2023)¹¹
Gebaseerd op een keur van wetenschappelijke onderzoeken geeft het artikel een goed overzicht van luchtkwaliteitsmeet- en model vormende methoden om een inschatting te kunnen maken van luchtkwaliteitsconcentraties en monitor maatregelen tot op straat niveau bijv. met low-cost sensoren en referentie sensoren. De focus ligt op de blootstelling aan fijn stof PM2.5 als indicator (Sustainable Development Good SDG indicator 11.6.2), en overgang naar concentratie metingen van aantal deeltjes (PNC Particular Number Concentration van bijv. NOx). Het geeft een zwakte en sterkte overzicht van de verschillende gehanteerde modellen en afhankelijkheid van de low-cost metingen t.a.v. bijv. luchtvochtigheid.

### Nawoord

Met fijn stof low-cost fijn stof sensorenconcentratie metingen meet je lokale concentraties. Ook na validatie en kalibratie zijn dit soort concentratie metingen indicatief. Uiteindelijk moeten deze lokale metingen via een data analyse tot duidelijkheid van de blootstelling aan bepaalde emissies.
Waarom en waarvoor meten we eigenlijk?
Ter voorbereiding van de SLA Participatiedag op 29 november 2023 georganiseerd door RIVM Bilthoven, is de notitie ‘ Werkkader pro (https://www.bwlvc.eu/wp-content/uploads/2020/03/Werkkader-en-Organisatiestructuur-Luchtkwaliteitsmeetprojecten.pdf) je (https://www.bwlvc.eu/wp-content/uploads/2020/03/Werkkader-en-Organisatiestructuur-Luchtkwaliteitsmeetprojecten.pdf) ct luch (https://www.bwlvc.eu/wp-content/uploads/2020/03/Werkkader-en-Organisatiestructuur-Luchtkwaliteitsmeetprojecten.pdf) t (https://www.bwlvc.eu/wp-content/uploads/2020/03/Werkkader-en-Organisatiestructuur-Luchtkwaliteitsmeetprojecten.pdf) kwaliteits (https://www.bwlvc.eu/wp-content/uploads/2020/03/Werkkader-en-Organisatiestructuur-Luchtkwaliteitsmeetprojecten.pdf) mee (https://www.bwlvc.eu/wp-content/uploads/2020/03/Werkkader-en-Organisatiestructuur-Luchtkwaliteitsmeetprojecten.pdf) tnet -werken’ (https://www.bwlvc.eu/wp-content/uploads/2020/03/Werkkader-en-Organisatiestructuur-Luchtkwaliteitsmeetprojecten.pdf)

12 samen met ver. Behoud de Parel uitgebracht. Hierin wordt geprobeerd een antwoord op de vraag ‘Wat nu?’ te geven: het ontbreekt meestal aan een data analyse die aansluit bij de informatiebehoefte van de lokale overheid. Zonder duidelijkheid over de mogelijke maatregelen en ondernomen acties en mogelijke maatregelen heeft het lokaal meten geen zin.
Het mag niet alleen een project zijn dat alleen maar leidt tot bewustwording en daarmee niet leidt tot het doel van de afspraken binnen het Schone Lucht Akkoord: maatregelen en acties met een 50% gezondheidswinst op een niet al te lange termijn.
“Om het meten van nut te laten zijn
moet je als lokale overheid en ondernemer nu toch wel snel bokkensprongen gaan maken!

Tom Poes, verzin een list.
“
Auteur: Teus Hagen, MySense project van ver. Behoud de Parel.

10 https://pubs.acs.org/doi/10.1021/acs.estlett.3c00030?ref=pdf
11 https://www.who.int/publications/i/item/9789240073494
12 PDF document https://www.bwlvc.eu/wp-content/uploads/2020/03/Werkkader-en-Organisatiestructuur-Luchtkwaliteitsmeetprojecten.pdf (https://www.bwlvc.eu/wp-content/uploads/2020/03/Werkkader-en-Organisatiestructuur-Luchtkwaliteitsmeetprojecten.pdf)
Kalibratie van lokale Luchtkwaliteitsmetingen in de regio St. Anthonis | V4.3 | 7

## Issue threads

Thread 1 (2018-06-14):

No attribute 'BME_I2C'

Thosch42, 2018-06-14:
Hi!!
First of all - Very nice project!!
I tried to test a BME680 and run into the following problem:

```
4251 - Using BME680 config I2C 0 SDA on pin P8, SCL on pin P9
4254 - Traceback (most recent call last):
4258 -   File "meteo_test.py", line 30, in <module>
4263 - AttributeError: 'module' object has no attribute 'BME_I2C'
5506 - Pycom MicroPython 1.18.0 [v1.8.6-849-046b350] on 2018-06-01; LoPy4 with ESP32
```
I'm pretty new to MicroPython. As far as I understand, the BME680 library ist imported as BME. But the class in the BME library is called BME680. The BME_I2C class is defined in BME_I2C.py. But this library seems to be never imported.

Could you give me an advise?

Best regards,
Thomas

teusH, 2019-05-28:
Issue has been resolved in a later release.

Closed 2019-05-28.

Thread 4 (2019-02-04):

Q: Sensirion SPS30 with LoPy4 ?

justb4, 2019-02-04:
Great project! Obtained a [Sensirion SPS30 PM sensor ](https://www.antratek.nl/particulate-matter-sensor-sps30) , found no drivers yet, e.g. on https://github.com/Sensirion.

Question is: are you aware of any people/projects combining SPS30 with LoPy4? I also asked via Sensirion contact page (there is no support forum).

I have some Python skills and experience in other AQ projects like [SmartEmission](https://data.smartemission.nl/). But before I start such activity I am asking around first. Ideally we collaborate with Sensirion on their GH.

teusH, 2019-05-28:
Due to the fact that I mainly use github from command line I did not notice the question about SPS30 PM sensor and LoPy-4. See the tree PyCom/lib in MySense. There you will find a fully supported driver written in Python for the SPS30 PM sensor. The driver is operational and is used in about 5 kits already. The driver has been tested under python2 and 3 on Raspberry Pi as well LoPy-4. Give feedback if there are improvements.

justb4, 2019-05-28:
Ok, thanks @teusH !

Closed 2019-05-28.

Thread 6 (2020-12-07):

BME 280 and BME 680 I2C meteo driver outdated

teusH, 2020-12-07:
The used I2C BME (outdated Adafruit) drivers use bit shifts. This will lead to wrong temperature and air pressure values.
Needs to be updated with the newer Adafruit drivers which do not use shifts in the Python code to encounter the 32 bit CPU architecture of eg PyCom ESP boards.

Closed 2025-02-21.

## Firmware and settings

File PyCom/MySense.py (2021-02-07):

# PyCom Micro Python / Python 3
# Copyright 2018, Teus Hagen, ver. Behoud de Parel
# Open Source Initiative  https://opensource.org/licenses/RPL-1.5
#
#   Unless explicitly acquired and licensed from Licensor under another
#   license, the contents of this file are subject to the Reciprocal Public
#   License ("RPL") Version 1.5, or subsequent versions as allowed by the RPL,
#   and You may not copy or use this file in either source code or executable
#   form, except in compliance with the terms and conditions of the RPL.
#
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
# $Id: MySense.py,v 7.1 2021/02/07 14:16:32 teus Exp teus $

__version__ = "0." + "$Revision: 7.1 $"[11:-2]
__license__ = 'RPL-1.5'

import sys
from time import sleep_ms, time
from micropython import const
try:
  from pycom import wifi_on_boot
except: pass
myTicks_ms = 0
myTicks = 0
# Turn off hearbeat LED
from pycom import heartbeat, nvs_set, nvs_get, nvs_erase
heartbeat(False)
import os
PyCom = 'PyCom %s' % os.uname().nodename
del os
LED = None
try:
  import led
  LED = led.LED()
except: pass
debug = True  # enable print dictionary
wokeUP = False
from machine import WDT
wdt    = None # watch dog

MyConfig = None      # handle to ConfigJson object
MyConfiguration = {} # configuration stable between deepsleeps and power cycle
MyDevices = {} # dyn. part, has bus refs to device dict with conf
MyTypes = {}   # dyn. part, has type refs to device dict with conf
MyNames = [('meteo','i2c'),('display','i2c'),('dust','ttl'),('gps','ttl'),('accu','pin'),('deepsleep','pin')]
lastGPS = [0,0,0]
Alarm = None              # tuple (nr,value)
AlarmAccu = const(13)     # event on empty accu, has accu level
AlarmWDT = const(14)      # watchdog sensor event, has marks
AlarmReset = const(15)    # unexpected exit of runMe()

import struct
Threading = True
if Threading:
  import _thread
  # _thread.stack_size(6144)

# LoRa ports
# data port 2 old style and ug/m3, 4 new style grain, pm4/5 choice etc
Dprt = (2,4)    # data ports
Iprt = const(3) # info port, meta data, events

# oled is multithreaded
STOP = False
STOPPED = False
HALT = False  # stop by remote control
LAT = const(0)
LON = const(1)
ALT = const(2)

def MyMark(mark): # watchdog: sensor timeout mark
  global MyConfiguration
  global wdt
  try:
    if not wdt:
      wdt = WDT(timeout=(MyConfiguration['interval']['interval']*3*1000))
    else: wdt.feed()
  except: pass
  nvs_set('AlarmWDT',mark)

# return bus or if bus [type(s)]
def Type2Bus(atype): # and visa versa
  global MyNames
  rts = []
  for item in MyNames:
    if (atype == item[1]) and (not atype in rts): rts.append(item[0])
    elif atype == item[0]: return item[1]
  return rts

def Type2Dev(atype):
  global MyTypes, MyDevices
  try: return MyDevices[Type2Bus(atype)][atype]
  except: return None

def PrintDict(adict = None, header=''):
  global debug
  if not debug: return
  global MyConfiguration, MyDevices
  if adict != None:
    print("dict '%s'->" % header)
    for item in adict.items():
      try: print("    '%s'-> %s" % (item[0], str(item[1])))
      except: pass
  else:
    PrintDict(MyConfiguration,'MyConfiguration')
    PrintDict(MyDevices,'MyDevices')

# identity PyCom SN
def getSN():
  from machine import unique_id
  import binascii
  SN = binascii.hexlify(unique_id()).decode('utf-8')
  return SN

def ticks(): # wrap in Jan 2038
  global myTicks, myTicks_ms
  from time import ticks_ms, ticks_diff
  now = ticks_ms()
  if not myTicks:
    myTicks_ms = now
    myTicks = int((now+500)/1000)
  else:
    myTicks += int((ticks_diff(myTicks_ms,now)+500)/1000)
    myTicks_ms = now
  return myTicks

def getSavedGPS():
  # global LAT, LON, ALT
  try:
    return [nvs_get('LAT')/1000000.0,nvs_get('LON')/1000000.0,nvs_get('ALT')/10.0]
  except: return [0,0,0]

def saveGPS(curGPS):
  global LAT, LON, ALT
  nvs_set('LAT',int(curGPS[LAT]*1000000))
  nvs_set('LON',int(curGPS[LON]*1000000))
  nvs_set('ALT',int(curGPS[ALT]*10))
  return curGPS[0:]

# Read accu voltage out
def getVoltage(debug=False): # range 0 (None) and 11.4 (88% low) - 12.5 (high)
  global MyConfiguration, MyConfig
  if not MyConfig: initConfig()
  atype = 'accu'
  volts = (0,0,0)
  if not initAccu(): return volts
  accuPin = 'P17'
  try: accuPin = MyConfiguration['accuPin']
  except: pass
  try: volts = [(ADC(0).channel(pin=accuPin, attn=ADC.ATTN_11DB).value())*0.004271845]
  except: return (0,0,0)
  if volts[0] > 0.1:  # accu attached
    for i in range(9): # 10 sec sample
      sleep_ms(500)
      volts.append((ADC(0).channel(pin=accuPin, attn=ADC.ATTN_11DB).value())*0.004271845)
    volts = (min(volts),sum(volts)/len(volts),max(volts))
    if debug: print('volts (min,avg,max): %s' % str(volts))

    mmax = None
    try: mmax = nvs_get('Vmax')/10.0
    except: pass
    if mmax == None: mmax = 0
    if volts[1] > (mmax + 0.09):
      nvs_set('Vmax', int(volts[1]*10.0+0.5))
    mmin = None
    try: mmin = nvs_get('Vmin')/10.0
    except: pass
    if mmin == None: mmin = 100
    if volts[1] < (mmin - 0.09):
      nvs_set('Vmin', int(volts[1]*10.0-0.5))
    if debug: print("Accu V: %.2f [%.2f - %.2f]" % (volts[1],mmin,mmax))

  return volts

# sleep phases all active till config done after cold start, then:
#    sleep pin not set & power sleep False: sleep, rgb led, wifi
#    pin set & power sleep False: deepsleep, while active: rgb led, wifi on
#    pin set & power sleep True: deepsleep, while active: no rgb led, wifi off
# clear config in flash on: cold start & no accu attached & no sleep pin

# deepsleep pin set?
def deepsleepMode():
  global MyDevices, MyConfig, MyConfiguration, MyTypes
  if not MyConfig: initConfig()
  atype = 'deepsleep'
  try:
    if not 'sleepPin' in MyConfiguration.keys():
      sleepPin = 'P18'
      try: from Config import sleepPin
      except: pass
      MyConfig.dump('sleepPin',sleepPin)
      MyConfiguration['sleepPin'] = sleepPin
    else: sleepPin = MyConfiguration['sleepPin']
    if not atype in MyDevices.keys():
      from machine import Pin
      MyTypes[atype] = MyDevices[atype] = { 'lib': Pin(sleepPin,mode=Pin.IN), 'type': atype}
    return (True if MyDevices[atype]['lib'].value() else False)
  except: return False

def setWiFi(reset=False,debug=False):
  global MyConfiguration, wokeUp
  cnt = 0
  try: cnt = nvs_get('count')
  except: pass
  if not cnt: cnt = 0
  periods = 4
  try: periods = int(4500/MyConfiguration['interval']['interval'])
  except: pass
  if reset:
    nvs_set('count',0)
    if cnt > periods: cnt = periods # enable wifi
    else: cnt = 0
  else: nvs_set('count',cnt+1)
  if cnt == periods: # after nr periods turn wifi off or give it new ssid/pass
    from network import WLAN
    wlan = WLAN()
    try:
      W_SSID = 'MySense-AAAA'; W_PASS = 'www.mycom.io'
      if not reset:
        if MyConfiguration['power']['wifi']:
          wlan.deinit() # switch wifi off
          display("WiFi AP: off",xy=(0,0))
          if wokeUp:
            import pycom
            if pycom.wifi_on_boot(): pycom.wifi_on_boot(False)
          return False
        try: from Config import W_SSID
        except: pass
        try: from Config import W_PASS
        except: pass
      if W_SSID[-4:] == 'AAAA': W_SSID = W_SSID[:-4]+getSN()[-4:].lower()
      display("WiFi AP: %s" % W_SSID,xy=(0,0))
      display("pass: %s" % W_PASS)
      sleep_ms(5*1000)
      wlan.init(mode=WLAN.AP,ssid=W_SSID, auth=(WLAN.WPA2,W_PASS), channel=7, antenna=WLAN.INT_ANT)
    except: return False
  return True

# reset MySense
def MyReset(cause=None):
  import os
  try: os.remove('/flash/MySenseConfig.json'); print("Cleared MySense config")
  except: pass
  # delete frequently changed status variables
  from pycom import nvs_erase_all
  nvs_erase_all(); print("Cleared nvs mem")
  if cause:
    nvs_set('myReset',1); nvs_set('AlarmWDT',cause) # send reset
    import machine
    machine.reset() # full reset LoPy

## configuration from flash
def initConfig(debug=False):
  global MyConfiguration, MyConfig
  global wokeUp, Alarm, AlarmWDT

  if MyConfig: return

  from machine import wake_reason, RTC_WAKE, reset_cause, WDT_RESET
  from pycom import nvs_get, nvs_set
  wokeUp = wake_reason()[0] == RTC_WAKE # deepsleep wake up
  Alarm = None; AlarmT = None           # look for alarm event
  try: Alarm = nvs_get('myReset')
  except: pass
  if Alarm:
    nvs_erase('myReset')
    AlarmT = AlarmReset
  elif reset_cause() == WDT_RESET:
    AlarmT = AlarmWDT
  if AlarmT:
    try: Alarm = nvs_get('AlarmWDT') # where?
    except: pass
    Alarm = (AlarmT,Alarm) # got WDT timeout or runMe() fail
  else: Alarm = None
  nvs_set('AlarmWDT',0)

  import ConfigJson
  MyConfig = ConfigJson.MyConfig(archive=(not wokeUp), debug=debug)
  MyConfiguration = MyConfig.getConfig()
  if not wokeUp: # check startup mode
    modus = None
    try: modus = nvs_get('modus')
    except: pass
    if not modus:
      if MyConfiguration: MyConfig.clear # not def or 0: no archived conf
      MyConfiguration = dict()
      from pycom import nvs_erase_all
      nvs_erase_all()
    elif modus  == 1: # reset only discovered devices
      for abus in ['ttl','i2c']:
        try: MyConfiguration[abus] = dict()
        except: pass
    nvs_set('gps',-1)
    nvs_set('count',0)

def DEEPSLEEP(secs,debug=False):
   print('Deepsleep of %d secs' % secs)
   MyMark(82)
   PinPower(atype=['gps','dust'],on=False ,debug=debug) # cure RTC fail?
   nvs_set('AlarmSlp', secs)
   if secs <= 30:
     print("May not happen")
     return
   from machine import deepsleep
   deepsleep(secs*1000)
   # never arrive here: warm reboot

## CONF pins
def getPinsConfig(debug=False):
  global MyConfiguration, MyConfiguration, wokeUp
  global MyConfig
  if not MyConfig: initConfig()
  deepsleepMode() # deepsleep pin conf

# check to send low accu level event
def accuLow():
  global MyConfiguration
  # too low: led flash red, deepsleep only via main.py
  if not 'accuLevel' in MyConfiguration.keys(): return False
  volts = getVoltage()
  cnt = None
  try: cnt = nvs_get('aLow')
  except: pass
  if 0.1 < volts[1] <= MyConfiguration['accuLevel']+0.2:
    MyMark(13)
    from pycom import rgbled
    for i in range(5):
      sleep_ms(i*60); pycom.rgbled(0xff0000)
      sleep_ms(100); pycom.rgbled(0x000000)
    if not cnt: cnt = 0
    cnt += 1
    if cnt < 4:  # max events sent
      global Alarm, AlarmAccu # show event
      Alarm = (AlarmAccu,int(volts[1]*10))
    elif cnt > 10: cnt = 1
    nvs_set('aLow',cnt)
  elif cnt != None and (volts[1] > MyConfiguration['accuLevel']+0.2):
    nvs_erase('aLow') # back to normal
  return False

## CONF busses
def getBusConfig(busses=['i2c','ttl'], devices=None, debug=False):
  global MyConfig
  global MyConfiguration, MyDevices, MyTypes

  if not MyConfig: initConfig()
  if debug:
    PrintDict(MyConfiguration,'Start: Archived configuration')
    PrintDict(MyDevices,'My Devices')
  for abus in busses:
    if not abus in MyConfiguration.keys(): MyConfiguration[abus] = {}
    FndDevices = []
    if devices == None: busdevices = Type2Bus(abus) # use dflt
    else: busdevices = devices
    if debug: print("bus %s with devices: %s" % (abus, str(busdevices)))
    for dev in MyConfiguration[abus].keys():
      if not dev in busdevices: continue
      FndDevices.append(dev)
      if debug: print("Reuse dev %s config: %s" % (dev, str(MyConfiguration[abus][dev])))
    if abus == 'i2c': import whichI2C as which
    elif abus == 'ttl': import whichUART as which
    # PrintDict(MyConfiguration[abus],'MyConfiguration[%s]' % abus)
    if MyConfiguration[abus]:
      which = which.identification(identify=True, config=MyConfiguration[abus], debug=debug)
    else:
      which = which.identification(identify=True, debug=debug)
      MyConfiguration[abus] = which.config
      if debug: print("Bus %s: found %s types of devices" % (abus,str(MyConfiguration[abus].keys()) ))
    for atype in MyConfiguration[abus].keys():
      if not atype in busdevices: continue
      if not atype in FndDevices:
        if debug: print("New dev %s config: %s" % (atype, str(MyConfiguration[abus][atype])))
        MyConfig.dump(atype, MyConfiguration[abus][atype],abus=abus)
      if not abus in MyDevices.keys(): MyDevices[abus] = {}
      MyDevices[abus][atype] = which.getIdent(atype=atype)
      MyDevices[abus][atype]['type'] = atype
      MyTypes[atype] = MyDevices[abus][atype]
      # PrintDict(MyDevices[abus][atype],'MyDevices[%s][%s]' % (abus,atype))
      if 'conf' in MyDevices[abus].keys():
        print("WARNING found 'conf' in MyDevices[%s]" % abus)
        del MyDevices[abus] # strange

## CONF network
def getNetConfig(debug=False):
  global MyConfiguration, MyConfig, MyDevices, MyTypes
  global wokeUp

  if not MyConfig: initConfig()
  Network = 'TTN' # dflt
  if 'LoRa' in MyConfiguration.keys(): Network = 'TTN'
  if not wokeUp:
    try: from Config import Network
    except: pass
  if not Network in ['TTN', None]: raise ValueError("%s not supported" % Network)

  if Network == 'TTN':
    atype = 'lora'
    MyDevices[atype] = { 'name': Network, 'type': atype, 'enabled': False, 'lib': None }
    # 'LoRa' in config: use lora nvram
    if MyConfig.getConfig('LoRa') in ['ABP','OTAA']:
      if debug: print("Use LoRa nvram")
    #else: MyDevices[atype]['lib'].cleanup # will clear LoRa

    info = None
    MyDevices[atype]['method'] = {}
    if not wokeUp: # no keys in nvram or set them
      # lora routine will first try nvram restore and join (for ABP and cold start)
      if not 'LoRa' in MyConfiguration.keys():
        try: # OTAA keys preceeds ABP
          from Config import dev_eui, app_eui, app_key
          MyDevices[atype]['method']['OTAA'] = (dev_eui, app_eui, app_key)
          MyConfig.dump('LoRa','TTN')
        except: pass
        try: # ABP keys
          from Config import dev_addr, nwk_swkey, app_swkey
          MyDevices[atype]['method']['ABP'] = (dev_addr, nwk_swkey, app_swkey)
          MyConfig.dump('LoRa','TTN')
        except: pass
        if not len(MyDevices[atype]['method']):
          raise ValueError("No LoRa keys configured or LoRa config error")
        if debug: print("Init LoRa methods: %s." % ', '.join(MyDevices[atype]['method'].keys()))
        MyConfiguration['LoRa'] = MyConfig.getConfig('LoRa')
      else:
        if debug: print("Using LoRa %s info from nvram" % MyConfiguration['LoRa'])
        MyDevices[atype]['method'][MyConfiguration['LoRa']] = (None,None,None)
    MyTypes['network'] = MyDevices[atype]
    if wokeUp: info = True # no need to send meta data
  else: None # no output

def getGlobals(debug=False):
  global MyConfiguration, MyConfig, wokeUp
  if not MyConfig: initConfig()
  global lastGPS
  ## CONF interval
  if not 'interval' in MyConfiguration:
    MyConfiguration['interval'] = {
       'sample': 60,      # dust sample in secs
       'interval': 15,    # sample interval in minutes
       'gps':      3*60,  # location updates in minutes
       'info':     24*60, # send kit info in minutes
    }
    try:
      from Config import interval
      if type(interval) is dict: MyConfiguration['interval'].update(interval)
    except: pass
    for item in ['interval','gps','info']:
      MyConfiguration['interval'][item] *= 60
      if MyConfiguration['interval']['interval'] <= 0:
        MyConfiguration['interval']['interval'] = 0.1
    MyConfig.dump('interval',MyConfiguration['interval'])
  if not wokeUp:
    # item for next time to send info: wrap around on 19 jan 2038!
    for item in ['gps_next','info_next']: # secs next send, reset to 0
      value = None
      try: value = nvs_get(item)
      except: pass
      if not value: nvs_set(item,0)
    nvs_set('gps',-1)

  ## CONF power mgt
  # device power management dflt: do not unless pwr pins defined
  # power mgt of ttl/uarts OFF/on, i2c OFF/on
  # deepsleep mode: deep sleep OFF/on, ON with deepsleep pin
  # display: None (always on), False: always off, True on and off during sleep
  # Warning: sleep pin P18 with no voltage on accu pin: clear config json file
  if not 'power' in MyConfiguration.keys():
    try:
      from Config import Power
      MyConfiguration['power'] = Power
    # deflt: no power mgt on ttl, i2c, display power mngt is used
    except:
      MyConfiguration['power'] = { 'ttl': False, 'i2c': False, 'sleep': False, 'display': None, 'led': False, 'wifi': True }
    if not wokeUp: MyConfig.dump('power', MyConfiguration['power'])
  if deepsleepMode():
    for i in ['ttl','i2c']: MyConfiguration['power'][i] = True
  # sleep dflt True: listen to pin mode

  ## CONF calibrate
  if not 'calibrate' in MyConfiguration.keys():
    # calibrate dict with lists for sensors { 'temperature': [0,1], ...}
    try: from Config import calibrate
    except: MyConfiguration['calibrate'] = {}      # sensor calibration Tayler array
    if not wokeUp: MyConfig.dump('calibrate',MyConfiguration['calibrate'])

  ## CONF dflt location
  if not 'thisGPS' in MyConfiguration.keys():
    thisGPS = [0.0,0.0,0.0]
    try: from Config import thisGPS # predefined GPS coord
    # location
    except: pass
    finally:
      MyConfiguration['thisGPS'] = thisGPS # completed by GPS
      MyConfig.dump('thisGPS',MyConfiguration['thisGPS'])
      lastGPS = getSavedGPS() # from nvs
      if not lastGPS[0]:
        lastGPS = MyConfiguration['thisGPS'][0:]
      nvs_set('gps_next',0)

## oled display routines
def oledShow():
  global MyTypes
  try:
    Display = MyTypes['display']
    if not Display['conf']['use'] or not Display['enabled']: return
    if not Display['lib']: return
  except: return
  for cnt in range(0,4):
    try:
      Display['lib'].show()
      break
    except OSError as e: # one re-show helps
      if cnt: print("show err %d: " % cnt,e)
      sleep_ms(500)

nl = 16 # line height
LF = const(13)
# text display, width = 128; height = 64  # display sizes
def display(txt,xy=(0,None),clear=False, prt=True):
  global MyTypes, nl
  if not MyTypes: getMyConfig()
  Display = None
  try:
    Display = MyTypes['display']
    if not Display['lib']:
      if not initDisplay(): Display = None
  except: pass
  if Display and Display['enabled'] and Display['conf']['use'] and Display['lib']:
    offset = 0
    if xy[1] == None: y = nl
    elif xy[1] < 0:
      if -xy[1] < LF:
        offset = xy[1]
        y = nl - LF
    else: y = xy[1]
    x = 0 if ((xy[0] == None) or (xy[0] < 0)) else xy[0]
    if clear:
      Display['lib'].fill(0)
    if y > 56:
      nl =  y = 16
    if (not offset) and (not clear):
      rectangle(x,y,128,LF,0)
    Display['lib'].text(txt,x,y+offset)
    oledShow()
    if y == 0: nl = 16
    elif not offset: nl = y + LF
    if nl >= (64-13): nl = 16
  if prt: print(txt)

def rectangle(x,y,w,h,col=1):
  global MyTypes
  try: Display = MyTypes['display']
  except: return
  if not Display['conf']['use'] or not Display['enabled']: return
  dsp = Display['lib']
  if not dsp: return
  ex = int(x+w); ey = int(y+h)
  if ex > 128: ex = 128
  if ey > 64: ey = 64
  for xi in range(int(x),ex):
    for yi in range(int(y),ey):
      dsp.pixel(xi,yi,col)

def ProgressBar(x,y,width,height,secs,blink=0,slp=1):
  global LED, STOP
  if x+width >= 128: width = 128-x
  if y+height >= 64: height = 64-y
  rectangle(x,y,width,height)
  if (height > 4) and (width > 4):
    rectangle(x+1,y+1,width-2,height-2,0)
    x += 2; width -= 4;
    y += 2; height -= 4
  elif width > 4:
    rectangle(x+1,y,width-2,height,0)
    x += 2; width -= 4;
  else:
    rectangle(x,y,width,height,0)
  step = width/(secs/slp); xe = x+width; myslp = slp
  if blink: myslp -= (0.1+0.1)
  for sec in range(int(secs/slp+0.5)):
    if STOP:
      return False
    if blink:
      if LED: LED.blink(1,0.1,blink,l=False)
    sleep_ms(int(myslp*1000))
    if x > xe: continue
    rectangle(x,y,step,height)
    oledShow()
    x += step
  return True

def showSleep(secs=60,text=None,inThread=False):
  global nl, STOP, STOPPED
  global MyTypes
  try:
    Display = MyTypes['display']
    ye = y = nl
    if text:
      display(text)
      ye += LF
    if Display['lib'] and Display['enabled'] and Display['conf']['use']:
      ProgressBar(0,ye-3,128,LF-3,secs,0x004400)
      nl = y
      rectangle(0,y,128,ye-y+LF,0)
      oledShow()
    else: raise ValueError()
  except: sleep_ms(int(secs*1000))
  if inThread:
    STOP = False
    STOPPED = True
    _thread.exit()
  return True

def DisplayInThread(secs=60, text=None):
  global STOP, STOPPED, Threading
  if not Threading:
    STOPPED=True
    raise ValueError('No threading')
  STOP = False; STOPPED = False
  try:
    _thread.start_new_thread(showSleep,(secs,text,True))
  except Exception as e:
    STOPPED=True
    Threading = False
    raise ValueError("threading failed: %s" % e)
  sleep_ms(1000)
# end of display routines

# check/set power on device
def PinPower(atype=None,on=None,debug=False):
  global MyConfiguration
  if not atype: return False
  if type(atype) is list:
    for item in atype:
      PinPower(atype=item, on=on, debug=debug)
  else:
    abus = Type2Bus(atype)
    try:
      if not MyConfiguration[abus][atype]['use']: return None
      pins = MyConfiguration[abus][atype]['pins']
      len(pins) == 3
      if debug: print("Use %s power pins %s, on=%s" % (atype,pins,str(on)))
    except:
      if debug: print("Power pin %s missing" % atype)
      return None
    if not type(pins[2]) is str: return None
    from machine import Pin
    pin = Pin(pins[2], mode=Pin.OUT)
    if on == None: return pin.value()
    elif on:
      if pin.value(): return True
      if debug: print("Activate %s chan (Tx,Rx,Pwr)=%s: " % (abus,str(pins)))
      pin.value(1); sleep_ms(200); return False
    elif pin.value():
      try:
        # if true powercycle the bus. with GPS power cycling costs delays; dflt false
        if not MyConfiguration['power'][abus]: return True
      except: pass
      if debug: print("Deactivate %s chan (Tx,Rx,Pwr)=%s: " % (abus,str(pins)))
      pin.value(0); sleep_ms(200); return True
    else: return False
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

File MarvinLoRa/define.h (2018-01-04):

uint8_t statusNow = 0;

const uint8_t dataLength = 200;
uint8_t fifoData[dataLength];

const uint8_t receiveDataLength = 50;
char receiveData[receiveDataLength];

const int sendStringLength = 17;
char sendStrings[sendStringLength] ="";

uint8_t restTime = 0;
uint8_t newThreshold = 0;
uint8_t newThresTime = 0;

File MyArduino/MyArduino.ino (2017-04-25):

/**
 * The MySensors Arduino library handles the wireless radio link and protocol
 * between your home built sensors/actuators and HA controller of choice.
 * The sensors forms a self healing radio network with optional repeaters. Each
 * repeater and gateway builds a routing tables in EEPROM which keeps track of the
 * network topology allowing messages to be routed to nodes.
 *
 * Created by Henrik Ekblad <henrik.ekblad@mysensors.org>
 * Copyright (C) 2013-2015 Sensnology AB
 * Full contributor list: https://github.com/mysensors/Arduino/graphs/contributors
 *
 * Documentation: http://www.mysensors.org
 * Support Forum: http://forum.mysensors.org
 *
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
 *******************************
 * DESCRIPTION
 * 
 * Dust Sensor for Shinyei ppd42ns
 *  
 * 1 : COMMON(GND)
 * 2 : OUTPUT(P2)
 * 3 : INPUT(5VDC 90mA)
 * 4 : OUTPUT(P1)
 * 5 : INPUT(T1)･･･FOR THRESHOLD FOR [P2] - not used
 *
 * http://www.seeedstudio.com/wiki/images/4/4c/Grove_-_Dust_sensor.pdf
 * 
 *   connect the sensor as follows :
 *    Pin 4 of dust sensor PM1      -> Digital 9
 *    Pin 3 of dust sensor          -> +5V 
 *    Pin 2 of dust sensor PM25    -> Digital 8
 *    Pin 1 of dust sensor          -> Ground
* Contributor: epierre and alexsh1
 * MySense changes: Teus, March 2017
**/

String version = "1.08";

String type = "PPD42NS";
#define DUST_SENSOR_DIGITAL_PIN_PM10  9
#define DUST_SENSOR_DIGITAL_PIN_PM25  8

#define LedPIN 12

// variables
unsigned long interval = 60000; // timing reads (in milliseconds)
unsigned long sampletime_ms = 15000;  // timing one sample synchronous
boolean configured = false;
boolean ack = false;
int scale = 10;                 // scale to Dylos range
String StrBuf = "";

void setup()
{
  Serial.begin(9600);
  while(!Serial) {
    ;
  }
  pinMode(LedPIN,OUTPUT); // signals configuration mode and sampling mode
  pinMode(DUST_SENSOR_DIGITAL_PIN_PM10,INPUT);
  pinMode(DUST_SENSOR_DIGITAL_PIN_PM25,INPUT);
  digitalWrite(LedPIN,HIGH);


}

// get interval configuration if available
void configure(char cmd)
{
  unsigned long timing1 = 0;
  unsigned long timing2 = 0;
  unsigned long endTime;
  Serial.setTimeout(60000); // after one minute use defaults
  digitalWrite(LedPIN,HIGH);
  // Serial.println("Configuring");
  Serial.println("{}");
  sampletime_ms = 20000; // defaults
  interval = 60000;
  ack = false;
  endTime = millis() + 60000;
  if ( cmd != 'C' ) {
    while ( Serial.available() <= 0 ) {
      if ( millis() > endTime ) {
        break;
      }
      delay(300);
    }
  }
  configured = true;
  // configure: C interval sampleTime RequestTiming \n (timeout 15 seconds)
  Serial.print("{");
  digitalWrite(LedPIN,HIGH);
  while ( Serial.available() > 0 ) {
    if ( timing1 == 0 ) {
      timing1 = Serial.parseInt();
      //Serial.print("interval: "); Serial.println(timing1);
      if ( (timing1 >= 0) and (timing1 <= 3600) ) {  // 60 minutes max
        if (timing1 == 0) { ack = true; }
        else { interval = timing1 * 1000 + 200; }
      }
      timing1 = 1;
      continue;
    } else if ( timing2 == 0 ) {
      timing2 = Serial.parseInt();
      //Serial.print("sample time: "); Serial.println(timing2);
      if ( (timing2 > 0) and (2000*timing2 <= interval) ) {
        sampletime_ms = timing2 * 1000;
      }
      timing2 = 1;
      continue;
    } else {
      do {
        cmd = Serial.read();
        if( cmd == 'R' ) {
          ack = true;
          // Serial.println("Request receive");
        } else if ( cmd == '\n' ) {
          break;
        } // else { Serial.println("skipping"); }
      } while ( Serial.available() > 0 );
      continue;
    } 
  }
  // empty serial read buffer
  while ( Serial.available() > 0 ) {
    Serial.read();
  }
  digitalWrite(LedPIN,LOW);
  Serial.print("\"version\":\"" + version + "\",\"type\":\"" + type + "\"");
  Serial.print(",\"interval\":" + String(interval/1000));
  Serial.print(",\"sample\":" + String(sampletime_ms/1000));
  if ( ack ) { Serial.println(",\"request\":true}"); }
  else { Serial.println(",\"request\":false}"); }
  // Serial.println("End of configuration");
  // empty serial read buffer
  while ( Serial.available() > 0 ) {
    Serial.read();
  }
}

void loop()
{
  long sleepTime;
  unsigned long timing;
  char cmd;
  
  if ( not configured ) {
    configure('R');
  }
  
  sleepTime = millis();
  StrBuf = "{";
  printPM((int)DUST_SENSOR_DIGITAL_PIN_PM25,(String)"pm25");
  
  if ( not ack ) {
    sleepTime = interval/2 - (millis() - sleepTime);
    if ( sleepTime > 0 ) {
      delay(sleepTime);
    }
  }
  
  sleepTime = millis();
  StrBuf += ',';
  printPM((int)DUST_SENSOR_DIGITAL_PIN_PM10,(String)"pm10");
  
  Serial.println(StrBuf + "}"); StrBuf = "{";
  
  if ( not ack ) { //sleep to save on radio
    sleepTime = interval/2 - (millis() - sleepTime);
    if ( sleepTime > 50 ) {
      delay(sleepTime);
    }
  }
  if ( ack or (Serial.available() > 0 ) ) {
    sleepTime = millis() + 3600000; // max wait time one hour
    do {
      while ( Serial.available() <= 0 ) {
        if ( millis() > sleepTime ) {
          break;
        }
        digitalWrite(LedPIN,HIGH);
        delay(1000);
        digitalWrite(LedPIN,LOW);
      }
      cmd = Serial.read();
      if ( cmd == '\n' ) {
        break;
      } else if ( cmd == 'C' ) {
        configured = false;
        configure((char)cmd);
      }
    } while (Serial.available() > 0 );
  }    
}

//function to extract decimal part of float
long getDecimal(float val)
{
  if ( val < 0 ) val = (-1)*val;
  int intPart = int(val);
  long decPart = int(100.0*(val-intPart)+0.5); // max 3 decimal places.
  if(decPart==0)return(0);           //return 0 if no decimal part
  return(decPart);
}

void printPM(int pin, String name){
  long concentrationPM;
  float conv;
  
  //get PM density of particles over x μm.
  concentrationPM=(long)getPM((int)pin,(String)name);
  StrBuf += ",\"" + name + "_pcs/qf\":";
  if ( concentrationPM > 0 ) {
    StrBuf += String(concentrationPM/scale);  // divide by 10?
  } else { 
    StrBuf += "null";
  }
  StrBuf += ",\"" + name + "_ug/m3\":";
  if ( concentrationPM > 0 ) {
    conv = (float)conversion(concentrationPM,name);
    StrBuf += String(int(conv)) + "." + String(getDecimal(conv));
  } else {
    StrBuf += "null";
  }
}

// ref: https://github.com/andy-pi/weather-monitor/blob/master/air_quality.py
float conversion(long concentrationPM, String name) {
  double pi = 3.14159;
  double density = 1.65 * pow (10, 12);
  // ref art.: Air Quality Sensor Network for Philadelphia, Arling a.o.
  double r = 0.44;
  if ( name.equals("pm10") ) { r = 2.60; }
  r *= pow (10, -6);
  double vol = (4/3) * pi * pow (r, 3);
  double mass = density * vol;
  double K = 3531.5;
  return (concentrationPM) * K * mass;
}
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

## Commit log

2017-02-22 Initialize with current version
    Sensors are tested on Raspberry PI. Some sensors and output channels are in (pre) alpha test.
    This is the first public version.
2017-02-22 MyDHT.py small error in accepting added port option.
    [MyDHT.py, MySense.py, MyThreading.py]
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2017-02-27 Added debug mode for sensor threads from command line.
2017-03-01 corrections to calibrations
2017-03-08 added wifi install and internet iauto switching connectivity for Pi
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2017-03-30 time key bug solved
    [MyGPS.py]
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2017-03-30 Swap pins PM2.5 and PM10. ug/m3 arithmetic is doubtful.
    [MyArduino.ino]
2017-04-02 convert to ug/m3 correction. Added ref to article.
    [MyArduino.ino]
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2017-04-03 added missing sleep time import
    [MyARDUINO.py]
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2017-04-06 avoid sleep when in sync modus
    [MyThreading.py]
2017-04-06 MySense.py functionality test with input data from Dylos sensor
2017-04-07 corrected sample/interval timing handling. Added energy saving on LED.
    [MyARDUINO.py, MyArduino.ino]
2017-04-10 tool to calibrate sensors between two sensor kits
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2017-04-12 Added recovery serial data fail. If no avg time change: lear avg buf in thread
    [MyDYLOS.py, MyThreading.py]
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2017-04-13 calibration conf def convertion deleted. Done at main level now.
2017-04-17 add file option for debugging without an Arduino
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2017-04-19 catch None values and qry failures.
    [MyDB.py]
2017-04-19 internet connectivity failure test OK
    [MyDB.py, MyDYLOS.py, MySense.py]
2017-04-26 catch Arduino serial error added
    [MyARDUINO.py]
2017-04-28 improve the catching of output stream errors
    [MySense.py]
2017-05-01 changed var names for sensors. Still scaling graph problem to be solved.
2017-05-02 Arduino needs time to reset
    [MyARDUINO.py]
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2017-05-11 various typos, small bugs resolved
    [MySDS011.py, sds011.py]
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2017-05-19 work around ias Influx write and write_points are incompatible between sub versions and Pi and Debian distributions.
    [MyINFLUXPUB.py]
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2017-06-04 Logging function uses module name. Calibration: added option to display on stdout raw measurements values.
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2017-06-07 corrected raw option check in config phase
    [MySense.py]
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2017-06-19 per sensor field: value, unit, added type of sensor
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2017-06-19 update test data to per field also sensor type
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2017-07-02 Pi3 I2C stalls I2C transfers. No workaround yet.
2017-07-03 code added to avoid warming up the Bosch chip
    [MyBME280.py]
2017-07-06 I2C Pi3 display errors workaround added.
    [MyDisplayServer.py, MySSD1306_display.py]
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2017-07-26 added sampling/interval and mode/state (fan off/on) switching explanation.
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2017-08-07 corrected log routine call for syslog
    [MyLogger.py]
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2017-08-13 improved config file error reporting
    [MySense.py]
2017-08-14 added display service activation on reboot
    [MyDisplayServer.py, MySense.py]
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2017-08-21 corrected database key in conf hash table.
    [MyINFLUXPUB.py]
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2017-08-22 how to make a box for the sensor kit
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2017-08-23 corrected poweroff syntax error
2017-08-24 added switch cmd: 20 sec poweroff, 10 secs reboot, 5 sec WiFi WPS search.
2017-08-29 corrected Sensor table creation. Added standalone test possibility.
    [MyDB.py]
2017-08-29 disable audio on too many analogue read errors.
    [MyDBGROVE.py]
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2017-08-31 corrected field size for pm1, pm0.3 and pm0.5.
    [MyDB.py]
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2017-09-01 improved check on DHT read errors
    [MyDHT.py]
2017-09-02 log consistant DHT read errors
    [MyDHT.py]
2017-09-03 more checks on DHT failures
    [MyDHT.py]
2017-09-04 script now supports new internet device names policy
2017-09-05 added tips/tricks on second serial and USB power consumption
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2017-09-13 omit nan values in error log
    [MyRAW.py]
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2017-09-18 default: search influx for kits and sensors with values in the period
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2017-12-16 missing columns auto configure, column/field names caching added
    [MyDB.py]
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2018-01-01 added support for sensor node serial nr may be defined externaly
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2018-01-04 building a LoRa Marvin sensor kit with SDS011 and DHT22
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2018-01-11 correction of python V2 date/time parsing problem
    [MyTTN_MQTT.py]
2018-01-16 try to reconnect if conmection is failing added
    [MyTTN_MQTT.py]
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2018-01-22 avoid output to Luftdaten if data is read from file
    [MyTTN_MQTT.py]
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2018-03-28 turn meteo or dust sense value calibration on or off remotely
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2018-04-02 avoid threading mem problems
    [MySense.py]
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2018-04-06 freed 2 oled spi pins for I2C sensors need. LoRa pins are full LoRa now.
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2018-04-14 improved to avoid to much updates of Meta info
    [MyDB.py]
2018-04-15 removed stupod TTN bug in script
    [MyTTN_MQTT.py]
2018-04-16 fixed small script error
    [MySense.py]
2018-04-16 SPI oled problem with new PyCom firmware
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2018-04-25 correction in pack algorithm
    [MySense.py]
2018-04-26 corrected TZ handling in Python2
    [MyTTN_MQTT.py]
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2018-05-04 added new BME680 driver and wrapper for this driver
2018-05-08 new: Spec sensors O3, NO2, CO integration in MySense
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2018-05-19 solved bug on float check
    [MyRAW.py]
2018-05-19 Spec gas beta operational issues
    [MySPEC.py, MySense.py]
2018-05-24 added avg calculation on getRecord. Support for more pf same gas sensor
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2018-05-26 Spec improvements for serial failures
    [MySPEC.py, MySense.py]
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2018-05-30 added support for temp/hum/press in eg gas sensor calculation towards ug/m3
2018-05-31 show starting up sensor thread on oled display
2018-06-22 location poweroff button handling corrected
2018-06-23 corrected Yellow/Blue type of oled handling
    [MyDisplayServer.py, MySSD1306_display.py]
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2018-07-17 new: filter out mechanism of outliers in measurements
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2018-08-01 added support to show correction factor for PM sensor
2018-08-29 increased decimals van values to fix geolocation
    [MyDB.py]
2018-09-01 solved multiple gas sensors by added short sleep to chance thread.
    [MySPEC.py]
2018-09-06 try out to find work around GPIO TTL Pi problems
    [MySPEC.py]
2018-09-08 some solutions to avoid read errors on USB connected sensors
2018-09-25 added info on USB expansion board help on Debian OS
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2018-10-04 TTN raw field port 3 bug resolved
    [MyTTN_MQTT.py]
2018-10-17 resolved info package bug.
    [MySense.py]
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2018-10-21 catch unexpected I2C bus errors
2018-10-22 add patch for I2C bus error on LoPy-4 1.18.0.r1 firmware
    [MySense.py]
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2018-10-31 corrected, added wiring instructions
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2018-11-01 corrected wiring instructions.
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2018-11-08 report uart errors
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2019-01-25 solved empty text line bug
    [MySSD1306_display.py]
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2019-02-03 corrected wiring color and PCB piun assignments, activated auto uart search
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2019-02-15 improved debugging support, automated device detection and bus detection, prepared for solarcel support
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2019-03-16 I2C chip id support. Resolved missing GPS bug.
    [MySense.py]
2019-03-17 first implementation of I2C pwr I2C control. Should allow less energy use.
2019-03-18 improved I2C bus error handling
2019-03-18 SSD1306 causes trouble on not gnded bus, so no full automated recognition of empower bus.
2019-03-26 fixed bug in exception handling
    [MySense.py]
2019-03-28 resolved bug in initMeteo BME280 handling
    [MySense.py]
2019-05-01 resolved typos withy pending deepsleep tests. To test: ttl devs, run loop
    [MySense.py]
2019-05-03 fixed uart allocation and use bug
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2019-05-06 corrections from alpha tests
    [MySense.py]
2019-05-06 Dust dict error resolved
    [MySense.py]
2019-05-16 bugs from alpha test resolved. GPS Dexter bug resolved.
    [MySense.py]
2019-05-17 bug integration test resolved. Still LoRa errors
    [MySense.py]
2019-05-18 resolved thread and small meteo bug.
    [MySense.py]
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2019-05-22 bugs with SPS30. SPS driver still not ok
2019-05-22 various bug fixing. Ready for regressie test
    [MySense.py]
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2019-05-26 corrected Pins -> Pin
    [main.py]
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2019-05-27 corrected typo in SPS30 lib name
    [MySense.py]
2019-05-27 fixes shown up at regression/integration tests
    [MySense.py]
2019-05-30 avoid store null GPS coordinates
    [MySense.py]
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2019-05-31 nwe fie: nvs variable "modus": 0 (dflt) cold boot reset flash config/nvsram, 1 reset devices config, 2 not reset.
    [MySense.py]
2019-06-01 solved spurious false configuration update
    [MySense.py]
2019-06-04 MySense.runMe() Display var corrected.
    [MySense.py]
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2019-06-04 Mysense.PowerPin() corrected missing Pwr pin handling
    [MySense.py]
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2019-06-19 corrected accu/wind device decode part
    [TTN-decode.js]
2019-06-25 check PyCom expansion board on pin values to avoid LoRa activation
    [main.py]
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2019-07-14 resolved/work around interpreter problem with max(), min(), len()
    [MySense.py]
2019-07-16 Resolved Config interval bug. Added some debug status info for deepsleep
    [MySense.py]
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2019-07-22 workaround on deepsleep wakeup failure
    [main.py]
2019-07-22 improved workaround on deepsleep failure
    [main.py]
2019-07-22 on failure do a cold reboot
    [main.py]
2019-07-28 MySense failure catcher added.
    [main.py]
2019-08-05 small improvements in sensor routine return value on failure
    [MySense.py]
2019-08-08 resolved cold boot Alarm event bug
    [MySense.py]
2019-08-14 try to cure deepsleep failure with explicit turn off power on TTL devices
    [MySense.py]
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2019-08-19 added MyReset() to enable remote reset as well cleanup MySense state
    [MySense.py]
2019-08-24 runMe() loop has argument to reset/clear LoPy. Dflt false.
    [MySense.py]
2019-08-25 added work around ESP deepsleep NO WAKE UP problem. Not confirmed if this solves the problem.
    [main.py]
2019-08-29 corrected pHa to hPa
    [MySense.py]
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2019-09-23 rgb led color change on no GPS fixate iso display print
    [MySense.py]
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2019-11-04 3D print samples, motherboard sample and new outside housing example
    [GPS tafel a.stl, Oled inw b.stl, Oled buiten nieuw uitw c.stl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]
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2020-02-16 force longer deepsleep on very low accu level. Resolved empty accu bug.
    [main.py]
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2020-03-11 resolved wifi shut off bug. Improved error display. Avoid too many json writes.
    [MySense.py]
2020-03-12 GPS error exception resolved (display prt argument)
    [MySense.py]
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2020-04-02 wifi will also be turned off with deepsleep and wifi power off.
2020-04-03 problem with output to Luftdaten solved.
    [MyLUFTDATEN.py]
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2020-04-23 new 3D prining parts housing of the kit
    [Oled inw 2.1.stl, Oled inw 2.stl, houder mb j.stl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]
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2020-05-05 solved small bugs. Improvements handling DB cache and warnings dead measurement kits.
    [MyDB.py]
2020-05-09 monitor print statement bug resolved.
2020-05-17 Handle Luftdaten timeout errors better to improve input bandwidth better.
    [MyLUFTDATEN.py]
2020-05-18 avoid DB updates with guesses sensors HW info.
    [MyDB.py]
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2020-05-23 madavi.de raises http 403 errors last 2days. Changed error handling per Luftdaten or Madavi to stop further postages and do a retry every once and while.
    [MyDB.py, MyLUFTDATEN.py]
2020-05-26 madavi.de seems not to accept POSTs anymore. Delay to recheck is now 2 days.
2020-05-27 improved luftdaten/madavi handling to provide more deeper info on failures and retry handling
    [MyLUFTDATEN.py]
2020-05-29 Luftdaten does not support empy data fields. Now checked for. db_table ident problem solved.
    [MyDB.py, MyLUFTDATEN.py]
2020-05-31 initiate script to update MySQL sensors table for address items via reverse GPS
    [MyGPS.py]
2020-06-01 Luftdaten POST format improved. Less failures now.
    [MyLUFTDATEN.py]
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2020-10-05 awfull hack to avoid blanks in Luftdaten graphs
    [MyLUFTDATEN.py]
2020-10-26 solved SHT31 init problem
    [MySense.py]
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2021-01-09 explanation added to use test scripts for device driver and device configuration tests
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2021-01-30 small log print bug solved.
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2021-03-22 bug in help option printout solved
2021-05-08 added graph correction to reference sensor manufacturer type.
2021-05-11 lib module for dust sensor type corrections
2021-05-11 added description of sensor type correction tool
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2021-11-03 bvug threading resolved
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2021-11-11 use multithreading/queue mechanism to avoid delays to Sensors.Community
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2022-02-06 changed INSERT to REPLACE SQL instruction
2024-09-07 Added sensor status first/last timestamp and record count for eaqcht municipality station.
2025-02-19 Add files via upload
    real life output example files generated via scripts Things2HTML.py and Things2XLSX.py.
    [Land van Cuijk.xlsx]
2025-02-19 real life example files for html,xlsx, and csv
    added real life generated example files from Things2(XLSX,HTML,CSV).py scripts.
    [test-stations.csv]
2025-04-07 timezone problem CEST not recognized workaround. Expect sensor types not included in CSV file.
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2026-03-21 casus Horst aan de Maas, Leidschendam
    Bedoeld als voorbeeld. Zal inhoudelijk nog veranderen.
2026-03-21 some bugs resolved, improve thread timeout handling
2026-03-28 new Overview statistics spreadsheet
    Spreadsheet has sheets with statistical info about low-cost Airquality measurements stations in Nld.
    Sheets are per municipality: IJmon region, Gouda, Leiden, Leidschendam-Voorburg, Venray, Peel en Maas and Horst aan de Maas
    [SLA-cases-Overzicht-Meetpunten.ods]
2026-03-29 update with Nrd Limburg regions
    Added Venray, Peel en Maas and Horst aan de Maas overviews on one sheet
    [SLA-cases-Overzicht-Meetpunten.ods]
2026-03-29 final Casus Horst aan de Maas
    Beschrijving casus Horst aan de Maas (MySense) voor besprekingen SLA Brandbrief bijeenkomsten
2026-03-29 new Casus Horst aan de Maas
    Casus Horst aan de Maas (MySense) description for SLA Brandbrief meetings
2026-04-05 styling updates
    [SLA-cases-Overzicht-Meetpunten.ods]
2026-04-15 style improvements, added sheets
    solved some styling issues.
    Added some municipalities overviews.
    [SLA-cases-Overzicht-Meetpunten.ods]
2026-04-19 update municipality Zaandam
    Zaandam overview added to spreadsheet
    [SLA-cases-Overzicht-Meetpunten.ods]
2026-05-09 final presentation SLA Brandbrief
    Case Horst aan de Maas and Land van Cuijk
    why Openletter is written
    arguments, conclusions and advise for actions to be taken
2026-09-01 Dag van Schone Lucht, pitch Teus Hagen, MySense
    Korte presentatie met ervaringen burger participatie en Citizen Science tav Schone Lucht accoord en lokale overheden (beleid, maatregelen) tav lucht kwaliteitsmetingen en data analyses cq meetrapport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
    Dag van Schone Lucht, thema burger participatie
    7 september 2026, Den Bosch
2026-09-01 final full presentation pitch teus, Dag van Schone Lucht
    final versie, kompleet met extra naslag werk refs, extra info over aantal operationele meters over recente jaren voor aantal gemeenten.

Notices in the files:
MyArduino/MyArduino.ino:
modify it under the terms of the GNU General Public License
